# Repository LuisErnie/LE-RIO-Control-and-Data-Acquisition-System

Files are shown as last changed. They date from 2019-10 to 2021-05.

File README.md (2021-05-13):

# Industrial Control and Data Acquisition System

LOW-level Engineering modular data acquisition and control hardware platform. The system is a combination of a power supply, integrated I/O, integrated communications interfaces, signal and isolation to interface with expansion modules to tailor it to the application and an FPGA as a main controller.

The system is designed around the DE-10 Nano FPGA board from Terasic, although any embedded controller can be adapted to interface with the two 40-pin IDC connectors.

## Features
- Fully Modular I/O interface.
- Expansion Ports with 24V and 5V Power and Signal Isolation.
- Single 24V Power Supply Required.
- Multiple Communications Interfaces Supported, RS-485, CAN, RS-232, USB, SPI and I2C.

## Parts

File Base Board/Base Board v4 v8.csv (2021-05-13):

Qty | Value | Device | Package | Parts | Description | BUILT_BY | CATEGORY | COLOR | COPYRIGHT | CREATED_BY | DATASHEET | DATASHEET-URL | DESCRIPTION | DIGI-KEY_PART_NUMBER | DIGIKEY_PARTNO | DIGIKEY_PN | GENDER | HEIGHT | IR | IR-UL | IR-VDE | MANUFACTURER | MANUFACTURER_NAME | MANUFACTURER_PART_NUMBER | MATES | MF | MOUNT | MOUSER_PART_NUMBER | MP | MPN | OPERATING_TEMP | PACKAGE | PACKAGING | PART-NUMBER | PART_STATUS | PINS | PITCH | POPULARITY | PURCHASE-URL | RATING | ROHS_COMPLIANT | ROWS | SERIES | SOURCELIBRARY | SUB-CATEGORY | THERMALLOSS | TOLERANCE | TP_SIGNAL_NAME | TYPE | VALUE | VENDOR | VOLTAGE_RATING | WORKING-VOLTAGE-UL | WORKING-VOLTAGE-VDE
1 |  | 6130XX21821_61301621821 | 61301621821 | JP4 | WR-PHD 2.54 mm Dual Socket Header |  |  |  |  |  |  | https://katalog.we-online.com/em/datasheet/61301621821.pdf |  |  |  |  | Socket Header |  | 3A |  |  |  |  |  | WR-PHD 2.54mm SMT Dual Pin Header/THT Angled Dual Pin Header/THT Dual Board Stacker/THT Dual Pin Header |  |  |  |  |  |  |  | Tray | 61301621821 |  | 16 |  |  |  |  |  | Dual |  |  |  |  |  |  | Straight
1 |  | 6130XX21821_61302021821 | 61302021821 | JP5 | WR-PHD 2.54 mm Dual Socket Header |  |  |  |  |  |  | https://katalog.we-online.com/em/datasheet/61302021821.pdf |  |  |  |  | Socket Header |  | 3A |  |  |  |  |  | WR-PHD 2.54mm SMT Dual Pin Header/THT Angled Dual Pin Header/THT Dual Board Stacker/THT Dual Pin Header |  |  |  |  |  |  |  | Tray | 61302021821 |  | 20 |  |  |  |  |  | Dual |  |  |  |  |  |  | Straight
1 |  | 691313710002 | 691313710002 | J2 | WR-TBL Serie 3137 - 5.00 mm Close Horizontal PCB Header |  |  |  |  |  |  | https://www.we-online.com/catalog/datasheet/691313710002.pdf |  |  |  |  |  |  |  | 20A | 20A |  |  |  |  |  | THT |  |  |  |  |  |  | 691313710002 |  | 2 | 5mm |  |  |  |  |  |  |  |  |  |  |  | Horizontal |  |  |  | 300V (AC) | 300V (AC)
2 |  | PINHD-2X20 | 2X20 | JP1, JP2 | PIN HEADER |  |  |  |  |  |  |  |  |  |  |  |  |  |  |  |  |  |  |  |  |  |  |  |  |  |  |  |  |  |  |  |  | 12
1 |  | PINHD-2X22/90 | 2X22/90 | JP6 | PIN HEADER |  |  |  |  |  |  |  |  |  |  |  |  |  |  |  |  |  |  |  |  |  |  |  |  |  |  |  |  |  |  |  |  | 0
1 |  | TEL_5_SERIES | TEL_5_SERIES | IC2 | TRACO POWER DC/DC converter TEL 5 Series created by Mario Blunk - electronics & IT engineering at www.train-z.de
2 | 0.01uF | C-US_CHIP-0805(2012-METRIC) | CAPC2012X110 | C12, C14 | Capacitor - ANSI |  | Capacitor
17 | 0.1uF | C-US_CHIP-0805(2012-METRIC) | CAPC2012X110 | C4, C5, C6, C7, C8, C11, C13, C16, C17, C18, C19, C20, C21, C24, C25, C26, C27 | Capacitor - ANSI |  | Capacitor
1 | 01530008Z | 01530008Z | 01530008Z | F1 | FUSE HOLDER BLADE 32V 15A PCB |  |  |  |  | PCBLayout.com |  |  |  |  | F065-ND |  |  |  |  |  |  | Littelfuse Inc. |  |  |  |  |  |  |  | 01530008Z
10 | 10k | R-US_CHIP-0805(2012-METRIC) | RESC2012X65 | R2, R3, R4, R5, R6, R7, R8, R9, R10, R11 | Resistor Fixed - ANSI |  | Resistor |  |  |  |  |  |  |  |  |  |  |  |  |  |  |  |  |  |  |  |  |  |  |  |  |  |  |  |  |  |  |  |  |  |  |  |  |  | Fixed
1 | 11.8K | R-US_CHIP-0805(2012-METRIC) | RESC2012X65 | R1 | Resistor Fixed - ANSI |  | Resistor |  |  |  |  |  |  |  |  |  |  |  |  |  |  |  |  |  |  |  |  |  |  |  |  |  |  |  |  |  |  |  |  |  |  |  |  |  | Fixed
2 | 1uF | C-US_CHIP-0805(2012-METRIC) | CAPC2012X110 | C2, C3 | Capacitor - ANSI |  | Capacitor
1 | 2.2mF | C-US_CHIP-0805(2012-METRIC) | CAPC2012X110 | C1 | Capacitor - ANSI |  | Capacitor
2 | 22pF | C-US_CHIP-0805(2012-METRIC) | CAPC2012X110 | C9, C10 | Capacitor - ANSI |  | Capacitor
1 | 2k | R-US_CHIP-0805(2012-METRIC) | RESC2012X65 | R13 | Resistor Fixed - ANSI |  | Resistor |  |  |  |  |  |  |  |  |  |  |  |  |  |  |  |  |  |  |  |  |  |  |  |  |  |  |  |  |  |  |  |  |  |  |  |  |  | Fixed
1 | 5032/2P 16MHz | 5032/2P | 5032/2P | X1 | Crystal |  |  |  |  | PCBLayout.com |  |  |  |  |  |  |  |  |  |  |  | Xinhunjing |  |  |  |  |  |  |  | 5032/2P |  | SMD
2 | 50E | R-US_CHIP-0805(2012-METRIC) | RESC2012X65 | R14, R15 | Resistor Fixed - ANSI |  | Resistor |  |  |  |  |  |  |  |  |  |  |  |  |  |  |  |  |  |  |  |  |  |  |  |  |  |  |  |  |  |  |  |  |  |  |  |  |  | Fixed
1 | ADM3050E | ADM3050E | SOIC127P1031X265-8N | IC15
2 | ADUM1250 | ADUM1250 | SOIC127P600X175-8N | IC7, IC8
1 | ADUM140E | ADUM140E | SOP65P599X175-16N | IC11
2 | ADUM141E | ADUM141E | SOP65P599X175-16N | IC9, IC10
2 | ADUM3153 | ADUM3153 | SOP65P780X200-20N | IC5, IC6
1 | BS-7 | BS-7 | BAT_BS-7 | BT1 | BATTERY HOLDER COIN 20MM PC PIN |  |  |  |  |  |  |  | BATTERY HOLDER COIN 20MM PC PIN | BS-7-ND |  |  |  |  |  |  |  |  |  |  |  | MPD (Memory |  |  | BS-7 |  |  | None |  |  |  |  |  |  | https://pricing.snapeda.com/search/part/BS-7/?ref=eda
1 | DS3231 | DS3231 | SOIC127P1032X265-16N | IC4
2 | G6L-1F-TRDC12 | G6L-1F-TRDC12 | G6L-1F-TRDC12 | K1, K2 | RELAY TELECOM SPST 1A 12VDC |  |  |  |  | PCBLayout.com |  |  |  |  |  | Z3549TR-ND |  |  |  |  |  | Omron Electronics Inc-EMC Div |  |  |  |  |  |  |  | G6L-1F-TRDC12
1 | MCP2518FD | MCP2518FD | SOIC127P600X175-14N | IC1
4 | MOUNT-PAD-ROUND3.2 | MOUNT-PAD-ROUND3.2 | 3,2-PAD | H1, H2, H3, H4 | MOUNTING PAD, round |  |  |  |  |  |  |  |  |  |  |  |  |  |  |  |  |  |  |  |  |  |  |  |  |  |  |  |  |  |  |  |  | 4
1 | PESD1CAN | PESD1CAN | SOT23 | D1 | CAN bus ESD protection diode |  |  |  |  |  |  |  |  |  |  |  |  |  |  |  |  |  |  |  |  |  |  |  |  |  |  |  |  |  |  |  |  | 0
1 | R_0805 | CHIP-ROUND-R_0805 | LEDC2012X105N_RND-R | D10 | LED - Generic |  | LED | RED |  |  |  |  | CHIP LED ROUND |  |  |  |  |  |  |  |  |  |  |  |  |  |  |  |  |  |  |  |  |  |  |  |  |  |  |  |  |  |  |  | CHIP |  |  |  | ROUND_TOP
1 | TL2285EE | TL2285EE | TL2285EE | S1 | Tactile Switches DPDT ALT ACT PC MNT |  |  |  |  |  |  |  | Tactile Switches DPDT ALT ACT PC MNT |  |  |  |  | 13mm |  |  |  |  | E-Switch | TL2285EE |  |  |  | 612-TL2285EE
73 | TPB1,27 | TPB1,27 | B1,27 | 3V3, 5V, 5V_IN, 24V, 24V_IN, A_CLK_ISO, A_CS_ISO, A_CS_MUX_A_ISO, A_CS_MUX_B_ISO, A_CS_MUX_C_ISO, A_MISO_ISO, A_MOSI_ISO, BAT, B_CLK_ISO, B_CS_ISO, B_CS_MUX_A_ISO, B_CS_MUX_B_ISO, B_CS_MUX_C_ISO, B_MISO_ISO, B_MOSI_ISO, CAN_H, CAN_L, CAN_RX, CAN_TX, CTRL_A_ISO, CTRL_B_ISO, CTRL_C_ISO, CTRL_D_ISO, EE_SCL, EE_SCL_ISO, EE_SDA, EE_SDA_ISO, FAULT_A_ISO, FAULT_B_ISO, FAULT_C_ISO, GND, GNDA, GND_BAT, INT_A_ISO, INT_B_ISO, INT_C_ISO, RTC_SCL, RTC_SDA, SCL, SCL_ISO, SDA, SDA_ISO, SPIA_CLK, SPIA_CS, SPIA_CS_MUX_A, SPIA_CS_MUX_B, SPIA_CS_MUX_C, SPIA_MISO, SPIA_MOSI, SPIB_CLK, SPIB_CS, SPIB_CS_MUX_A, SPIB_CS_MUX_B, SPIB_CS_MUX_C, SPIB_MISO, SPIB_MOSI, SPI_BUS_CTRL_A, SPI_BUS_CTRL_B, SPI_BUS_CTRL_C, SPI_BUS_CTRL_D, SPI_FAULT_A, SPI_FAULT_B, SPI_FAULT_C, SPI_INT_A, SPI_INT_B, SPI_INT_C, VCC, VDD | Test pad |  |  |  |  |  |  |  |  |  |  |  |  |  |  |  |  |  |  |  |  |  |  |  |  |  |  |  |  |  |  |  |  | 19
1 | TPS26600 | TPS26600 | SOP65P640X120-17T266X246N | IC3
1 | TSR_2-2450 | TSR_2-2450 | TSR2-SINGLE_TRP | IC16 |  | EMA_Justin |  |  | Copyright (C) 2018 Accelerated Designs. All rights reserved |  | https://www.tracopower.com/products/tsr2.pdf |  |  |  |  |  |  |  |  |  |  |  |  | TSR 2-2450 |  |  |  |  |  |  |  |  |  |  |  |  |  |  |  |  |  |  |  | Traco_Power_2020-06-03 |  |  |  |  |  |  | Traco Power

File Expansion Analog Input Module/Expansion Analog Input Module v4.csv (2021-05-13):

Qty | Value | Device | Package | Parts | Description | BREAKDOWN_VOLTAGE | CATEGORY | CLAMPING_VOLTAGE | COLOR | CURRENT_RATING | DATASHEET-URL | DESCRIPTION | IR-UL | MANUFACTURER | MOUNT | MPN | OPERATING_TEMP | PART-NUMBER | PART_STATUS | PINS | PITCH | POLES | POPULARITY | QTY | RATING | ROHS_COMPLIANT | SERIES | SUB-CATEGORY | THERMALLOSS | TOLERANCE | TP_SIGNAL_NAME | TYPE | VALUE | VOLTAGE_RATING | WIRE | WORKING-VOLTAGE-UL
1 |  | 418121270802 | 418121270802 | S1 | WS-DISV Small Compact SMT with Raised Actuator 2.54 mm |  |  |  |  |  | https://www.we-online.com/catalog/datasheet/418121270802.pdf |  |  |  |  |  |  | 418121270802 |  | 2 |  |  |  | 800
3 |  | 691402910002B | 691402910002B | J3, J4, J5 | WR-TBL Serie 4029 - 2.54 mm Screwless Horizontal Entry |  |  |  |  |  | https://www.we-online.com/catalog/datasheet/691402910002B.pdf |  | 6A |  | THT |  |  | 691402910002B |  | 2 | 2.54mm |  |  |  |  |  |  |  |  |  |  | Horizontal |  |  | 20 to 26 (AWG) 0.518 to 0.129 (mm²) | 150V (AC)
1 |  | 691402910008B | 691402910008B | J2 | WR-TBL Serie 4029 - 2.54 mm Screwless Horizontal Entry |  |  |  |  |  | https://www.we-online.com/catalog/datasheet/691402910008B.pdf |  | 6A |  | THT |  |  | 691402910008B |  | 8 | 2.54mm |  |  |  |  |  |  |  |  |  |  | Horizontal |  |  | 20 to 26 (AWG) 0.518 to 0.129 (mm²) | 150V (AC)
1 |  | WE-D-SUB_THT90_EC_214112013 | WE-D-SUB_THT90_EC_214112013 | J1 | WE-D-SUB Filter Bent 90° THT |  |  |  |  |  | https://katalog.we-online.de/pbs/datasheet/214112013.pdf |  |  |  | THT |  |  | 214112013 |  |  |  | 25 |  |  |  |  |  |  |  |  |  | Male
2 | 0.1uF | C-US_CHIP-0805(2012-METRIC) | CAPC2012X110 | C1, C6 | Capacitor - ANSI |  | Capacitor
1 | 10k | R-US_CHIP-0805(2012-METRIC) | RESC2012X65 | R9 | Resistor Fixed - ANSI |  | Resistor |  |  |  |  |  |  |  |  |  |  |  |  |  |  |  |  |  |  |  |  | Fixed
1 | 1uF | C-US_CHIP-0805(2012-METRIC) | CAPC2012X110 | C2 | Capacitor - ANSI |  | Capacitor
1 | 24LC512TSSOP | 24LC512TSSOP | SOP65P640X120-8N | IC3
1 | 2k | R-US_CHIP-0805(2012-METRIC) | RESC2012X65 | R10 | Resistor Fixed - ANSI |  | Resistor |  |  |  |  |  |  |  |  |  |  |  |  |  |  |  |  |  |  |  |  | Fixed
8 | 4.7K | R-US_CHIP-0805(2012-METRIC) | RESC2012X65 | R1, R2, R3, R4, R5, R6, R7, R8 | Resistor Fixed - ANSI |  | Resistor |  |  |  |  |  |  |  |  |  |  |  |  |  |  |  |  |  |  |  |  | Fixed
8 | 680nF | C-US_CHIP-0805(2012-METRIC) | CAPC2012X110 | C9, C10, C11, C12, C13, C14, C15, C16 | Capacitor - ANSI |  | Capacitor
8 | FUSE | FUSE_CHIP-1206(3216-METRIC) | FUSC3215X82N | F1, F2, F3, F4, F5, F6, F7, F8 | Fuse - Generic |  | Circuit-Protection |  |  |  |  |  |  |  |  |  |  |  |  |  |  |  |  |  |  |  |  | Fuse |  |  |  |  | FUSE
1 | MCP3208 | MCP3208 | SOIC127P590X175-16N | IC1
1 | MCP4822 | MCP4822 | SOIC127P600X175-8N | IC2
2 | R_0805 | CHIP-ROUND-R_0805 | LEDC2012X105N_RND-R | D9, D10 | LED - Generic |  | LED |  | RED |  |  | CHIP LED ROUND |  |  |  |  |  |  |  |  |  |  |  |  |  |  |  | CHIP |  |  |  | ROUND_TOP
21 | TPB1,27 | TPB1,27 | B1,27 | 5V, 24V, GND, IN_1, IN_1_F, IN_2, IN_2_F, IN_3, IN_3_F, IN_4, IN_4_F, IN_5, IN_5_F, IN_6, IN_6_F, IN_7, IN_7_F, IN_8, IN_8_F, VOUT_A, VOUT_B | Test pad |  |  |  |  |  |  |  |  |  |  |  |  |  |  |  |  |  | 19
8 | TVS-DIODE | TVS_DO-214AC(SMA) | DIOM5226X290N | D1, D2, D3, D4, D5, D6, D7, D8 | TVS Diode - Generic |  | Circuit-Protection |  |  |  |  |  |  |  |  |  |  |  |  |  |  |  |  |  |  |  |  | TVS-Diode |  |  |  |  | TVS-DIODE

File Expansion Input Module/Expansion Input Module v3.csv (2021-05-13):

Qty | Value | Device | Package | Parts | Description | BREAKDOWN_VOLTAGE | CATEGORY | CLAMPING_VOLTAGE | COLOR | CURRENT_RATING | DATASHEET-URL | DESCRIPTION | IR-UL | MANUFACTURER | MOUNT | MPN | OPERATING_TEMP | PART-NUMBER | PART_STATUS | PINS | PITCH | POLES | POPULARITY | QTY | RATING | ROHS_COMPLIANT | SERIES | SUB-CATEGORY | THERMALLOSS | TOLERANCE | TP_SIGNAL_NAME | TYPE | VALUE | VOLTAGE_RATING | WIRE | WORKING-VOLTAGE-UL
1 |  | 418121270803 | 418121270803 | S1 | WS-DISV Small Compact SMT with Raised Actuator 2.54 mm |  |  |  |  |  | https://www.we-online.com/catalog/datasheet/418121270803.pdf |  |  |  |  |  |  | 418121270803 |  | 3 |  |  |  | 800
2 |  | 691402910002B | 691402910002B | J3, J4 | WR-TBL Serie 4029 - 2.54 mm Screwless Horizontal Entry |  |  |  |  |  | https://www.we-online.com/catalog/datasheet/691402910002B.pdf |  | 6A |  | THT |  |  | 691402910002B |  | 2 | 2.54mm |  |  |  |  |  |  |  |  |  |  | Horizontal |  |  | 20 to 26 (AWG) 0.518 to 0.129 (mm²) | 150V (AC)
1 |  | 691402910008B | 691402910008B | J2 | WR-TBL Serie 4029 - 2.54 mm Screwless Horizontal Entry |  |  |  |  |  | https://www.we-online.com/catalog/datasheet/691402910008B.pdf |  | 6A |  | THT |  |  | 691402910008B |  | 8 | 2.54mm |  |  |  |  |  |  |  |  |  |  | Horizontal |  |  | 20 to 26 (AWG) 0.518 to 0.129 (mm²) | 150V (AC)
3 |  | R-US_CHIP-0805(2012-METRIC) | RESC2012X65 | R9, R10, R11 | Resistor Fixed - ANSI |  | Resistor |  |  |  |  |  |  |  |  |  |  |  |  |  |  |  |  |  |  |  |  | Fixed
1 |  | WE-D-SUB_THT90_EC_214112013 | WE-D-SUB_THT90_EC_214112013 | J1 | WE-D-SUB Filter Bent 90° THT |  |  |  |  |  | https://katalog.we-online.de/pbs/datasheet/214112013.pdf |  |  |  | THT |  |  | 214112013 |  |  |  | 25 |  |  |  |  |  |  |  |  |  | Male
1 | 0.1uF | C-US_CHIP-0805(2012-METRIC) | CAPC2012X110 | C6 | Capacitor - ANSI |  | Capacitor
1 | 10k | R-US_CHIP-0805(2012-METRIC) | RESC2012X65 | R14 | Resistor Fixed - ANSI |  | Resistor |  |  |  |  |  |  |  |  |  |  |  |  |  |  |  |  |  |  |  |  | Fixed
1 | 24LC512TSSOP | 24LC512TSSOP | SOP65P640X120-8N | IC2
9 | 2k | R-US_CHIP-0805(2012-METRIC) | RESC2012X65 | R15, R16, R17, R18, R19, R20, R21, R22, R23 | Resistor Fixed - ANSI |  | Resistor |  |  |  |  |  |  |  |  |  |  |  |  |  |  |  |  |  |  |  |  | Fixed
8 | 4.7K | R-US_CHIP-0805(2012-METRIC) | RESC2012X65 | R1, R2, R3, R4, R5, R6, R7, R8 | Resistor Fixed - ANSI |  | Resistor |  |  |  |  |  |  |  |  |  |  |  |  |  |  |  |  |  |  |  |  | Fixed
8 | 680nF | C-US_CHIP-0805(2012-METRIC) | CAPC2012X110 | C9, C10, C11, C12, C13, C14, C15, C16 | Capacitor - ANSI |  | Capacitor
2 | CRA034RF | CRA034RF | RESCAXS80P320X160X60-8N | R12, R13
8 | FUSE | FUSE_CHIP-1206(3216-METRIC) | FUSC3215X82N | F1, F2, F3, F4, F5, F6, F7, F8 | Fuse - Generic |  | Circuit-Protection |  |  |  |  |  |  |  |  |  |  |  |  |  |  |  |  |  |  |  |  | Fuse |  |  |  |  | FUSE
1 | MCP23S17 | MCP23S17 | SOP65P780X200-28N | IC1
10 | R_0805 | CHIP-ROUND-R_0805 | LEDC2012X105N_RND-R | D9, D10, D11, D12, D13, D14, D15, D16, D17, D18 | LED - Generic |  | LED |  | RED |  |  | CHIP LED ROUND |  |  |  |  |  |  |  |  |  |  |  |  |  |  |  | CHIP |  |  |  | ROUND_TOP
19 | TPB1,27 | TPB1,27 | B1,27 | 5V, 24V, GND, IN_1, IN_1_F, IN_2, IN_2_F, IN_3, IN_3_F, IN_4, IN_4_F, IN_5, IN_5_F, IN_6, IN_6_F, IN_7, IN_7_F, IN_8, IN_8_F | Test pad |  |  |  |  |  |  |  |  |  |  |  |  |  |  |  |  |  | 19
8 | TVS-DIODE | TVS_DO-214AC(SMA) | DIOM5226X290N | D1, D2, D3, D4, D5, D6, D7, D8 | TVS Diode - Generic |  | Circuit-Protection |  |  |  |  |  |  |  |  |  |  |  |  |  |  |  |  |  |  |  |  | TVS-Diode |  |  |  |  | TVS-DIODE

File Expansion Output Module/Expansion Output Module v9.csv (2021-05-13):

Qty | Value | Device | Package | Parts | Description | CATEGORY | COLOR | DATASHEET-URL | DESCRIPTION | IR-UL | MANUFACTURER | MOUNT | MPN | OPERATING_TEMP | PART-NUMBER | PART_STATUS | PINS | PITCH | POLES | POPULARITY | QTY | RATING | ROHS_COMPLIANT | SERIES | SUB-CATEGORY | THERMALLOSS | TOLERANCE | TP_SIGNAL_NAME | TYPE | VALUE | VOLTAGE_RATING | WIRE | WORKING-VOLTAGE-UL
1 |  | 418121270803 | 418121270803 | IC1 | WS-DISV Small Compact SMT with Raised Actuator 2.54 mm |  |  | https://www.we-online.com/catalog/datasheet/418121270803.pdf |  |  |  |  |  |  | 418121270803 |  | 3 |  |  |  | 800
2 |  | 691402910002B | 691402910002B | J5, J6 | WR-TBL Serie 4029 - 2.54 mm Screwless Horizontal Entry |  |  | https://www.we-online.com/catalog/datasheet/691402910002B.pdf |  | 6A |  | THT |  |  | 691402910002B |  | 2 | 2.54mm |  |  |  |  |  |  |  |  |  |  | Horizontal |  |  | 20 to 26 (AWG) 0.518 to 0.129 (mm²) | 150V (AC)
2 |  | 691402910008B | 691402910008B | J1, J2 | WR-TBL Serie 4029 - 2.54 mm Screwless Horizontal Entry |  |  | https://www.we-online.com/catalog/datasheet/691402910008B.pdf |  | 6A |  | THT |  |  | 691402910008B |  | 8 | 2.54mm |  |  |  |  |  |  |  |  |  |  | Horizontal |  |  | 20 to 26 (AWG) 0.518 to 0.129 (mm²) | 150V (AC)
1 |  | WE-D-SUB_THT90_EC_214112013 | WE-D-SUB_THT90_EC_214112013 | J3 | WE-D-SUB Filter Bent 90° THT |  |  | https://katalog.we-online.de/pbs/datasheet/214112013.pdf |  |  |  | THT |  |  | 214112013 |  |  |  | 25 |  |  |  |  |  |  |  |  |  | Male
1 | 0.1uF | C-US_CHIP-0805(2012-METRIC) | CAPC2012X110 | C6 | Capacitor - ANSI | Capacitor
4 | 10k | R-US_CHIP-0805(2012-METRIC) | RESC2012X65 | R1, R9, R10, R11 | Resistor Fixed - ANSI | Resistor |  |  |  |  |  |  |  |  |  |  |  |  |  |  |  |  |  |  | Fixed
1 | 24LC512TSSOP | 24LC512TSSOP | SOP65P640X120-8N | IC4
9 | 2k | R-US_CHIP-0805(2012-METRIC) | RESC2012X65 | R2, R3, R4, R5, R6, R7, R8, R14, R15 | Resistor Fixed - ANSI | Resistor |  |  |  |  |  |  |  |  |  |  |  |  |  |  |  |  |  |  | Fixed
2 | CRA034RF | CRA034RF | RESCAXS80P320X160X60-8N | R12, R13
1 | MCP23S17 | MCP23S17 | SOP65P780X200-28N | IC2
8 | PE10 | PE10 | PE-FORM-A | K1, K2, K3, K4, K5, K6, K7, K8 | SLIM POWER Relay NAiS
10 | R_0805 | CHIP-ROUND-R_0805 | LEDC2012X105N_RND-R | D1, D2, D3, D4, D5, D6, D7, D8, D9, D10 | LED - Generic | LED | RED |  | CHIP LED ROUND |  |  |  |  |  |  |  |  |  |  |  |  |  |  |  | CHIP |  |  |  | ROUND_TOP
11 | TPB1,27 | TPB1,27 | B1,27 | 5V, 24V, GND, OUT_1, OUT_2, OUT_3, OUT_4, OUT_5, OUT_6, OUT_7, OUT_8 | Test pad |  |  |  |  |  |  |  |  |  |  |  |  |  |  | 19
1 | ULN2803 | ULN2803 | SOIC127P1030X265-18N | IC5

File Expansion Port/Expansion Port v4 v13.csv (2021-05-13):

Qty | Value | Device | Package | Parts | Description | CATEGORY | COLOR | CRAETED_BY | DATASHEET-URL | DESCRIPTION | DIGIKEY_PART_NUMBER | MANUFACTURER | MOUNT | MPN | OPERATING_TEMP | PACKAGE | PART-NUMBER | PART_STATUS | POLES | POPULARITY | RATING | ROHS_COMPLIANT | SERIES | SUB-CATEGORY | THERMALLOSS | TOLERANCE | TP_SIGNAL_NAME | TYPE | VALUE | VOLTAGE_RATING
1 |  | PINHD-2X222X22/90 | HDRRAR44W64P254_2X22_5588X736X556B | JP1 | WR-PHD 2.54 mm Dual Socket Header
1 |  | PINHD-2X3 | 2X03 | JP2 | PIN HEADER |  |  |  |  |  |  |  |  |  |  |  |  |  |  | 62
8 |  | WE-D-SUB_THT_TH_214611003 | WE-D-SUB_THT_TH_214611003 | J1, J2, J3, J4, J5, J6, J7, J8 | WE-D-SUB Filter Solder Pin Straight |  |  |  | https://katalog.we-online.de/pbs/datasheet/214611003.pdf |  |  |  | THT |  |  |  | 214611003 |  | 25 |  |  |  |  |  |  |  |  | Female
22 | 0.1uF | C-US_CHIP-0805(2012-METRIC) | CAPC2012X110 | C1, C2, C4, C5, C6, C7, C8, C9, C10, C11, C12, C13, C14, C15, C16, C17, C18, C19, C20, C21, C22, C23 | Capacitor - ANSI | Capacitor
2 | 10k | R-US_CHIP-0805(2012-METRIC) | RESC2012X65 | R9, R10 | Resistor Fixed - ANSI | Resistor |  |  |  |  |  |  |  |  |  |  |  |  |  |  |  |  |  | Fixed
8 | 2.2K | R-US_CHIP-0805(2012-METRIC) | RESC2012X65 | R1, R2, R3, R4, R5, R6, R7, R8 | Resistor Fixed - ANSI | Resistor |  |  |  |  |  |  |  |  |  |  |  |  |  |  |  |  |  | Fixed
1 | 2k | R-US_CHIP-0805(2012-METRIC) | RESC2012X65 | R11 | Resistor Fixed - ANSI | Resistor |  |  |  |  |  |  |  |  |  |  |  |  |  |  |  |  |  | Fixed
1 | 4700pF | C-US_CHIP-0805(2012-METRIC) | CAPC2012X110 | C3 | Capacitor - ANSI | Capacitor
2 | 60.4 | R-US_CHIP-0805(2012-METRIC) | RESC2012X65 | R12, R13 | Resistor Fixed - ANSI | Resistor |  |  |  |  |  |  |  |  |  |  |  |  |  |  |  |  |  | Fixed
1 | 7B-16.000MAAJ-T | 7B-16.000MAAJ-T | 7B-16.000MAAJ-T | X1 | CRYSTAL 16.0000MHZ 18PF SMD |  |  | PCBLayout.com |  |  | 887-1104-2-ND | TXC CORPORATION |  | 7B-16.000MAAJ-T |  | SMD 4
1 | ATMEGA1284P | ATMEGA1284P | QFP80P1200X1200X120-44N | IC12
8 | CD4543 | CD4543 | SOP65P640X120-16N | IC4, IC5, IC6, IC7, IC8, IC9, IC10, IC11
2 | CD74HC4051 | CD74HC4051 | SOP65P640X120-16N | IC15, IC16
8 | HD-F103 | HD-F103 | HDSP-E | DIS1, DIS2, DIS3, DIS4, DIS5, DIS6, DIS7, DIS8 | LED DISPLAY
6 | MOUNT-PAD-ROUND3.2 | MOUNT-PAD-ROUND3.2 | 3,2-PAD | H1, H2, H3, H4, H5, H6 | MOUNTING PAD, round |  |  |  |  |  |  |  |  |  |  |  |  |  |  | 4
1 | PESD1CAN | PESD1CAN | SOT23 | D1 | CAN bus ESD protection diode |  |  |  |  |  |  |  |  |  |  |  |  |  |  | 0
2 | R_0805 | CHIP-ROUND-R_0805 | LEDC2012X105N_RND-R | D9, D10 | LED - Generic | LED | RED |  |  | CHIP LED ROUND |  |  |  |  |  |  |  |  |  |  |  |  |  | CHIP |  |  |  | ROUND_TOP
8 | SN74CBTLV3257 | SN74CBTLV3257 | SOP65P640X120-16N | IC17, IC18, IC19, IC20, IC21, IC22, IC23, IC24
3 | SN74LVC1G04SOT65 | SN74LVC1G04SOT65 | SOT65P210X110-5N | IC1, IC2, IC3
8 | SN74LVC1G11 | SN74LVC1G11 | SOP65P210X110-6N | IC33, IC34, IC35, IC36, IC37, IC38, IC39, IC40
8 | SN74LVC1G373 | SN74LVC1G373 | SOP65P210X110-6N | IC25, IC26, IC27, IC28, IC29, IC30, IC31, IC32
54 | TPB1,27 | TPB1,27 | B1,27 | +5V_1, +5V_2, +5V_3, +5V_4, +5V_5, +5V_6, +5V_7, +5V_8, +24V_1, +24V_2, +24V_3, +24V_4, +24V_5, +24V_6, +24V_7, +24V_8, CAN_H, CAN_N, EEPROMMS_SCL, EEPROMMS_SDA, GND_1, GND_2, GND_3, GND_4, GND_5, GND_6, GND_7, GND_8, SCL, SDA, SPIA_CLK, SPIA_CS, SPIA_CS_MUX_A, SPIA_CS_MUX_B, SPIA_CS_MUX_C, SPIA_MISO, SPIA_MOSI, SPIB_CLK, SPIB_CS, SPIB_CS_MUX_A, SPIB_CS_MUX_B, SPIB_CS_MUX_C, SPIB_MISO, SPIB_MOSI, SPI_BUS_CTRL_A, SPI_BUS_CTRL_B, SPI_BUS_CTRL_C, SPI_BUS_CTRL_D, SPI_FAULT_A, SPI_FAULT_B, SPI_FAULT_C, SPI_INT_A, SPI_INT_B, SPI_INT_C | Test pad |  |  |  |  |  |  |  |  |  |  |  |  |  |  | 19

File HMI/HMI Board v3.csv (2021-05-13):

Qty | Value | Device | Package | Parts | Description | CATEGORY | COLOR | CREATED_BY | DESCRIPTION | DIGIKEY_PARTNO | MANUFACTURER | MPN | OPERATING_TEMP | OPERATING_TEMPERATURE | PART_STATUS | POPULARITY | RATING | ROHS_COMPLIANCE | ROHS_COMPLIANT | SERIES | SF_ID | SUB-CATEGORY | THERMALLOSS | TOLERANCE | TYPE | VALUE | VOLTAGE_RATING
2 |  | C-US_CHIP-0805(2012-METRIC) | CAPC2012X110 | C4, C5 | Capacitor - ANSI | Capacitor
3 |  | CHIP-ROUND-R_0805 | LEDC2012X105N_RND-R | LED1, LED5, LED6 | LED - Generic | LED | RED |  | CHIP LED ROUND |  |  |  |  |  |  |  |  |  |  |  |  | CHIP |  |  | ROUND_TOP
1 |  | JP1E | JP1 | JP1 | JUMPER |  |  |  |  |  |  |  |  |  |  | 61
1 |  | PV36P | PV36P | R1 | Rectangular Trimmer Potentiometers - PV36 Series | Resistor |  |  | Lead Sealed Type Multiturn PV36 Series |  | BOURNS | PV36P |  | -55 to +125 °C | Active |  |  | RoHS Compliant |  | PV36 |  | Trimpot |  |  | Lead Sealed
7 |  | R-US_CHIP-0805(2012-METRIC) | RESC2012X65 | R7, R8, R11, R12, R13, R14, R20 | Resistor Fixed - ANSI | Resistor |  |  |  |  |  |  |  |  |  |  |  |  |  |  |  | Fixed
1 | ARDUINOR3NODIM | ARDUINOR3NODIM | ARDUINOR3-NODIM | U1 | This is a new object for the new Arduino R3 - with extra pins that you may want to use (such as IOref, and duplicated A4/A5
1 | LCD-16X28X2 | LCD-16X28X2 | LCD-8X2 | LCD1 | Standard text-only 16x2 parallel input LCD |  |  |  |  |  |  |  |  |  |  |  |  |  |  |  | LCD-11122
1 | PEC11R-4215K-S0024 | PEC11R-4215K-S0024 | PEC11R-4215K-S0024 | EN1 | ROTARY ENCODER MECHANICAL 24PPR |  |  | PCBLayout.com |  | PEC11R-4215K-S0024-ND | Bourns Inc. | PEC11R-4215K-S0024

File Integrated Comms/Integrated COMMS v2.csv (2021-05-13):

Qty | Value | Device | Package | Parts | Description | APPLICATION | CATEGORY | COLOR | CREATED_BY | DATA-RATE | DATASHEET-URL | DESCRIPTION | FILTER_TYPE | FORWARD_CURRENT | GENDER | GERDER | IMPEDANCE_FREQ | INTERFACE-TYPE | IR1 | LED | MANUFACTURER | MATES-WITH | MOUNT | MPN | OPERATING_TEMP | PACKAGE | PACKAGING | PART-NUMBER | PART_STATUS | PINS | POE | POPULARITY | PORTS | QTY | RATING | REVERSE_VOLTAGE | ROHS_COMPLIANT | SERIES | SUB-CATEGORY | THERMALLOSS | TOLERANCE | TP_SIGNAL_NAME | TYPE | USB | VALUE | VOLTAGE_RATING | WE-NUMBER | WORKING-VOLTAGE
1 |  | 418217270904A | 418217270904A | S1 | WS-DITU Compact THT Right Angled with Raised Actuator 2.54 mm |  |  |  |  |  | https://www.we-online.com/catalog/datasheet/418217270904A.pdf |  |  |  |  |  |  |  |  |  |  |  |  |  |  |  |  | 418217270904A |  | 4 |  |  |  | 44
1 |  | 6180XX211721_618009211721 | 618009211721 | J1 | WR-DSUB 8.08 mm Male Angled PCB Connector w/o Hex Screw |  |  |  |  |  | https://www.we-online.com/catalog/datasheet/618009211721.pdf |  |  |  | Male |  |  |  |  |  |  | WR-DSUB 10.30 mm Female Angled PCB Connector w. Hex Screw and w/o Hex/ Screw/8.08 mm Female Angled PCB Connector w. Hex Screw and w/o Hex/ Screw/Female IDC/Female PCB Connector w. Hex Screw/Female Solder Bucket |  |  |  |  |  | 618009211721 |  | 9 |  |  |  |  |  |  |  |  |  |  |  |  | Angled |  |  |  | 618009211721
2 |  | CHIP-ROUND-R_0805 | LEDC2012X105N_RND-R | D2, D3 | LED - Generic |  | LED | RED |  |  |  | CHIP LED ROUND |  |  |  |  |  |  |  |  |  |  |  |  |  |  |  |  |  |  |  |  |  |  |  |  |  |  | CHIP |  |  |  | ROUND_TOP
4 |  | PINHD-1X2 | 1X02 | JP2, JP3, JP4, JP5 | PIN HEADER |  |  |  |  |  |  |  |  |  |  |  |  |  |  |  |  |  |  |  |  |  |  |  |  |  |  | 98
1 |  | PINHD-2X8/90 | 2X08/90 | JP1 | PIN HEADER |  |  |  |  |  |  |  |  |  |  |  |  |  |  |  |  |  |  |  |  |  |  |  |  |  |  | 0
2 |  | WE-RJ45_74980104400 | 74980104400 | T1, T2 | WE-RJ45 LAN Through Hole Reflow |  |  |  |  | 10/100 Base-T | https://www.we-online.com/catalog/datasheet/74980104400.pdf |  |  |  |  |  |  |  |  | green/yellow-green/yellow |  |  | THR |  |  |  |  | 74980104400 |  |  | non-PoE |  | 1 |  |  |  |  |  |  |  |  |  |  | No
2 | 0.01uF | C-US_CHIP-0805(2012-METRIC) | CAPC2012X110 | C12, C14 | Capacitor - ANSI |  | Capacitor
13 | 0.1uF | C-US_CHIP-0805(2012-METRIC) | CAPC2012X110 | C1, C2, C3, C4, C5, C6, C7, C8, C11, C13, C18, C20, C21 | Capacitor - ANSI |  | Capacitor
4 | 1.2K | R-US_CHIP-0805(2012-METRIC) | RESC2012X65 | R2, R3, R5, R6 | Resistor Fixed - ANSI |  | Resistor |  |  |  |  |  |  |  |  |  |  |  |  |  |  |  |  |  |  |  |  |  |  |  |  |  |  |  |  |  |  |  | Fixed
1 | 10k | R-US_CHIP-0805(2012-METRIC) | RESC2012X65 | R1 | Resistor Fixed - ANSI |  | Resistor |  |  |  |  |  |  |  |  |  |  |  |  |  |  |  |  |  |  |  |  |  |  |  |  |  |  |  |  |  |  |  | Fixed
3 | 10nF | C-US_CHIP-0805(2012-METRIC) | CAPC2012X110 | C16, C17, C19 | Capacitor - ANSI |  | Capacitor
1 | 10uF | C-US_CHIP-0805(2012-METRIC) | CAPC2012X110 | C22 | Capacitor - ANSI |  | Capacitor
2 | 120E | R-US_CHIP-0805(2012-METRIC) | RESC2012X65 | R4, R9 | Resistor Fixed - ANSI |  | Resistor |  |  |  |  |  |  |  |  |  |  |  |  |  |  |  |  |  |  |  |  |  |  |  |  |  |  |  |  |  |  |  | Fixed
2 | 1K | R-US_CHIP-0805(2012-METRIC) | RESC2012X65 | R7, R8 | Resistor Fixed - ANSI |  | Resistor |  |  |  |  |  |  |  |  |  |  |  |  |  |  |  |  |  |  |  |  |  |  |  |  |  |  |  |  |  |  |  | Fixed
2 | 22pF | C-US_CHIP-0805(2012-METRIC) | CAPC2012X110 | C9, C10 | Capacitor - ANSI |  | Capacitor
1 | 2k | R-US_CHIP-0805(2012-METRIC) | RESC2012X65 | R12 | Resistor Fixed - ANSI |  | Resistor |  |  |  |  |  |  |  |  |  |  |  |  |  |  |  |  |  |  |  |  |  |  |  |  |  |  |  |  |  |  |  | Fixed
1 | 4700pF | C-US_CHIP-0805(2012-METRIC) | CAPC2012X110 | C23 | Capacitor - ANSI |  | Capacitor
1 | 5032/2P 16MHz | 5032/2P | 5032/2P | X1 | Crystal |  |  |  | PCBLayout.com |  |  |  |  |  |  |  |  |  |  |  | Xinhunjing |  |  | 5032/2P |  | SMD
2 | 60.4 | R-US_CHIP-0805(2012-METRIC) | RESC2012X65 | R10, R11 | Resistor Fixed - ANSI |  | Resistor |  |  |  |  |  |  |  |  |  |  |  |  |  |  |  |  |  |  |  |  |  |  |  |  |  |  |  |  |  |  |  | Fixed
1 | 61410416121R | 61410416121R | 61410416121R | J2 | WR-COM USB 2.0 Type B Horizontal THR | USB 2.0 |  |  |  |  | https://www.we-online.com/catalog/datasheet/61410416121R.pdf |  |  |  |  | Receptacle |  | Type B | 1.5A |  |  |  | THR |  |  |  | Tape and Reel | 61410416121R |  | 4 |  |  |  |  |  |  |  |  |  |  |  |  | Horizontal |  | 61410416121R |  |  | 30V(AC)
1 | ADM2587E | ADM2587E | SOIC127P1032X265-20N | IC2
1 | ADM3050E | ADM3050E | SOIC127P1031X265-8N | IC6
1 | ADM3251E | ADM3251E | SOIC127P1032X265-20N | IC1
2 | FERRITE_BEAD 2.2K 100MHz | FBCHIP-0805(2012-METRIC) | BEADC2012X105N | FB1, FB2 | Ferrite Bead - Generic |  | Filter |  |  |  |  |  |  |  |  |  |  |  |  |  |  |  |  |  |  |  |  |  |  |  |  |  |  |  |  |  |  |  | Ferrite bead |  |  |  |  |  | FERRITE_BEAD
1 | FT232RL | FT232RL_SSOP | SSOP28 | IC7 | USB Bridge, USB to UART USB 2.0 UART Interface |  | IC_Interface |  |  |  |  |  |  |  |  |  |  |  |  |  | FTDI Chip |  |  | FT232RL | -40 to 85°C |  |  |  | Active |  |  |  |  |  |  |  | Compliant |  | Controller | 0.5W |  |  | USB to UART |  | FT232RL
1 | MCP2518FD | MCP2518FD | SOIC127P600X175-14N | IC5
1 | PESD1CAN | PESD1CAN | SOT23 | D1 | CAN bus ESD protection diode |  |  |  |  |  |  |  |  |  |  |  |  |  |  |  |  |  |  |  |  |  |  |  |  |  |  | 0
2 | R_0805 | CHIP-ROUND-R_0805 | LEDC2012X105N_RND-R | D9, D10 | LED - Generic |  | LED | RED |  |  |  | CHIP LED ROUND |  |  |  |  |  |  |  |  |  |  |  |  |  |  |  |  |  |  |  |  |  |  |  |  |  |  | CHIP |  |  |  | ROUND_TOP
12 | TPB1,27 | TPB1,27 | B1,27 | 5V, A, B, CANH, CANL, CAN_RX, CAN_TX, GND, RX, TX, Y, Z | Test pad |  |  |  |  |  |  |  |  |  |  |  |  |  |  |  |  |  |  |  |  |  |  |  |  |  |  | 19

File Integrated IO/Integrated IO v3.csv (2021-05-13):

Qty | Value | Device | Package | Parts | Description | BREAKDOWN_VOLTAGE | CATEGORY | CLAMPING_VOLTAGE | COLOR | CURRENT_RATING | DATASHEET-URL | DESCRIPTION | IR-UL | MANUFACTURER | MOUNT | MPN | OPERATING_TEMP | PART-NUMBER | PART_STATUS | PINS | PITCH | POPULARITY | RATING | ROHS_COMPLIANT | SERIES | SUB-CATEGORY | THERMALLOSS | TOLERANCE | TP_SIGNAL_NAME | TYPE | VALUE | VOLTAGE_RATING | WIRE | WORKING-VOLTAGE-UL
1 |  | 691402910002B | 691402910002B | J5 | WR-TBL Serie 4029 - 2.54 mm Screwless Horizontal Entry |  |  |  |  |  | https://www.we-online.com/catalog/datasheet/691402910002B.pdf |  | 6A |  | THT |  |  | 691402910002B |  | 2 | 2.54mm |  |  |  |  |  |  |  |  | Horizontal |  |  | 20 to 26 (AWG) 0.518 to 0.129 (mm²) | 150V (AC)
3 |  | 691402910008B | 691402910008B | J1, J2, J3 | WR-TBL Serie 4029 - 2.54 mm Screwless Horizontal Entry |  |  |  |  |  | https://www.we-online.com/catalog/datasheet/691402910008B.pdf |  | 6A |  | THT |  |  | 691402910008B |  | 8 | 2.54mm |  |  |  |  |  |  |  |  | Horizontal |  |  | 20 to 26 (AWG) 0.518 to 0.129 (mm²) | 150V (AC)
1 |  | PINHD-2X10/90 | 2X10/90 | JP1 | PIN HEADER |  |  |  |  |  |  |  |  |  |  |  |  |  |  |  |  | 0
8 | 0.1uF | C-US_CHIP-0805(2012-METRIC) | CAPC2012X110 | C1, C2, C3, C4, C5, C6, C7, C8 | Capacitor - ANSI |  | Capacitor
1 | 10k | R-US_CHIP-0805(2012-METRIC) | RESC2012X65 | R9 | Resistor Fixed - ANSI |  | Resistor |  |  |  |  |  |  |  |  |  |  |  |  |  |  |  |  |  |  | Fixed
17 | 2k | R-US_CHIP-0805(2012-METRIC) | RESC2012X65 | R10, R11, R12, R13, R14, R15, R16, R17, R18, R19, R20, R21, R22, R23, R24, R25, R26 | Resistor Fixed - ANSI |  | Resistor |  |  |  |  |  |  |  |  |  |  |  |  |  |  |  |  |  |  | Fixed
8 | 4.7K | R-US_CHIP-0805(2012-METRIC) | RESC2012X65 | R1, R2, R3, R4, R5, R6, R7, R8 | Resistor Fixed - ANSI |  | Resistor |  |  |  |  |  |  |  |  |  |  |  |  |  |  |  |  |  |  | Fixed
8 | 680nF | C-US_CHIP-0805(2012-METRIC) | CAPC2012X110 | C9, C10, C11, C12, C13, C14, C15, C16 | Capacitor - ANSI |  | Capacitor
4 | ADUM140E | ADUM140E | SOP65P599X175-16N | IC1, IC2, IC3, IC4
8 | FUSE | FUSE_CHIP-1206(3216-METRIC) | FUSC3215X82N | F1, F2, F3, F4, F5, F6, F7, F8 | Fuse - Generic |  | Circuit-Protection |  |  |  |  |  |  |  |  |  |  |  |  |  |  |  |  |  |  | Fuse |  |  |  |  | FUSE
8 | PE10 | PE10 | PE-FORM-A | K1, K2, K3, K4, K5, K6, K7, K8 | SLIM POWER Relay NAiS
18 | R_0805 | CHIP-ROUND-R_0805 | LEDC2012X105N_RND-R | D9, D10, D11, D12, D13, D14, D15, D16, D17, D18, D19, D20, D21, D22, D23, D24, D25, D26 | LED - Generic |  | LED |  | RED |  |  | CHIP LED ROUND |  |  |  |  |  |  |  |  |  |  |  |  |  | CHIP |  |  |  | ROUND_TOP
26 | TPB1,27 | TPB1,27 | B1,27 | 5V, GND, IN_1, IN_1_F, IN_2, IN_2_F, IN_3, IN_3_F, IN_4, IN_4_F, IN_5, IN_5_F, IN_6, IN_6_F, IN_7, IN_7_F, IN_8, IN_8_F, OUT_1, OUT_2, OUT_3, OUT_4, OUT_5, OUT_6, OUT_7, OUT_8 | Test pad |  |  |  |  |  |  |  |  |  |  |  |  |  |  |  |  | 19
8 | TVS-DIODE | TVS_DO-214AC(SMA) | DIOM5226X290N | D1, D2, D3, D4, D5, D6, D7, D8 | TVS Diode - Generic |  | Circuit-Protection |  |  |  |  |  |  |  |  |  |  |  |  |  |  |  |  |  |  | TVS-Diode |  |  |  |  | TVS-DIODE

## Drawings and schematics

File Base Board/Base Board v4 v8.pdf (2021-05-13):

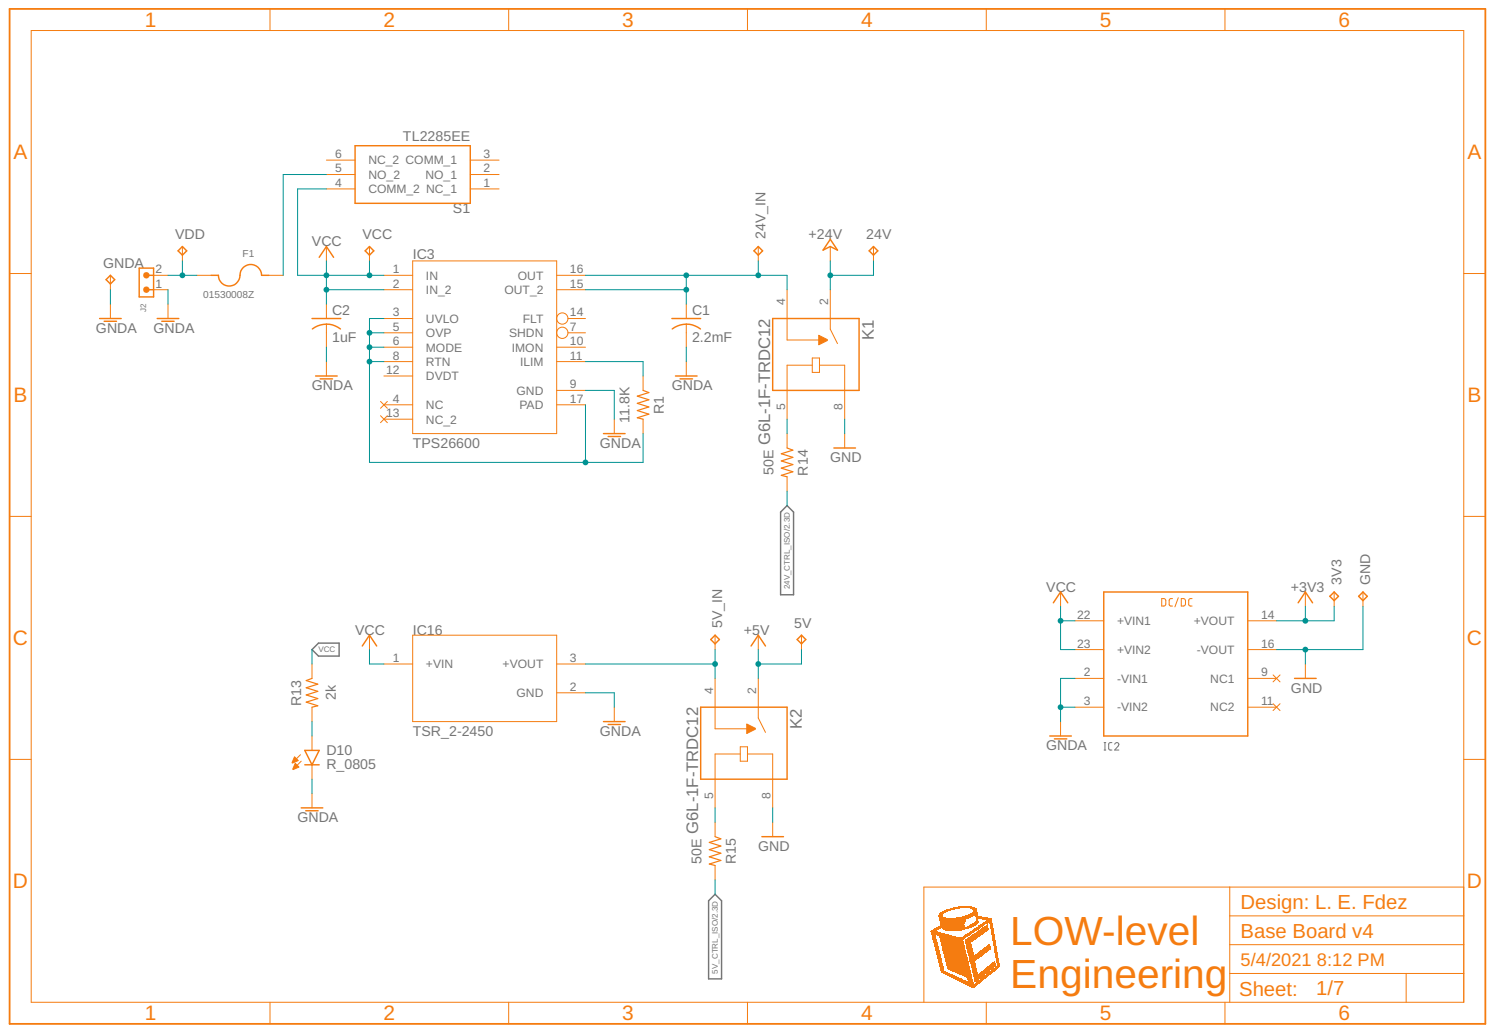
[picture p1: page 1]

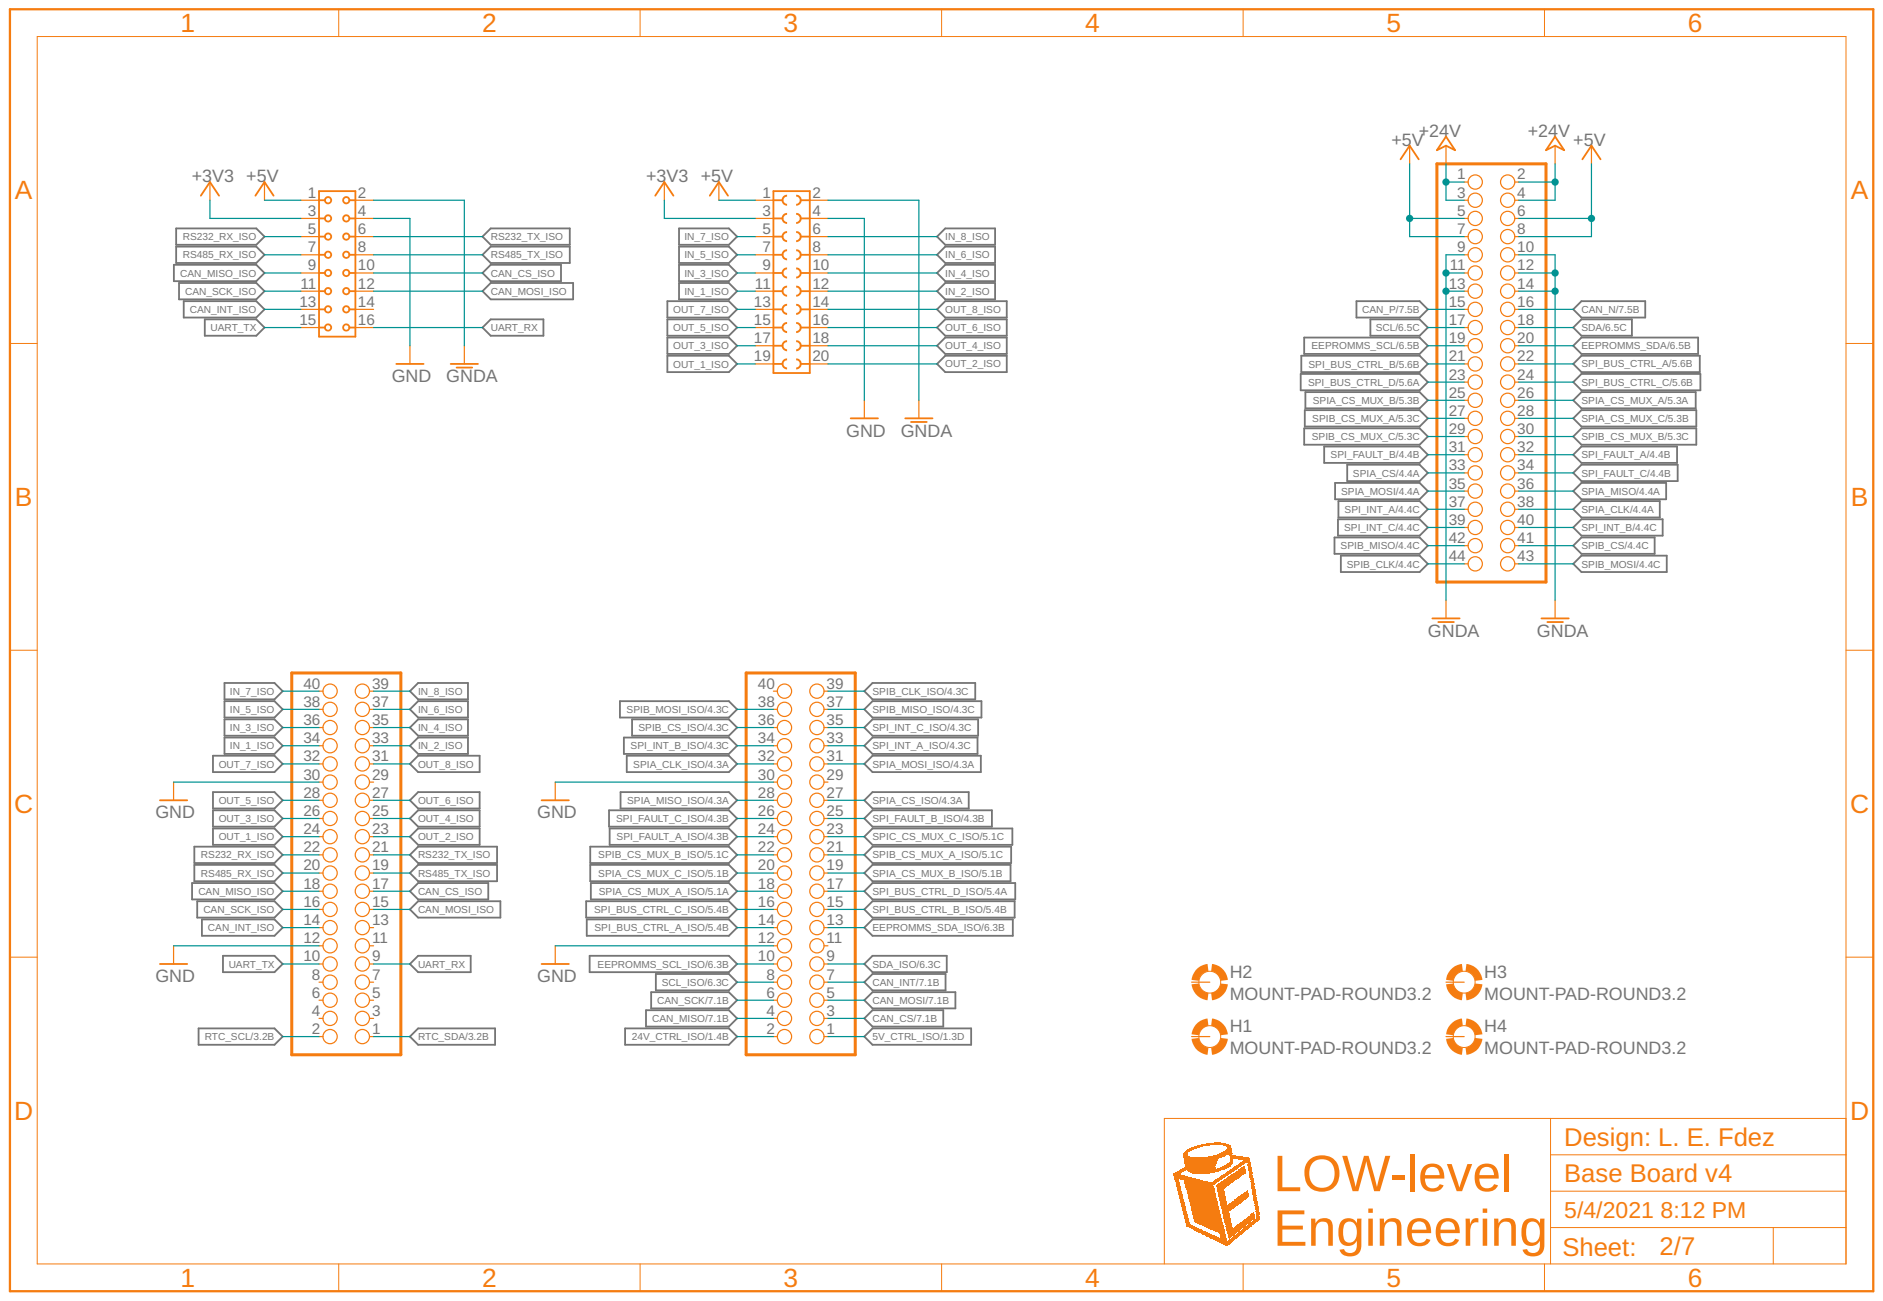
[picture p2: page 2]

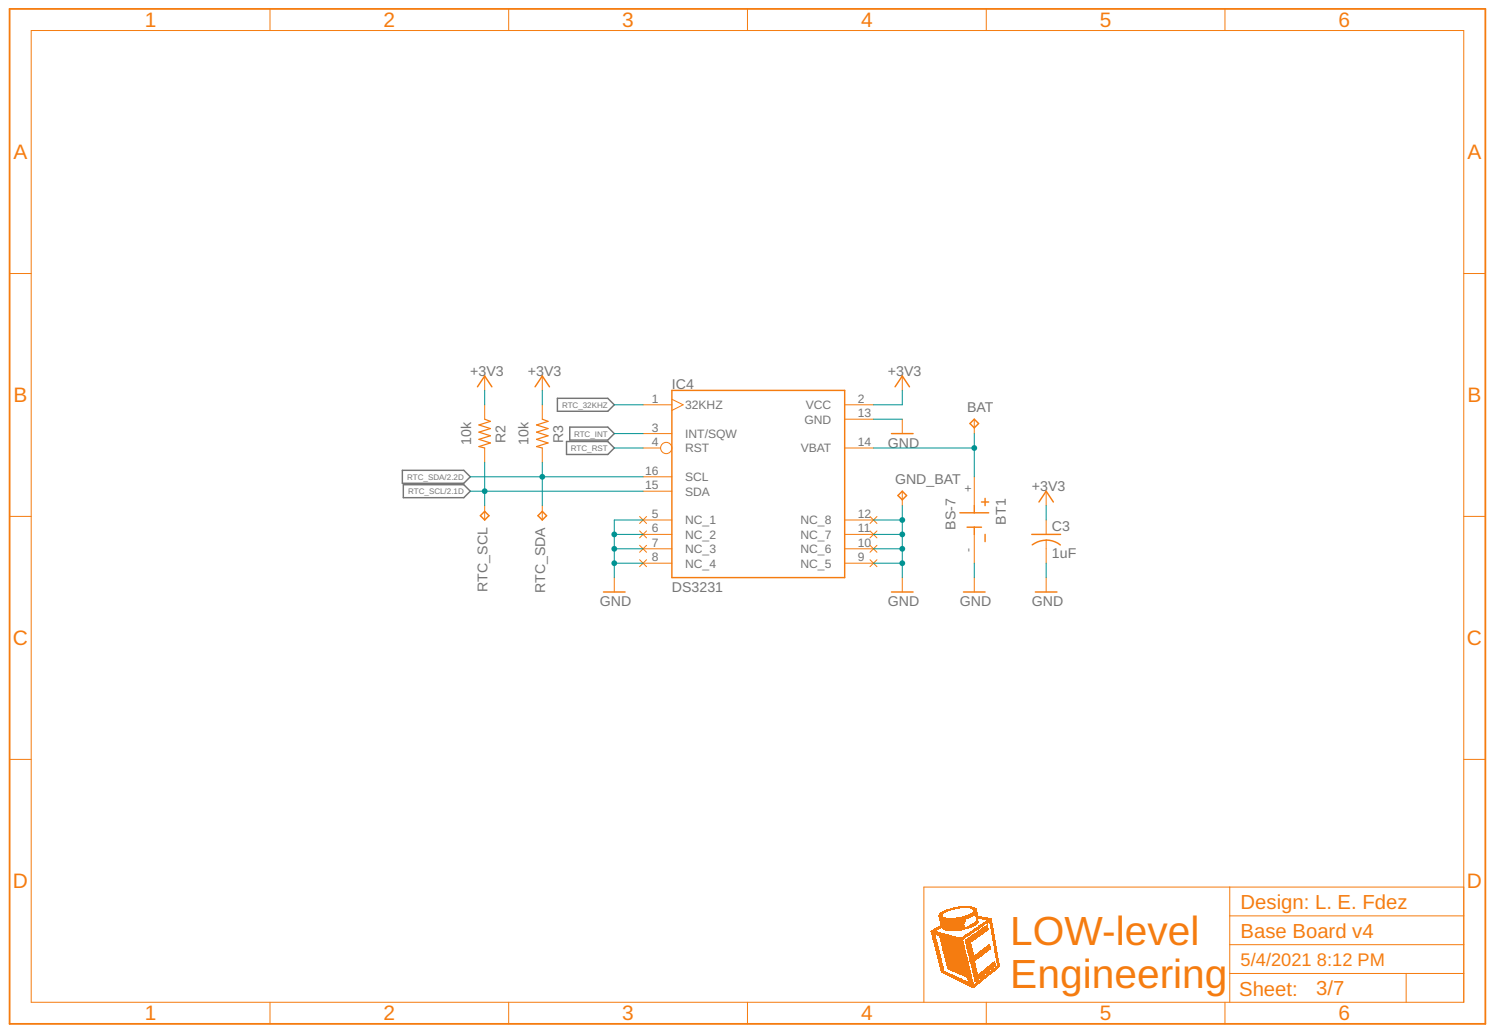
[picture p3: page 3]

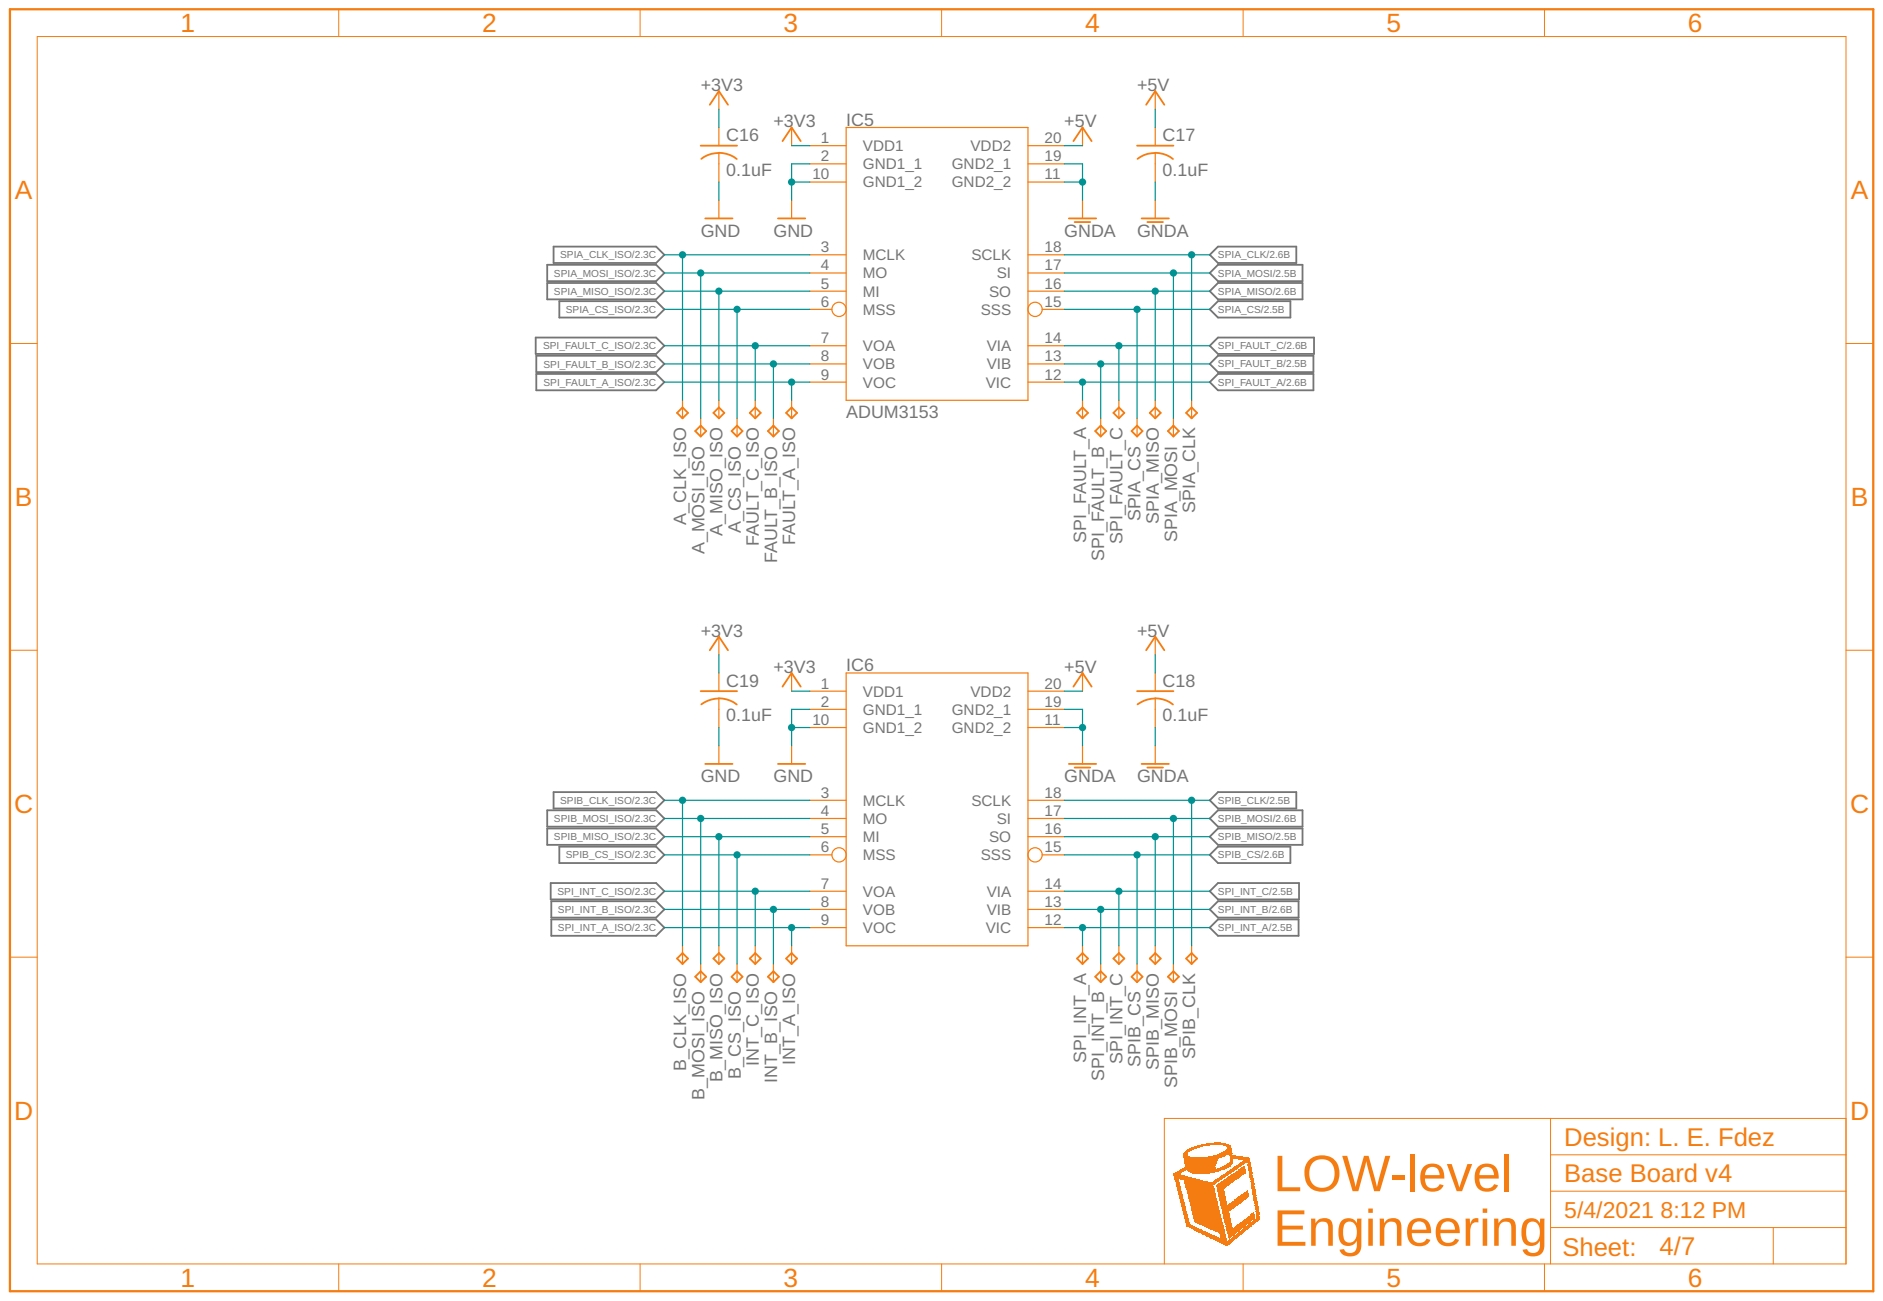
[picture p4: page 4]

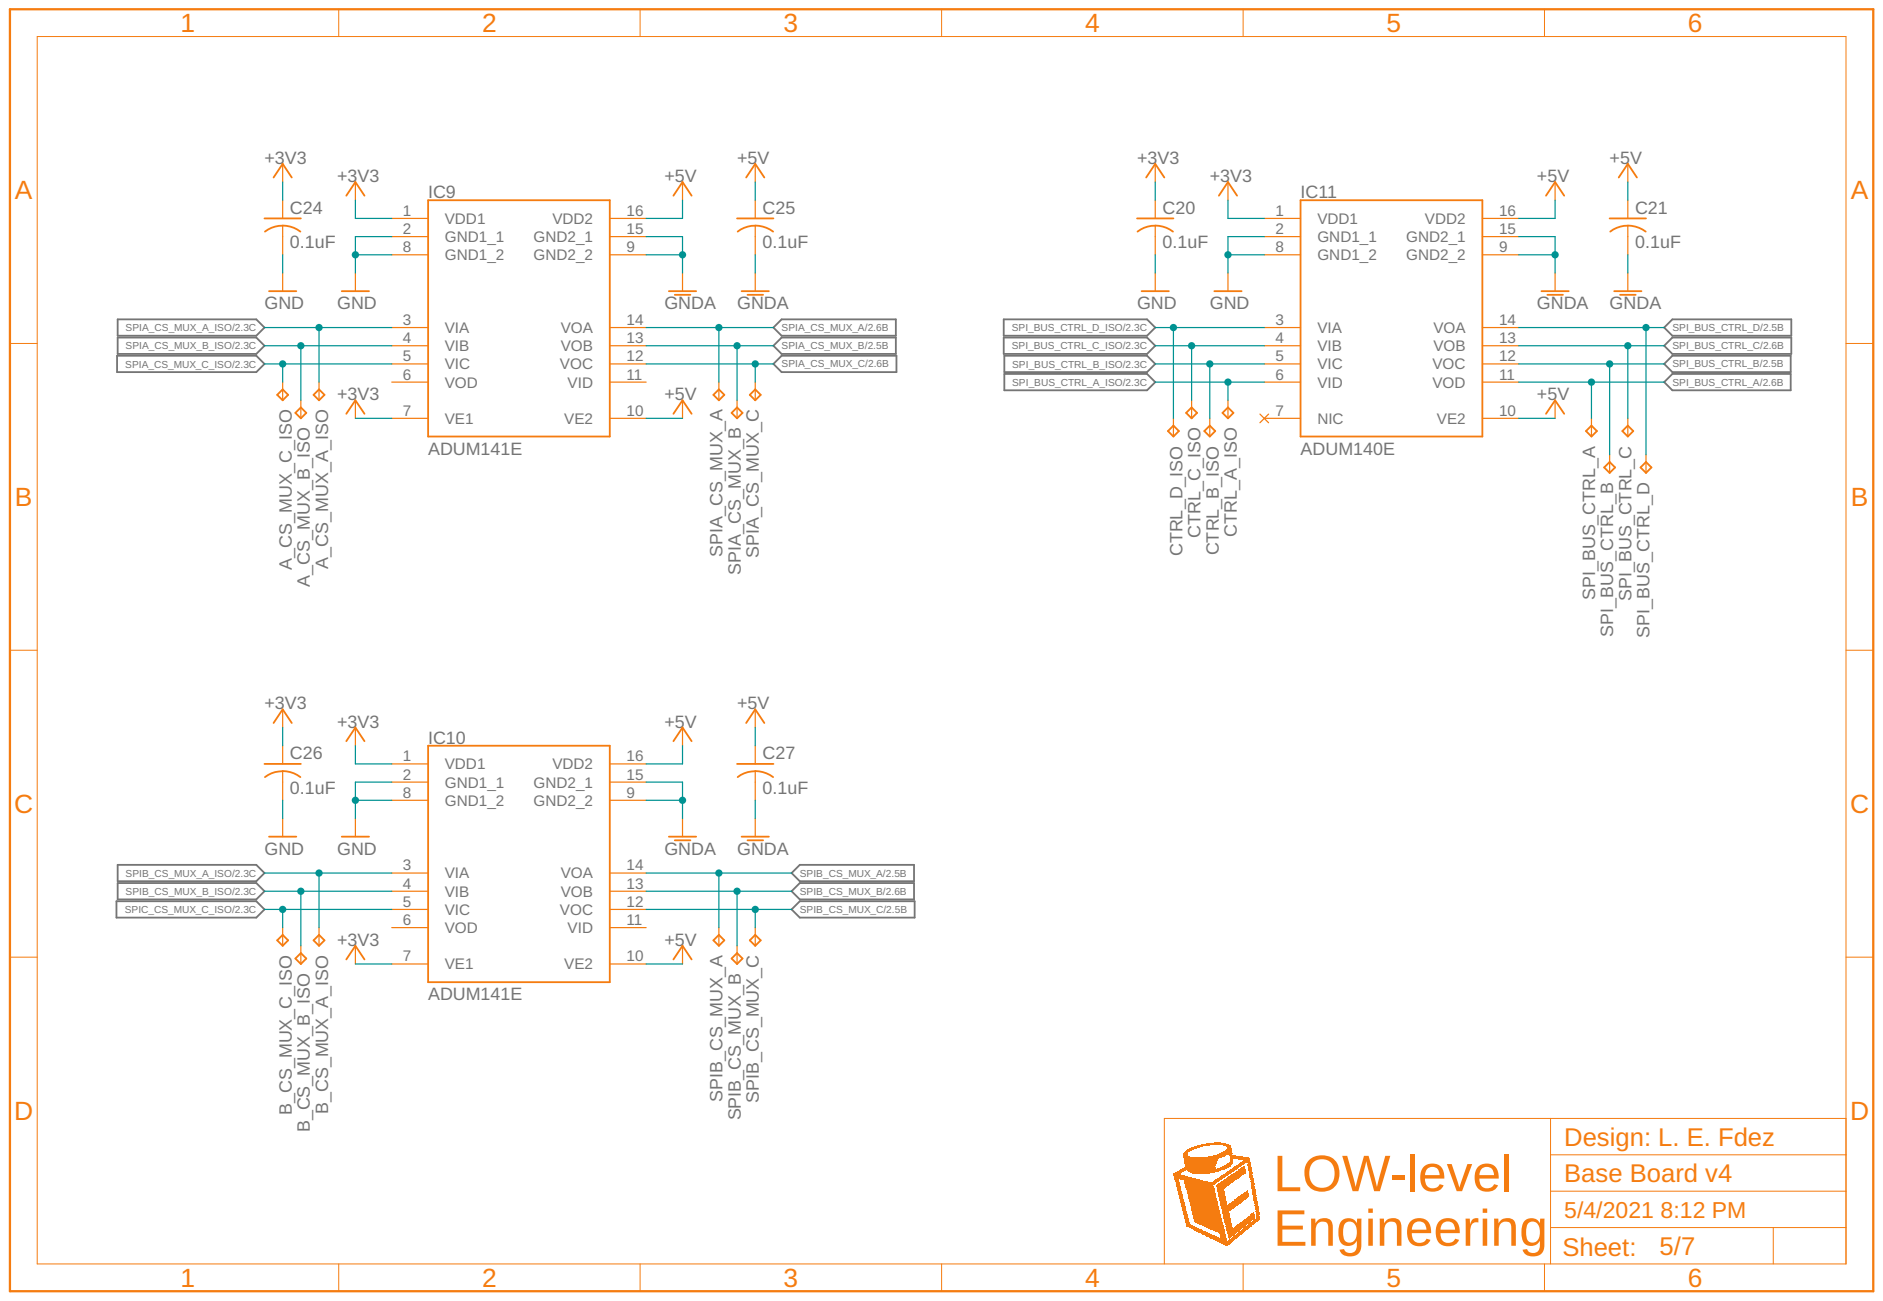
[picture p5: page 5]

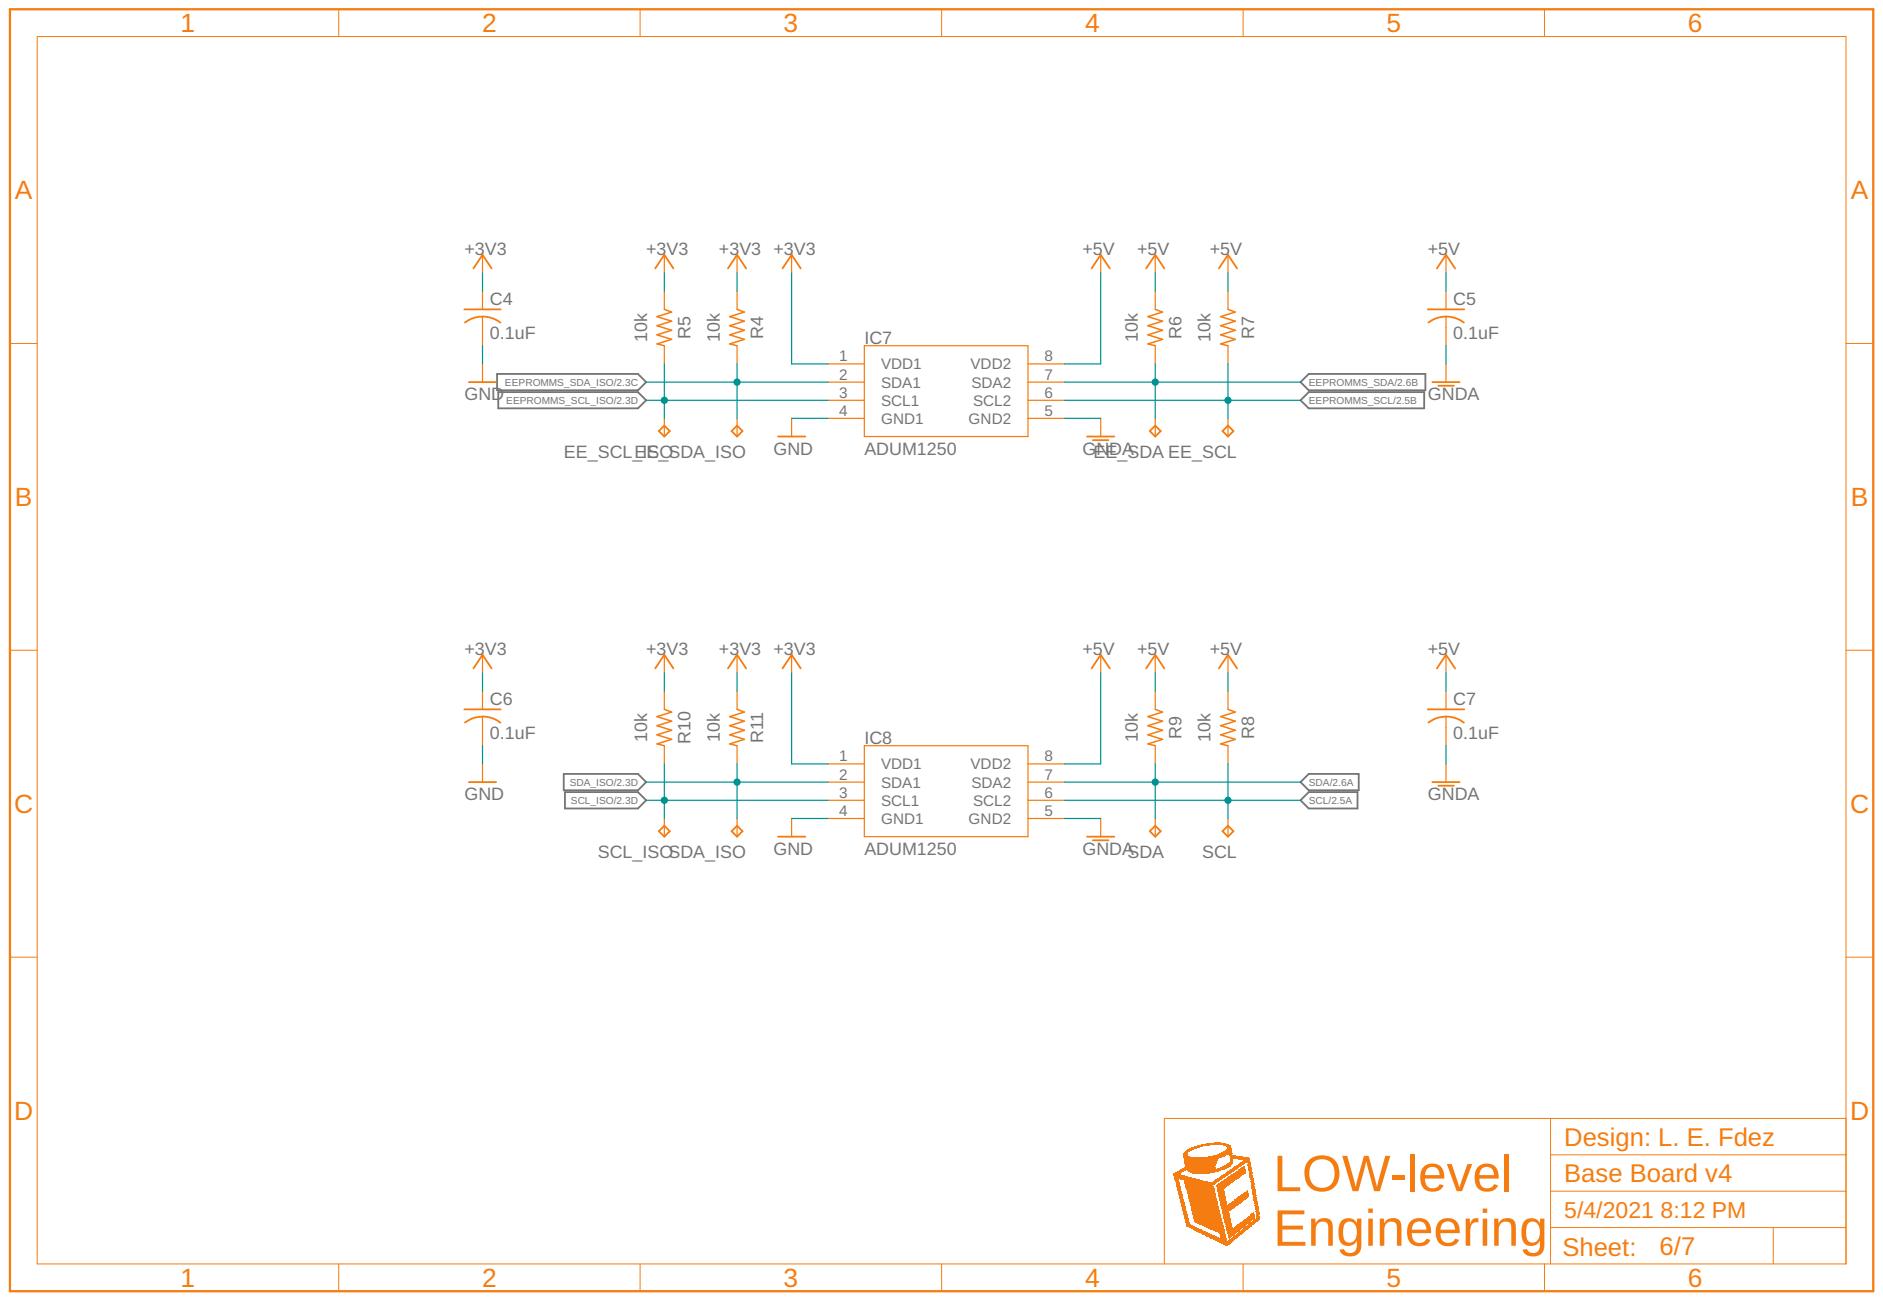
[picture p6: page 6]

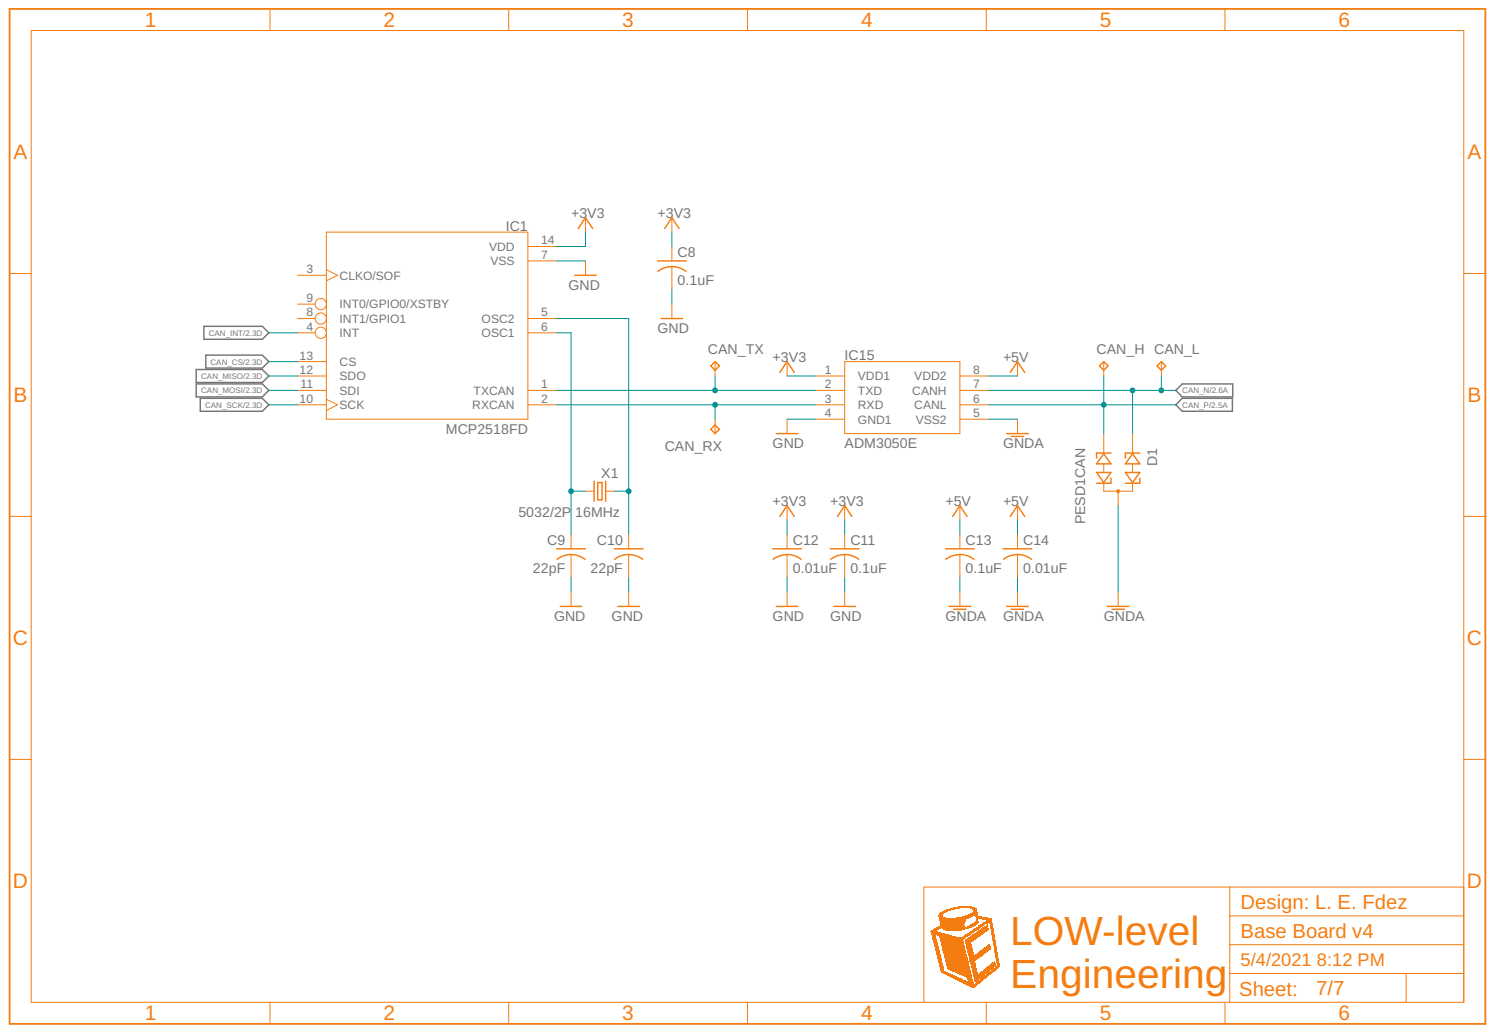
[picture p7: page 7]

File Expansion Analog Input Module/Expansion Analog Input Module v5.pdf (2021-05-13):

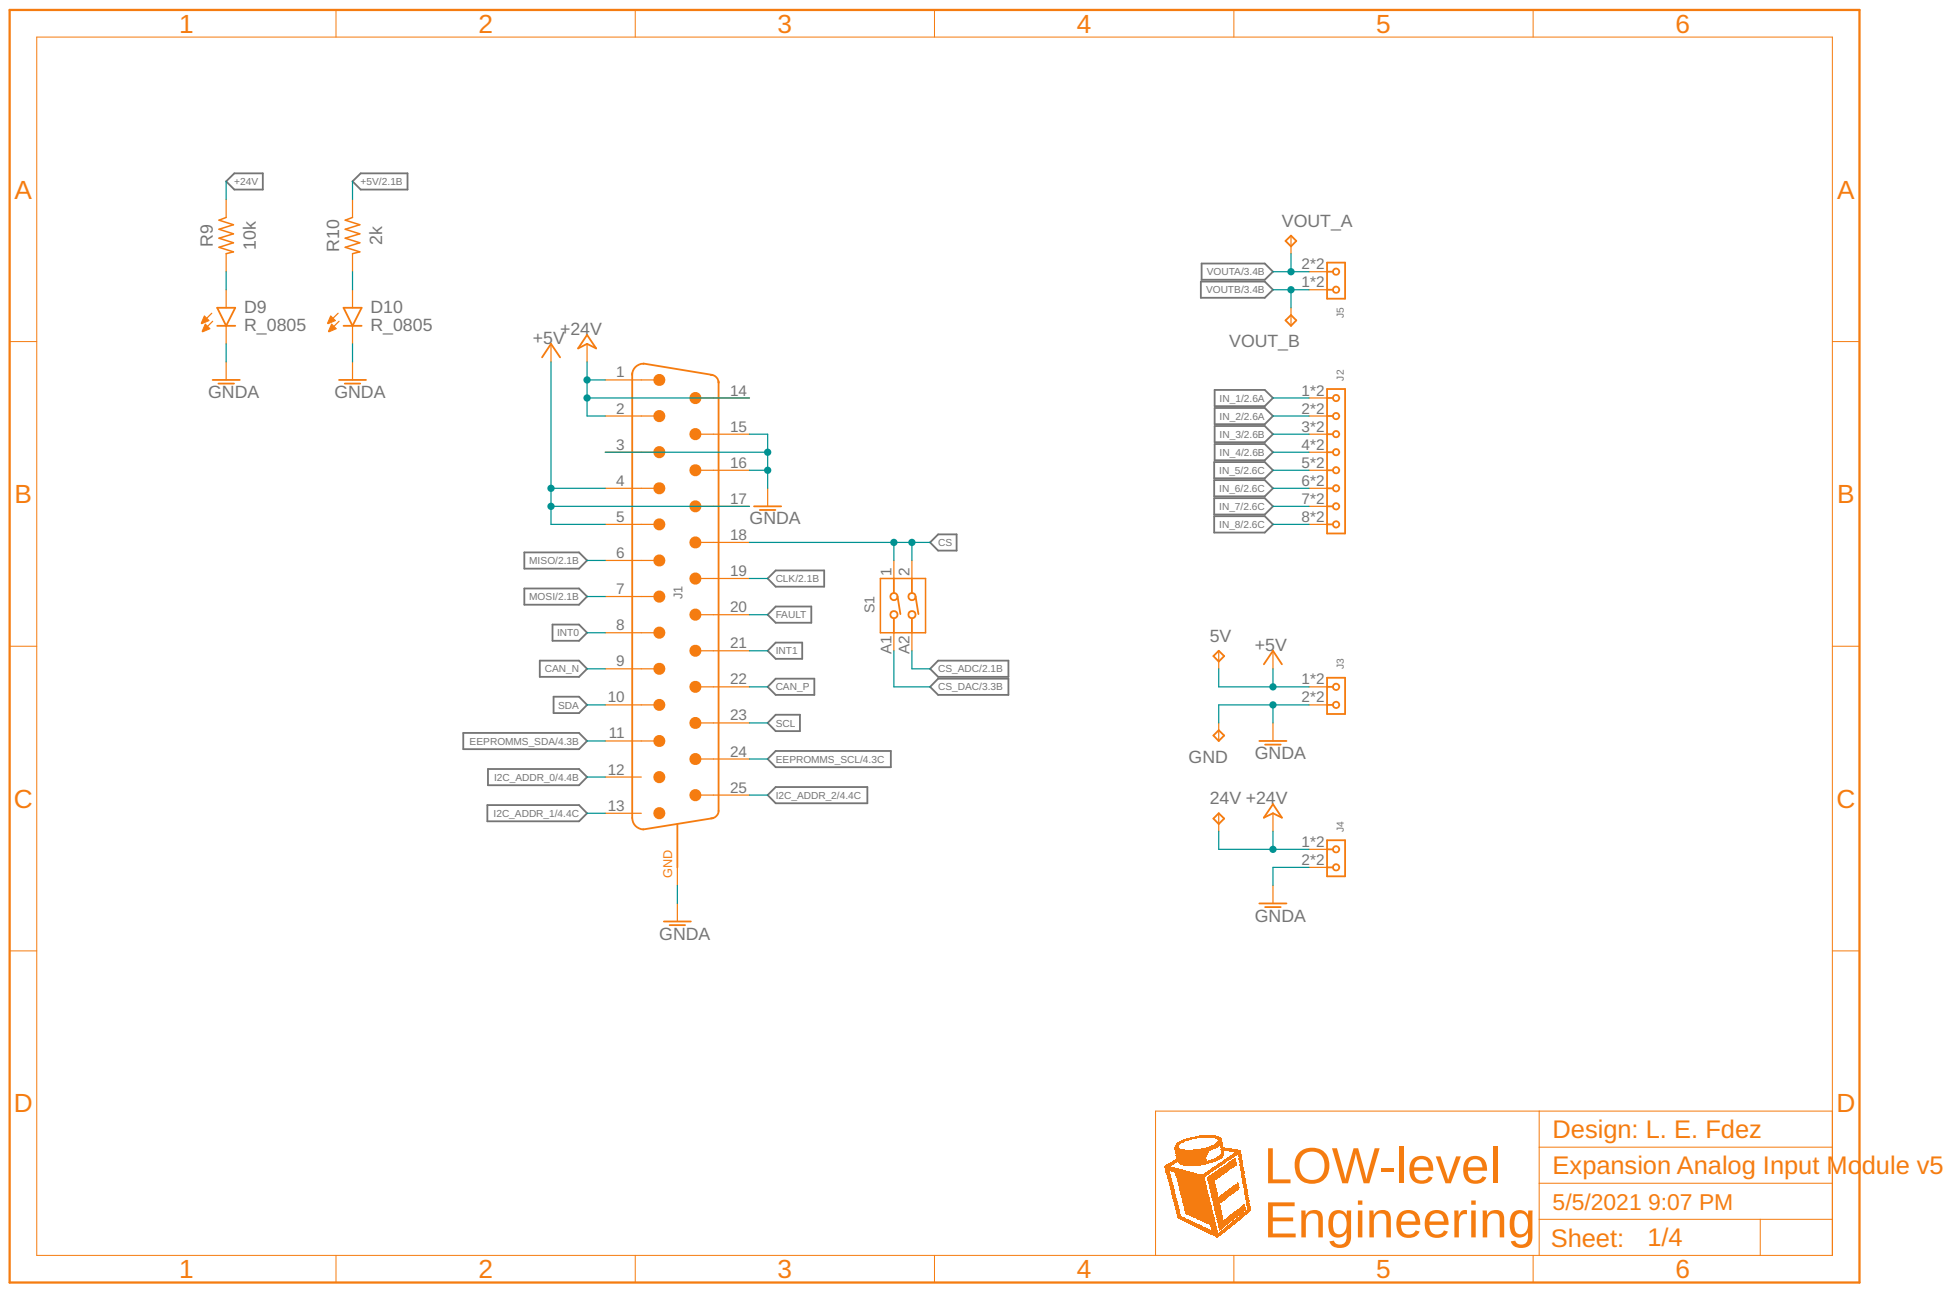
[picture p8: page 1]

Design: L. E. Fdez
Expansion Analog Input Module v5
Sheet:

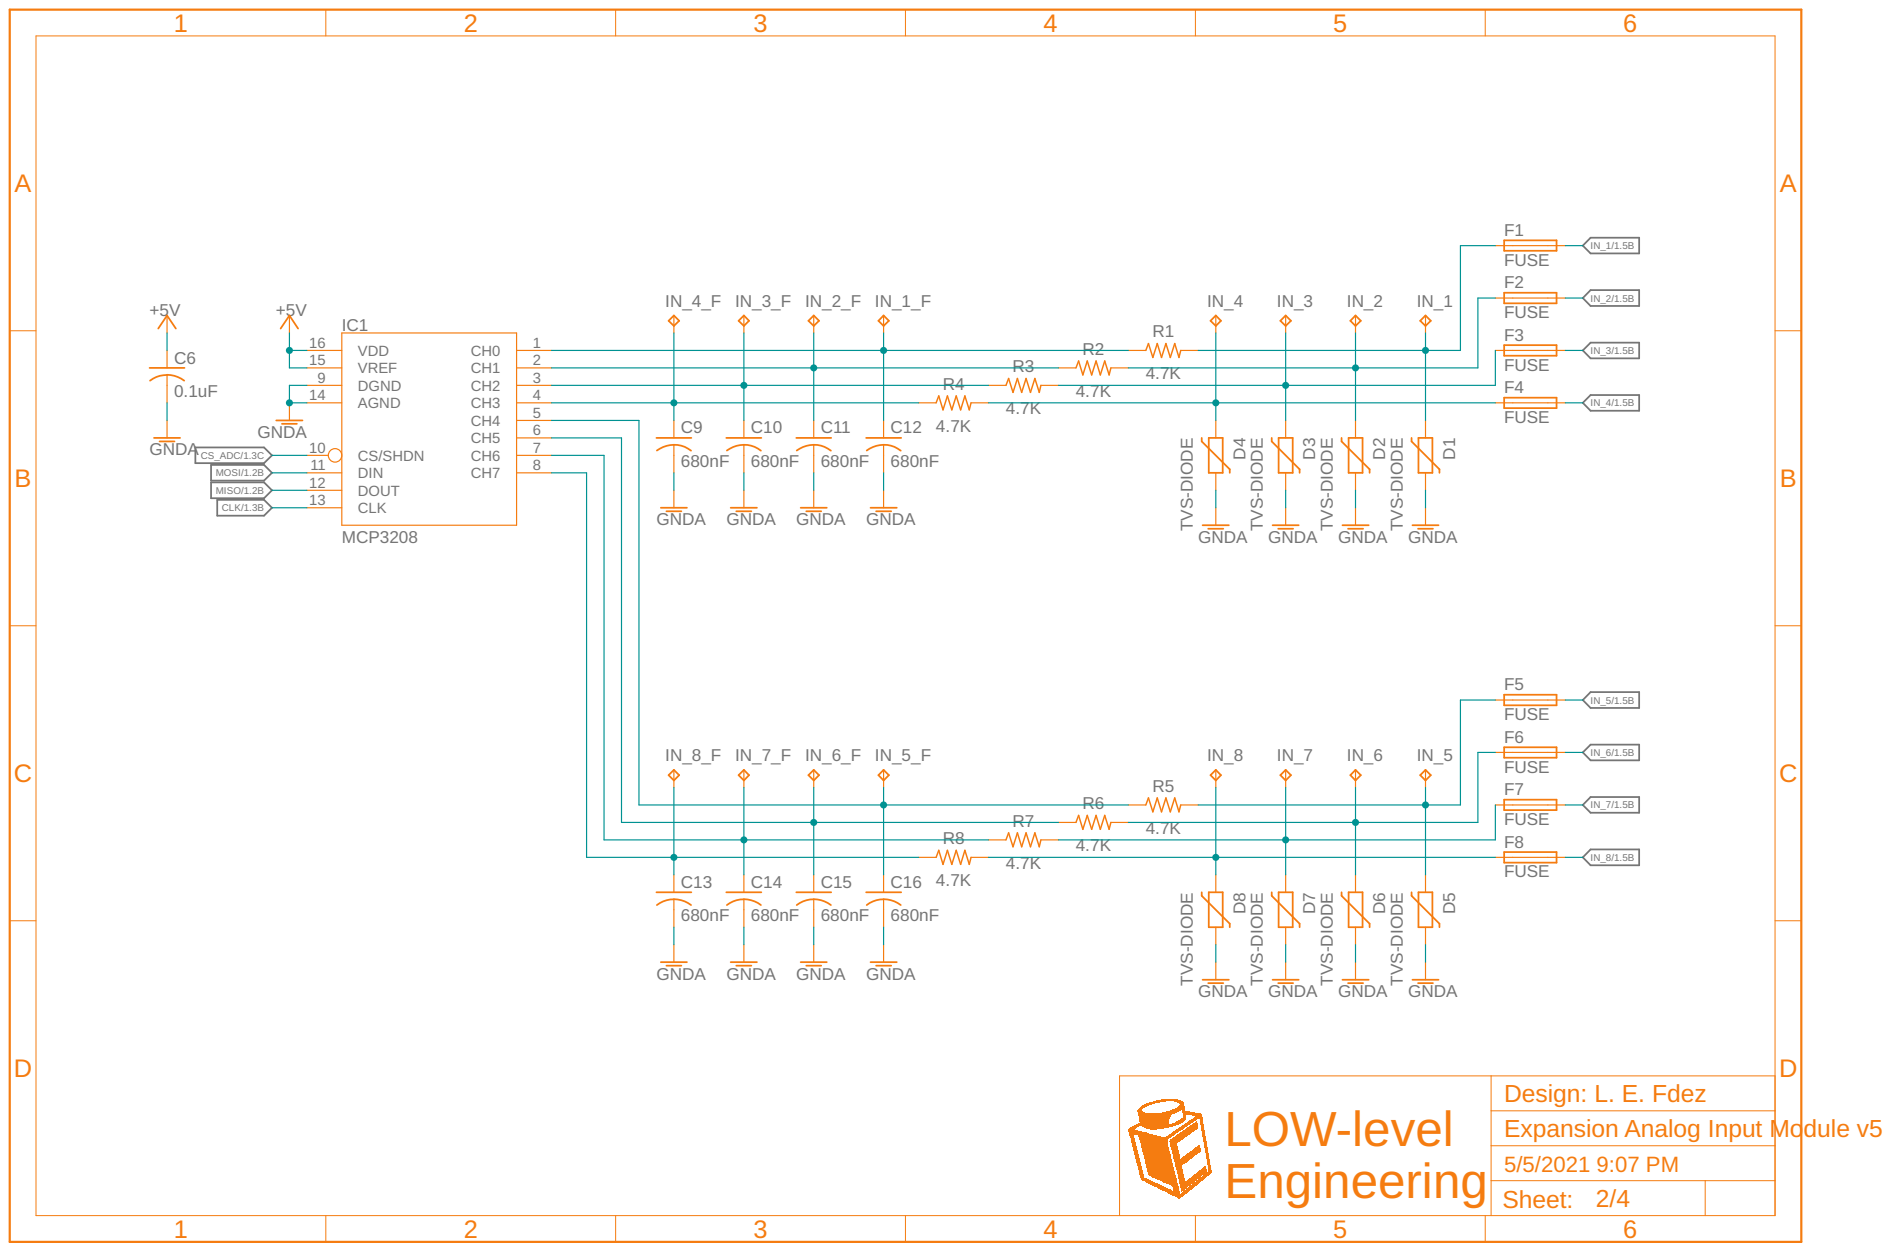
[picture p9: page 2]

Design: L. E. Fdez
Expansion Analog Input Module v5
Sheet:

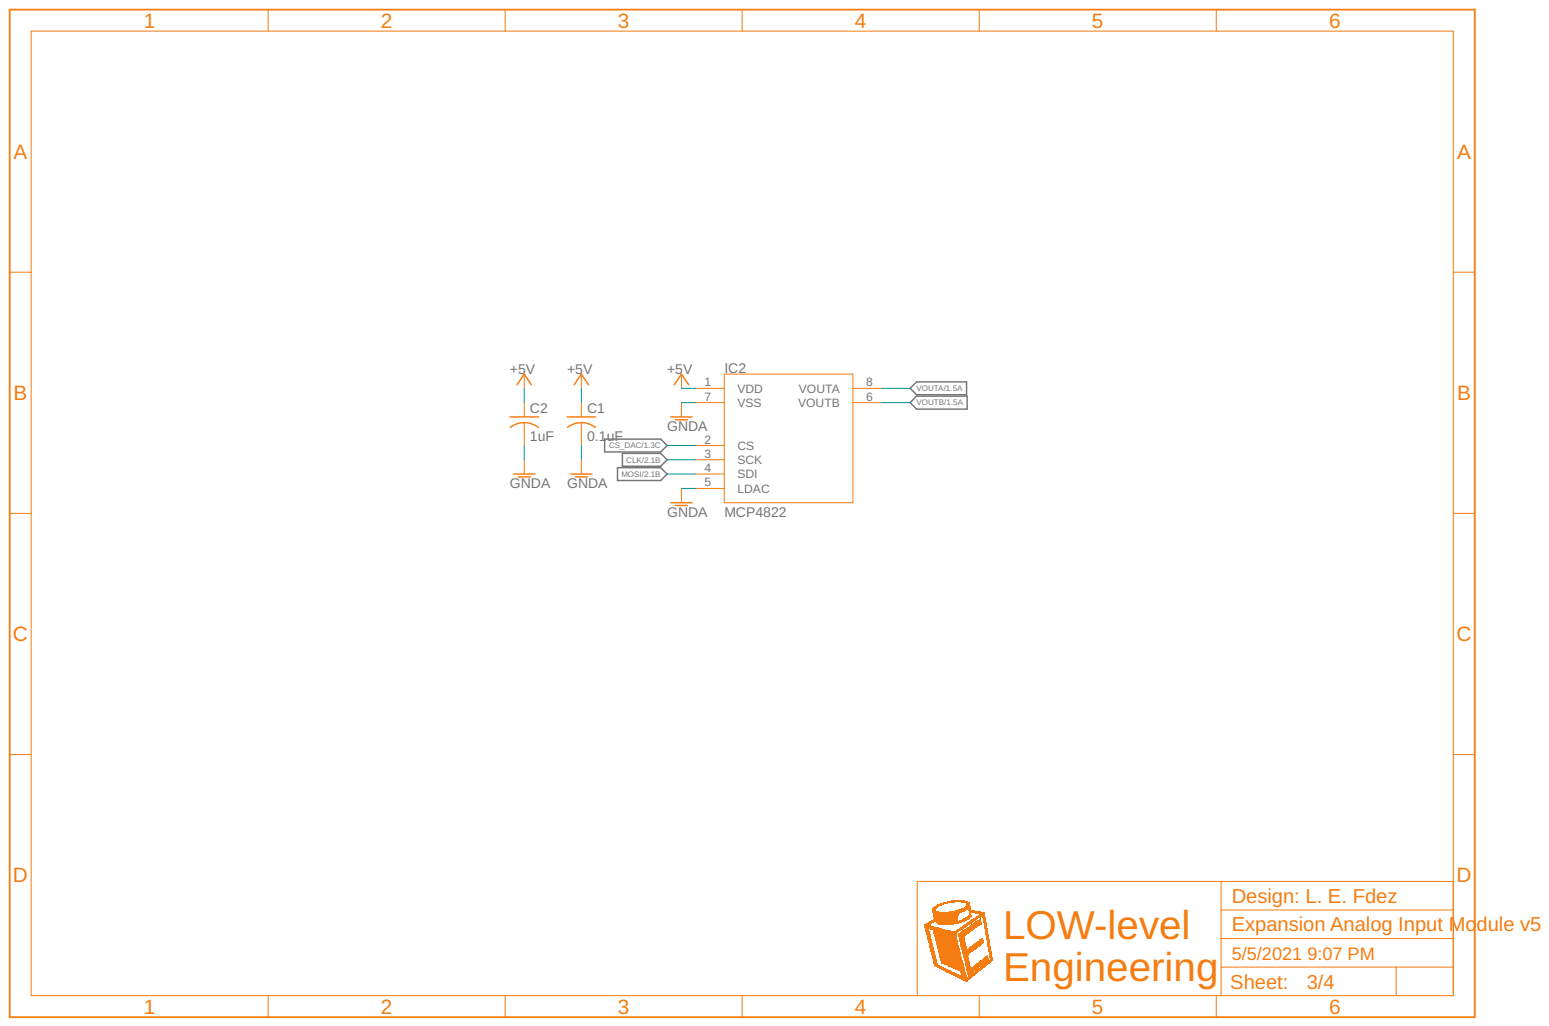
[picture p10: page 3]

Design: L. E. Fdez
Expansion Analog Input Module v5
Sheet:

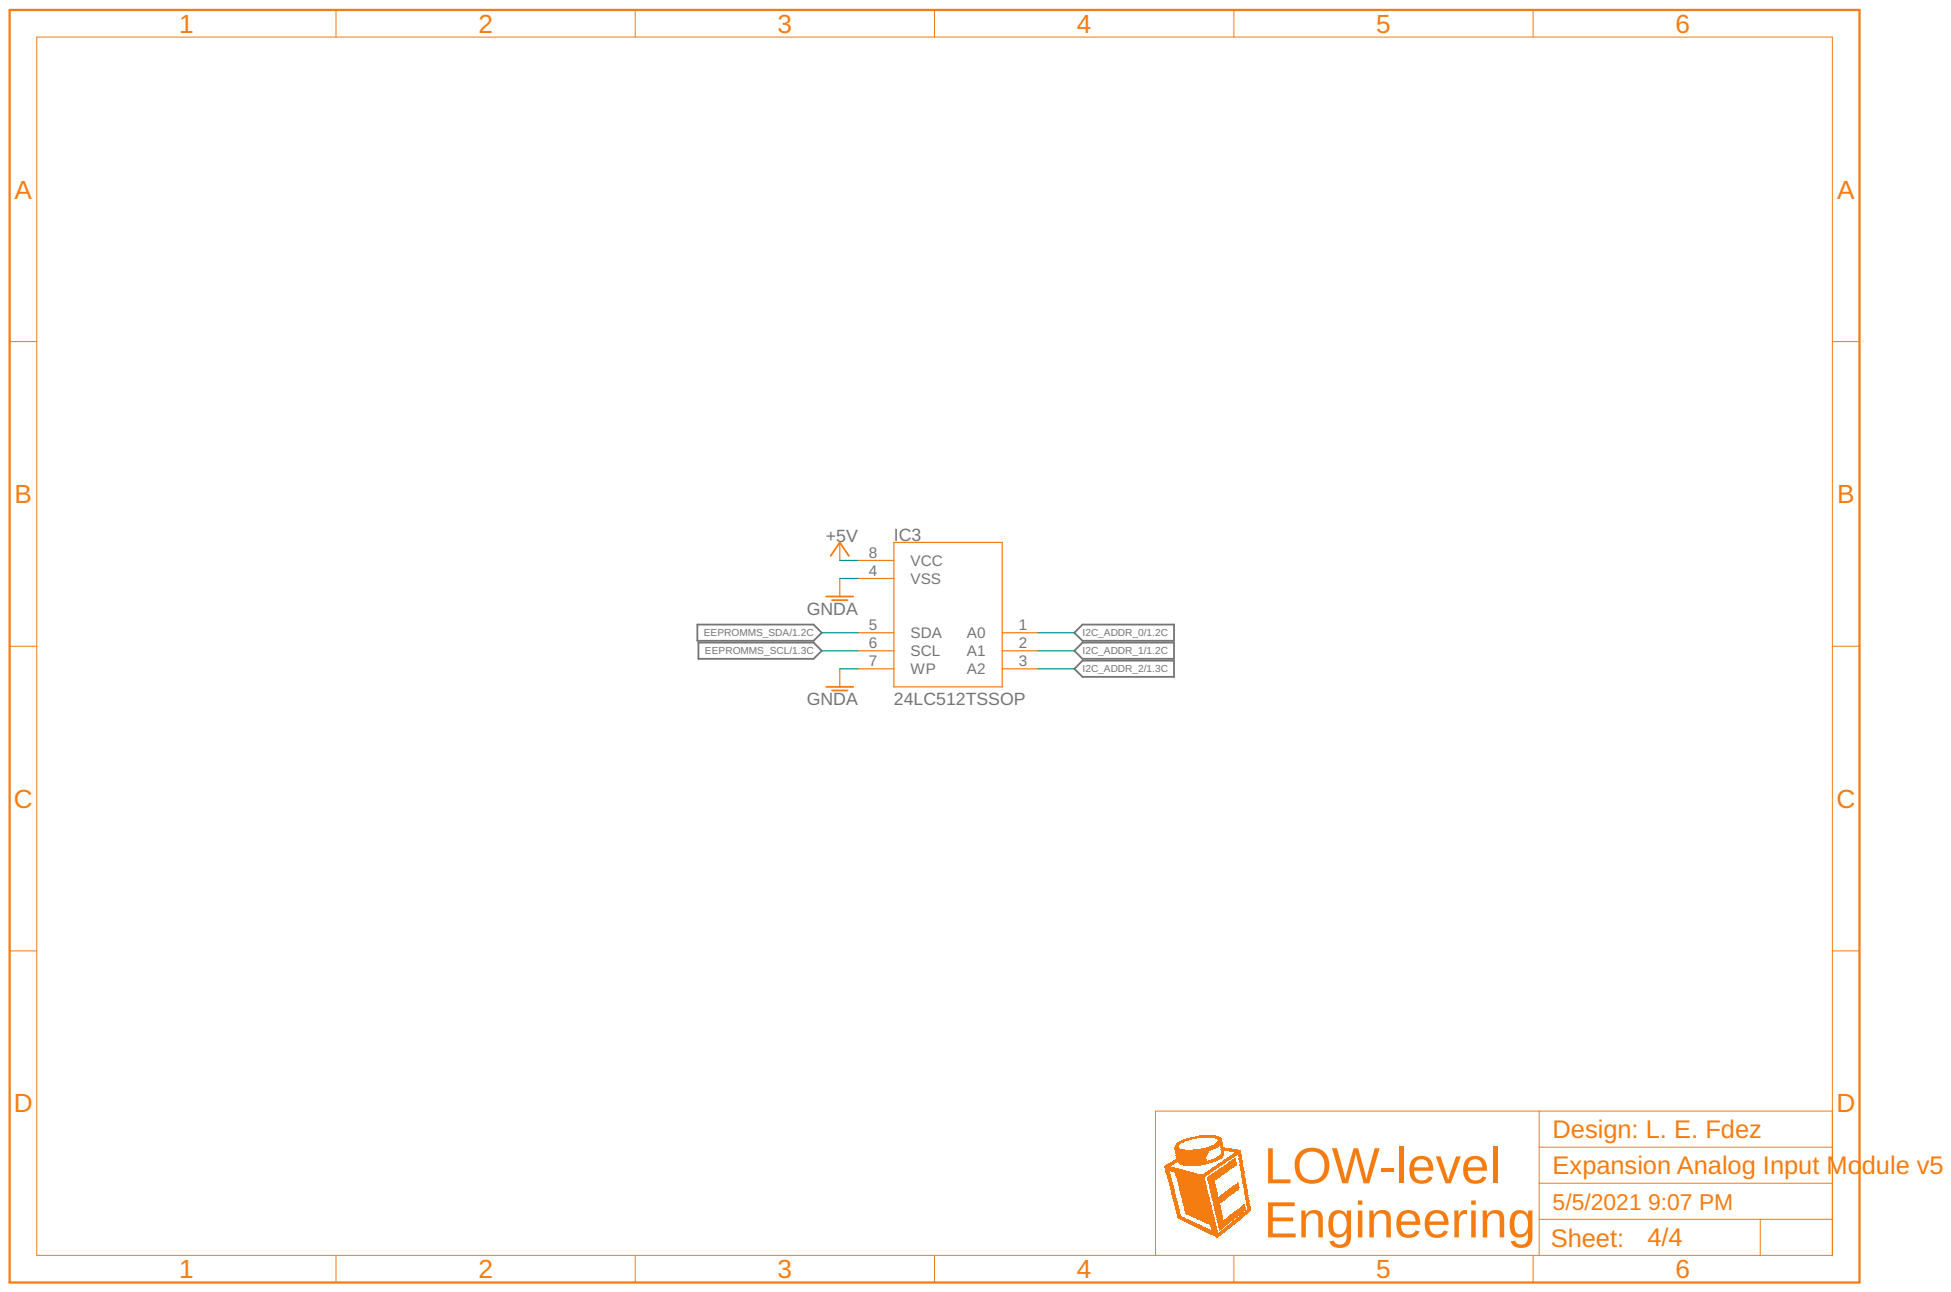
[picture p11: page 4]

Design: L. E. Fdez
Expansion Analog Input Module v5
Sheet:

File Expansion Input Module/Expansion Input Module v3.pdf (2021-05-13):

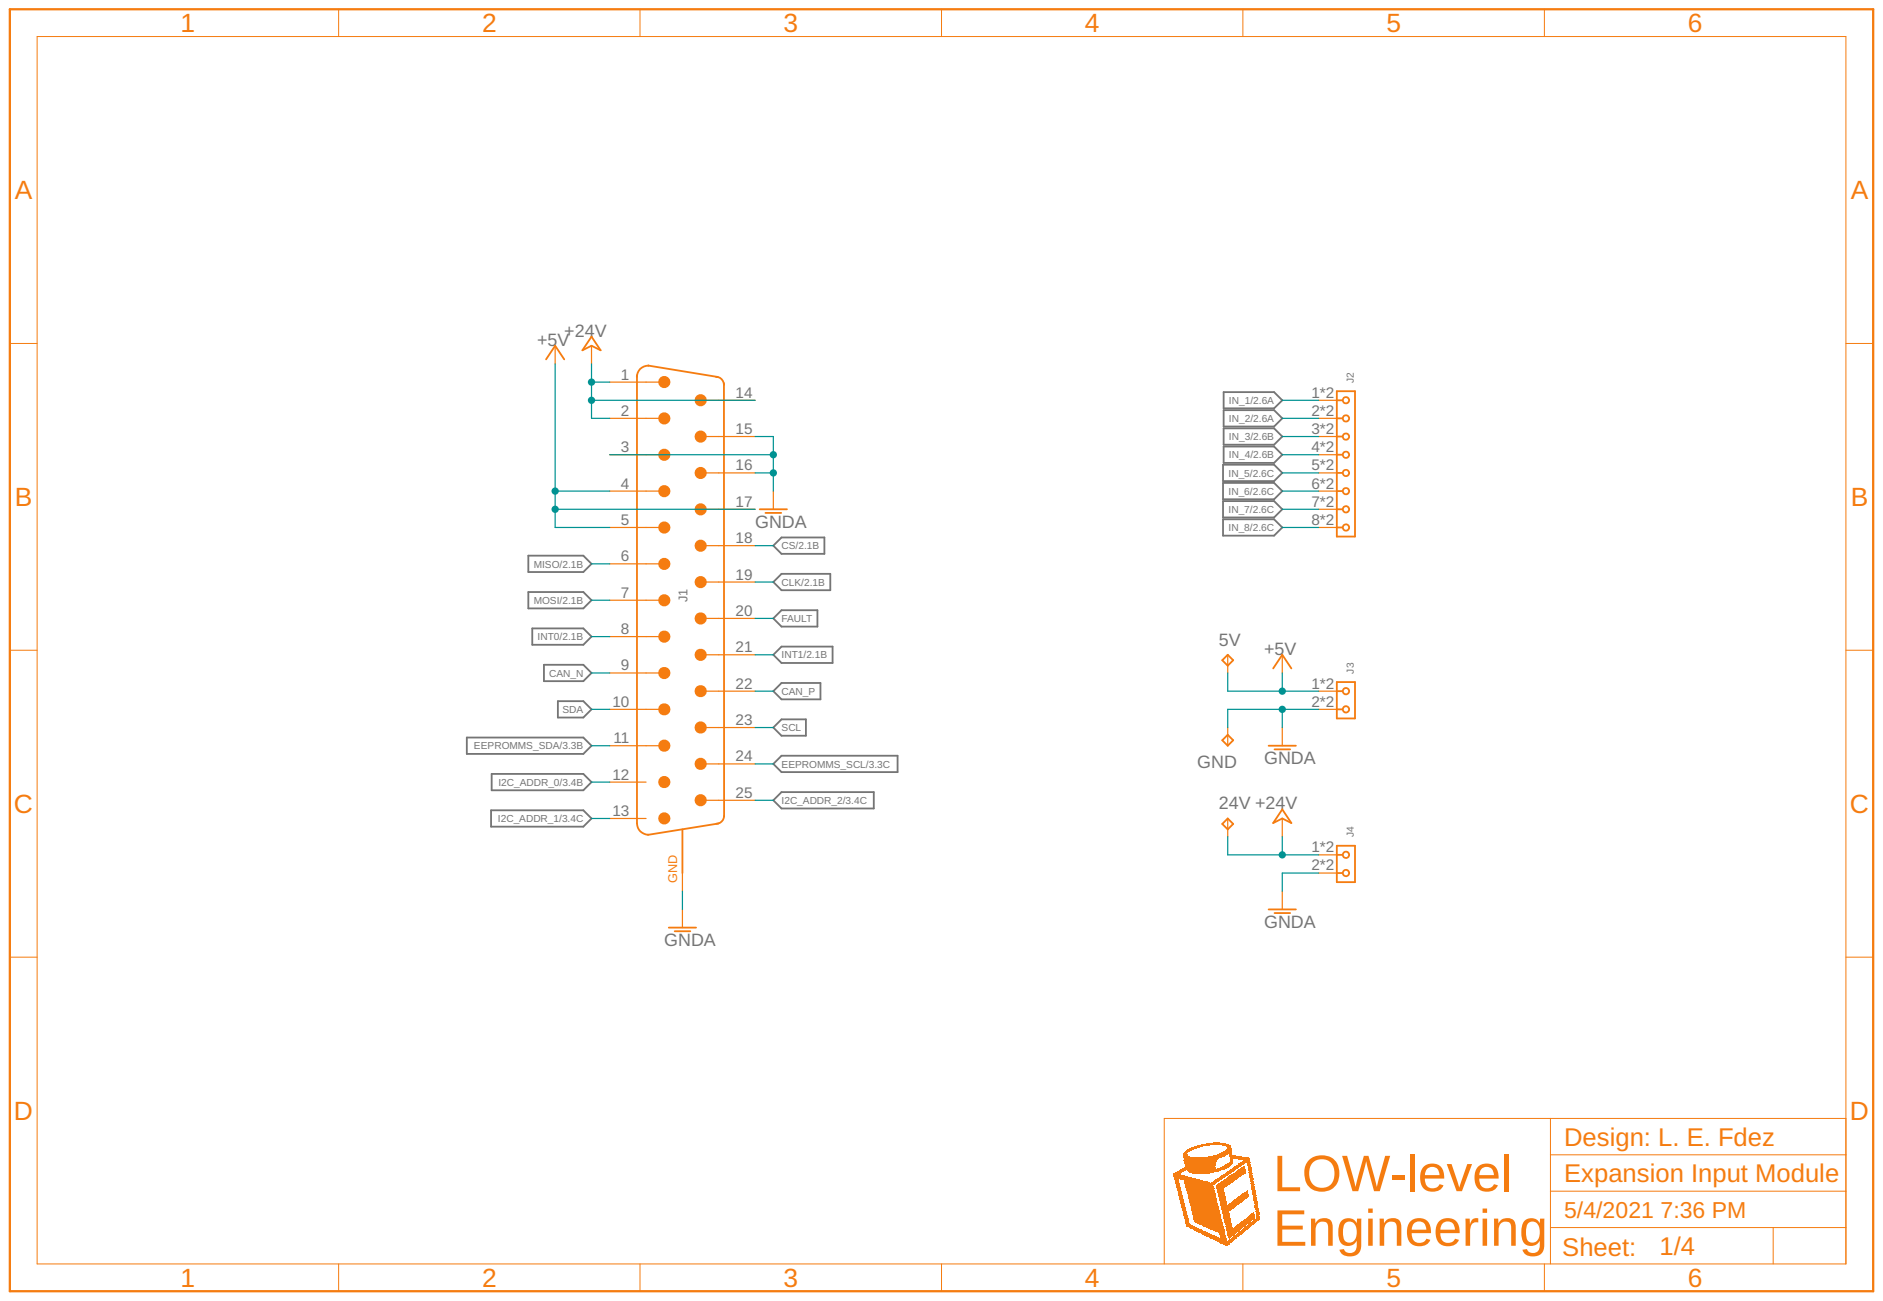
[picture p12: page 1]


CS/1.3B CLK/1.3B MOSI/1.2B MISO/1.2B



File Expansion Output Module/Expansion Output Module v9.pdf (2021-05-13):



22 GPA2 23 GPA3 6 | 13

24 GPA4 5 | 14
25 GPA5 4 | 15

CS/1.2B CLK/1.2B MOSI/1.2B MISO/1.2B














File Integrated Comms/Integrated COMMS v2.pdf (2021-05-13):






LOW-level Engineering

Sheet: 5/5

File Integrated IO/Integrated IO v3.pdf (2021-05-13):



12 VOB
11 VOC

13 VOA



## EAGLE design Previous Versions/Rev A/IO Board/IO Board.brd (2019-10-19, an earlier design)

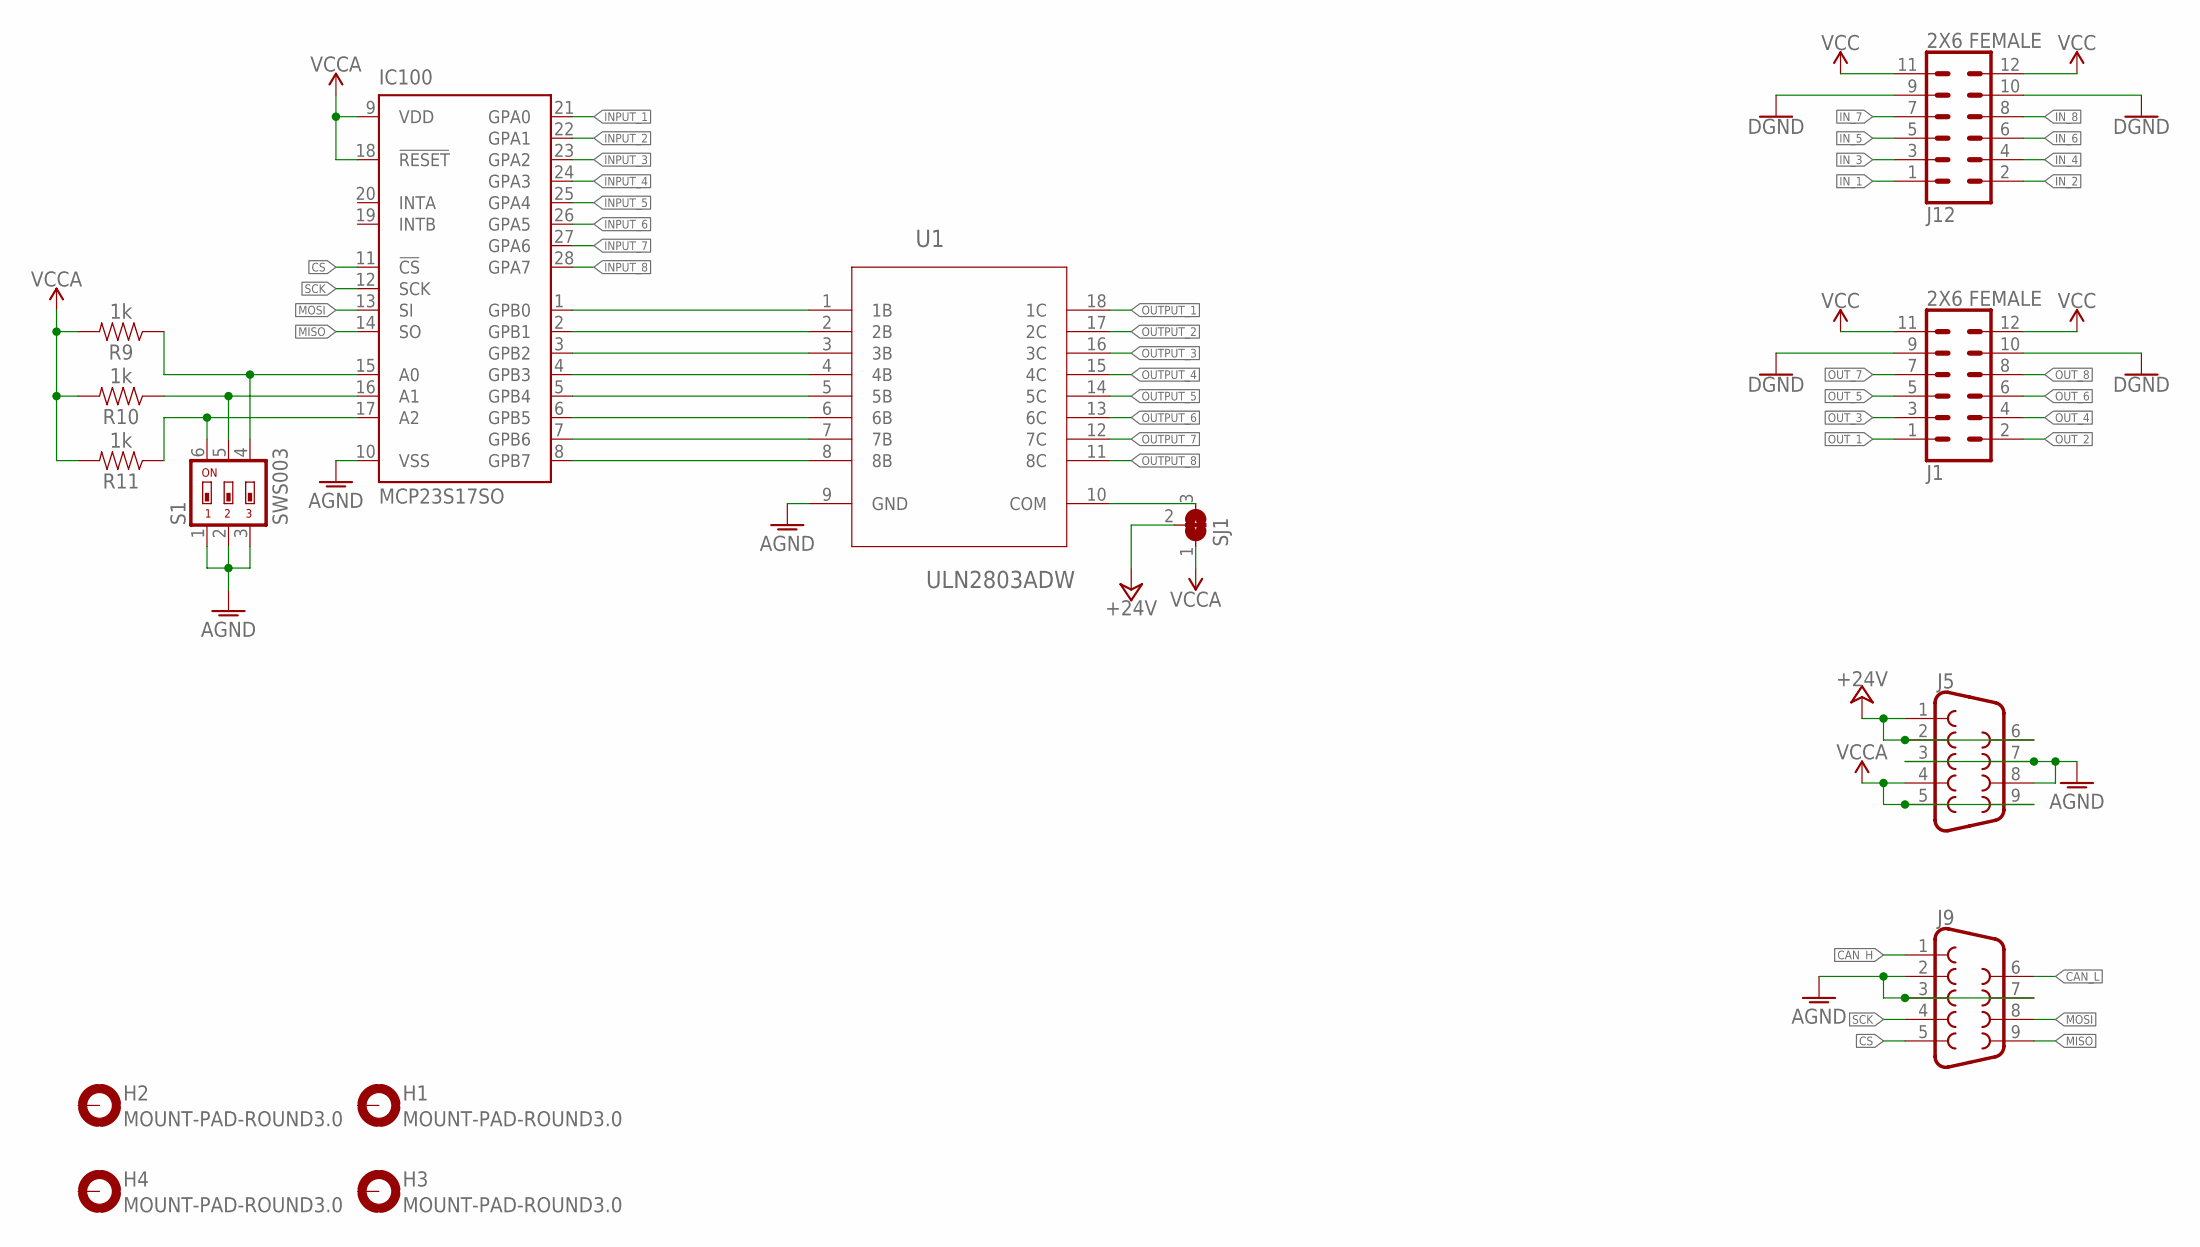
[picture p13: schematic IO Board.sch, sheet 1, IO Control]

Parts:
H1, H2, H3, H4: MOUNT-PAD-ROUND3.0; 3,0-PAD
IC100: MCP23S17SO; SO28W
J1, J12: 2X6 FEMALE; 2X6
J5, J9: DB9FEMALE; DB9
R9, R10, R11: 1k; 0805
S1: SWS003; SMS-003
SJ1: SOLDERJUMPER_2WAY; SOLDERJUMPER_2WAY_OPEN_NOPASTE
U1: ULN2803ADW; SOIC127P1030X265-18N

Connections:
+24V: J5.1, J5.2, J5.6, SJ1.2; also elsewhere on the board
AGND: IC100.10 (VSS), J5.3, J5.7, J5.8, J9.2, J9.3, J9.7, S1.1, S1.2, S1.3, U1.9 (GND); also elsewhere on the board
CAN_H: J9.1
CAN_L: J9.6
CS: IC100.11 (!CS), J9.5
GND: J1.9, J1.10, J12.9, J12.10; also elsewhere on the board
INPUT_1: IC100.21 (GPA0); also elsewhere on the board
INPUT_2: IC100.22 (GPA1); also elsewhere on the board
INPUT_3: IC100.23 (GPA2); also elsewhere on the board
INPUT_4: IC100.24 (GPA3); also elsewhere on the board
INPUT_5: IC100.25 (GPA4); also elsewhere on the board
INPUT_6: IC100.26 (GPA5); also elsewhere on the board
INPUT_7: IC100.27 (GPA6); also elsewhere on the board
INPUT_8: IC100.28 (GPA7); also elsewhere on the board
IN_1: J12.1; also elsewhere on the board
IN_2: J12.2; also elsewhere on the board
IN_3: J12.3; also elsewhere on the board
IN_4: J12.4; also elsewhere on the board
IN_5: J12.5; also elsewhere on the board
IN_6: J12.6; also elsewhere on the board
IN_7: J12.7; also elsewhere on the board
IN_8: J12.8; also elsewhere on the board
MISO: IC100.14 (SO), J9.9
MOSI: IC100.13 (SI), J9.8
unnamed: IC100.1 (GPB0), U1.1 (1B)
unnamed: IC100.3 (GPB2), U1.3 (3B)
unnamed: IC100.2 (GPB1), U1.2 (2B)
unnamed: IC100.4 (GPB3), U1.4 (4B)
unnamed: SJ1.3, U1.10 (COM)
unnamed: IC100.5 (GPB4), U1.5 (5B)
unnamed: IC100.7 (GPB6), U1.7 (7B)
unnamed: IC100.6 (GPB5), U1.6 (6B)
unnamed: IC100.8 (GPB7), U1.8 (8B)
unnamed: IC100.15 (A0), R9.1, S1.4
unnamed: IC100.16 (A1), R10.1, S1.5
unnamed: IC100.17 (A2), R11.1, S1.6
OUTPUT_1: U1.18 (1C); also elsewhere on the board
OUTPUT_2: U1.17 (2C); also elsewhere on the board
OUTPUT_3: U1.16 (3C); also elsewhere on the board
OUTPUT_4: U1.15 (4C); also elsewhere on the board
OUTPUT_5: U1.14 (5C); also elsewhere on the board
OUTPUT_6: U1.13 (6C); also elsewhere on the board
OUTPUT_7: U1.12 (7C); also elsewhere on the board
OUTPUT_8: U1.11 (8C); also elsewhere on the board
OUT_1: J1.1; also elsewhere on the board
OUT_2: J1.2; also elsewhere on the board
OUT_3: J1.3; also elsewhere on the board
OUT_4: J1.4; also elsewhere on the board
OUT_5: J1.5; also elsewhere on the board
OUT_6: J1.6; also elsewhere on the board
OUT_7: J1.7; also elsewhere on the board
OUT_8: J1.8; also elsewhere on the board
SCK: IC100.12 (SCK), J9.4
VCC: J1.11, J1.12, J12.11, J12.12; also elsewhere on the board
VCCA: IC100.9 (VDD), IC100.18 (!RESET), J5.4, J5.5, J5.9, R9.2, R10.2, R11.2, SJ1.1; also elsewhere on the board

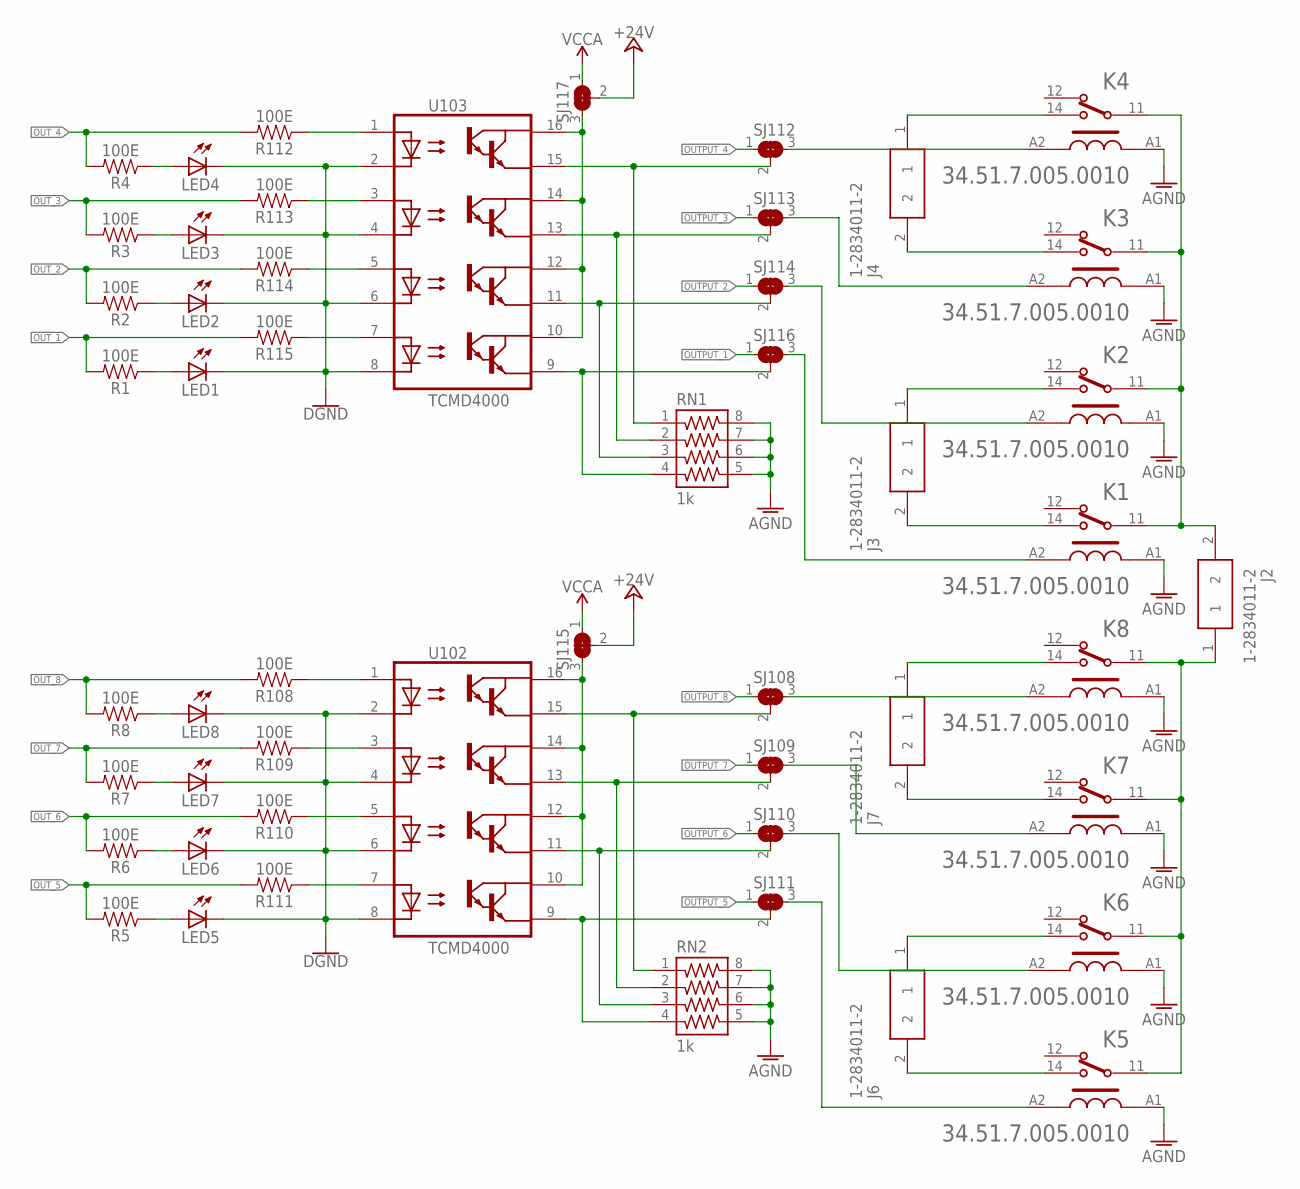
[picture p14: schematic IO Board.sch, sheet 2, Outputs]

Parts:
J2, J3, J4, J6, J7: 1-2834011-2; 128340112
K1, K2, K3, K4, K5, K6, K7, K8: FINDER_34.51.7.005.0010FINDER_34.51.7.005.0010_0_0; FINDER_34.51.7.005.0010_0
LED1, LED2, LED3, LED4, LED5, LED6, LED7, LED8: LEDCHIP-LED0805; CHIP-LED0805
R1, R2, R3, R4, R5, R6, R7, R8, R108, R109, R110, R111, R112, R113, R114, R115: 100E; 0805
RN1, RN2: 1k; 743-8NS
SJ108, SJ109, SJ110, SJ111, SJ112, SJ113, SJ114, SJ115, SJ116, SJ117: SOLDERJUMPER_2WAY; SOLDERJUMPER_2WAY_OPEN_NOPASTE
U102, U103: TCMD4000; SOIC127P686X201-16N

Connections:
+24V: SJ115.2, SJ117.2; also elsewhere on the board
AGND: K1.A1, K2.A1, K3.A1, K4.A1, K5.A1, K6.A1, K7.A1, K8.A1, RN1.5, RN1.6, RN1.7, RN1.8, RN2.5, RN2.6, RN2.7, RN2.8; also elsewhere on the board
GND: LED1.C, LED2.C, LED3.C, LED4.C, LED5.C, LED6.C, LED7.C, LED8.C, U102.2 (C1), U102.4 (C2), U102.6 (C3), U102.8 (C4), U103.2 (C1), U103.4 (C2), U103.6 (C3), U103.8 (C4); also elsewhere on the board
unnamed: K3.A2, SJ113.3
unnamed: RN1.3, SJ114.2, U103.11 (E3)
unnamed: RN1.4, SJ116.2, U103.9 (E4)
unnamed: K8.A2, SJ108.3
unnamed: K7.A2, SJ109.3
unnamed: RN2.3, SJ110.2, U102.11 (E3)
unnamed: RN2.4, SJ111.2, U102.9 (E4)
unnamed: K4.A2, SJ112.3
unnamed: LED4.A, R4.1
unnamed: LED8.A, R8.1
unnamed: LED7.A, R7.1
unnamed: LED6.A, R6.1
unnamed: LED5.A, R5.1
unnamed: R108.1, U102.1 (A1)
unnamed: R109.1, U102.3 (A2)
unnamed: R110.1, U102.5 (A3)
unnamed: R111.1, U102.7 (A4)
unnamed: SJ115.3, U102.10 (CO4), U102.12 (CO3), U102.14 (CO2), U102.16 (CO1)
unnamed: RN2.2, SJ109.2, U102.13 (E2)
unnamed: LED3.A, R3.1
unnamed: RN2.1, SJ108.2, U102.15 (E1)
unnamed: K5.A2, SJ111.3
unnamed: J4.1, K4.14
unnamed: J4.2, K3.14
unnamed: J3.1, K2.14
unnamed: LED2.A, R2.1
unnamed: LED1.A, R1.1
unnamed: J3.2, K1.14
unnamed: J2.1, K5.11, K6.11, K7.11, K8.11
unnamed: R112.1, U103.1 (A1)
unnamed: J7.1, K8.14
unnamed: J2.2, K1.11, K2.11, K3.11, K4.11
unnamed: K6.A2, SJ110.3
unnamed: J7.2, K7.14
unnamed: J6.1, K6.14
unnamed: K2.A2, SJ114.3
unnamed: R113.1, U103.3 (A2)
unnamed: R114.1, U103.5 (A3)
unnamed: R115.1, U103.7 (A4)
unnamed: SJ117.3, U103.10 (CO4), U103.12 (CO3), U103.14 (CO2), U103.16 (CO1)
unnamed: RN1.2, SJ113.2, U103.13 (E2)
unnamed: RN1.1, SJ112.2, U103.15 (E1)
unnamed: K1.A2, SJ116.3
unnamed: J6.2, K5.14
OUTPUT_1: SJ116.1; also elsewhere on the board
OUTPUT_2: SJ114.1; also elsewhere on the board
OUTPUT_3: SJ113.1; also elsewhere on the board
OUTPUT_4: SJ112.1; also elsewhere on the board
OUTPUT_5: SJ111.1; also elsewhere on the board
OUTPUT_6: SJ110.1; also elsewhere on the board
OUTPUT_7: SJ109.1; also elsewhere on the board
OUTPUT_8: SJ108.1; also elsewhere on the board
OUT_1: R1.2, R115.2; also elsewhere on the board
OUT_2: R2.2, R114.2; also elsewhere on the board
OUT_3: R3.2, R113.2; also elsewhere on the board
OUT_4: R4.2, R112.2; also elsewhere on the board
OUT_5: R5.2, R111.2; also elsewhere on the board
OUT_6: R6.2, R110.2; also elsewhere on the board
OUT_7: R7.2, R109.2; also elsewhere on the board
OUT_8: R8.2, R108.2; also elsewhere on the board
VCCA: SJ115.1, SJ117.1; also elsewhere on the board

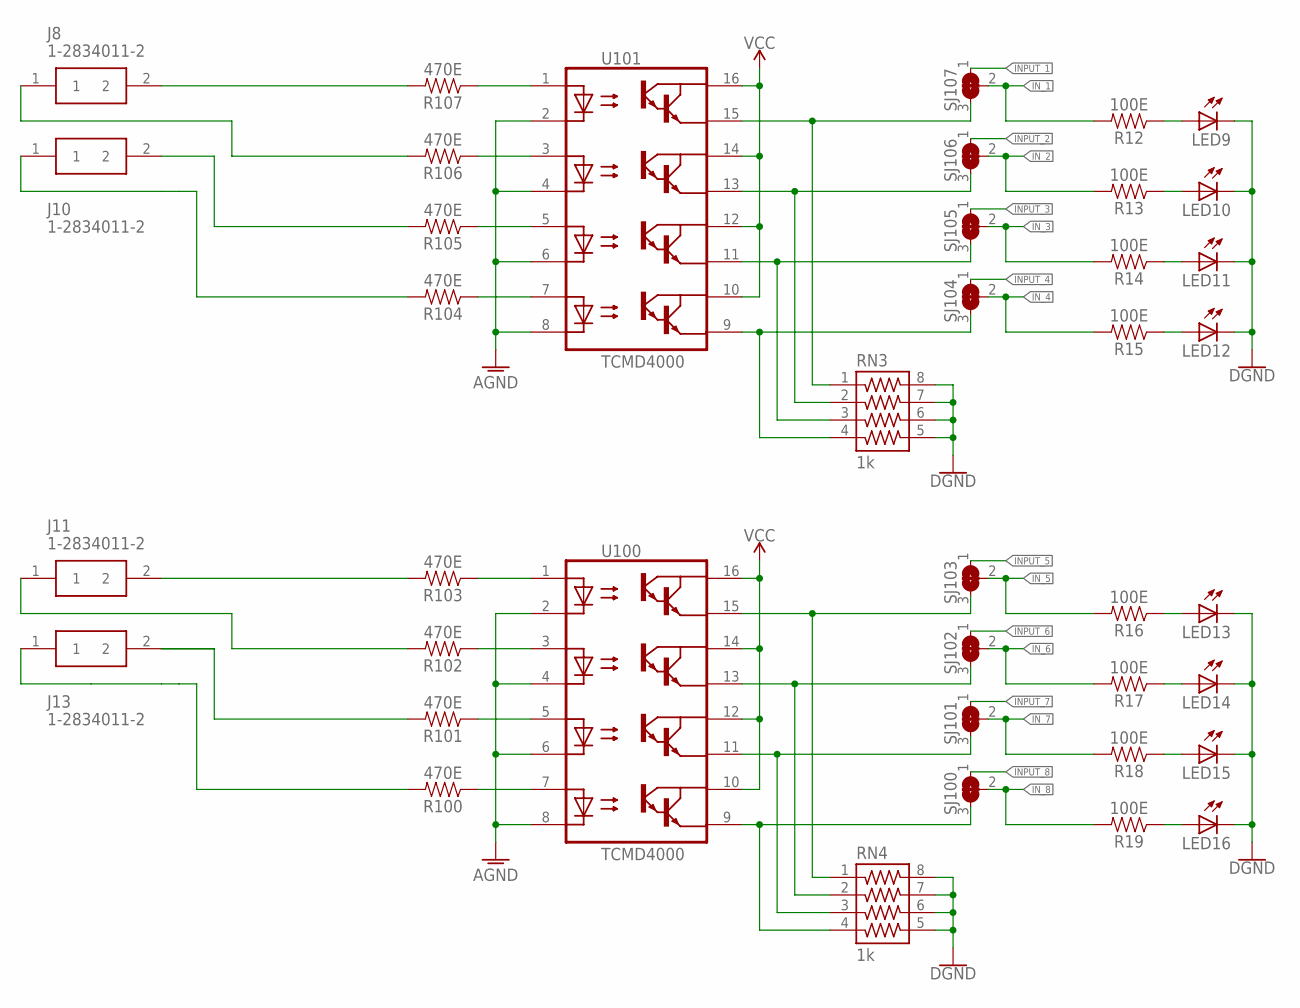
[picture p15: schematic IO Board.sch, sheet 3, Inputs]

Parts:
J8, J10, J11, J13: 1-2834011-2; 128340112
LED9, LED10, LED11, LED12, LED13, LED14, LED15, LED16: LEDCHIP-LED0805; CHIP-LED0805
R12, R13, R14, R15, R16, R17, R18, R19: 100E; 0805
R100, R101, R102, R103, R104, R105, R106, R107: 470E; 0805
RN3, RN4: 1k; 743-8NS
SJ100, SJ101, SJ102, SJ103, SJ104, SJ105, SJ106, SJ107: SOLDERJUMPER_2WAY; SOLDERJUMPER_2WAY_OPEN_NOPASTE
U100, U101: TCMD4000; SOIC127P686X201-16N

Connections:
AGND: U100.2 (C1), U100.4 (C2), U100.6 (C3), U100.8 (C4), U101.2 (C1), U101.4 (C2), U101.6 (C3), U101.8 (C4); also elsewhere on the board
GND: LED9.C, LED10.C, LED11.C, LED12.C, LED13.C, LED14.C, LED15.C, LED16.C, RN3.5, RN3.6, RN3.7, RN3.8, RN4.5, RN4.6, RN4.7, RN4.8; also elsewhere on the board
INPUT_1: SJ107.1; also elsewhere on the board
INPUT_2: SJ106.1; also elsewhere on the board
INPUT_3: SJ105.1; also elsewhere on the board
INPUT_4: SJ104.1; also elsewhere on the board
INPUT_5: SJ103.1; also elsewhere on the board
INPUT_6: SJ102.1; also elsewhere on the board
INPUT_7: SJ101.1; also elsewhere on the board
INPUT_8: SJ100.1; also elsewhere on the board
IN_1: R12.2, SJ107.2; also elsewhere on the board
IN_2: R13.2, SJ106.2; also elsewhere on the board
IN_3: R14.2, SJ105.2; also elsewhere on the board
IN_4: R15.2, SJ104.2; also elsewhere on the board
IN_5: R16.2, SJ103.2; also elsewhere on the board
IN_6: R17.2, SJ102.2; also elsewhere on the board
IN_7: R18.2, SJ101.2; also elsewhere on the board
IN_8: R19.2, SJ100.2; also elsewhere on the board
unnamed: LED9.A, R12.1
unnamed: LED10.A, R13.1
unnamed: LED11.A, R14.1
unnamed: LED12.A, R15.1
unnamed: R107.1, U101.1 (A1)
unnamed: R106.1, U101.3 (A2)
unnamed: J8.1, R106.2
unnamed: J13.2, R101.2
unnamed: R105.1, U101.5 (A3)
unnamed: R104.1, U101.7 (A4)
unnamed: LED13.A, R16.1
unnamed: RN3.2, SJ106.3, U101.13 (E2)
unnamed: RN3.1, SJ107.3, U101.15 (E1)
unnamed: LED14.A, R17.1
unnamed: LED15.A, R18.1
unnamed: LED16.A, R19.1
unnamed: R103.1, U100.1 (A1)
unnamed: R102.1, U100.3 (A2)
unnamed: R101.1, U100.5 (A3)
unnamed: R100.1, U100.7 (A4)
unnamed: RN4.2, SJ102.3, U100.13 (E2)
unnamed: RN4.1, SJ103.3, U100.15 (E1)
unnamed: RN4.3, SJ101.3, U100.11 (E3)
unnamed: RN4.4, SJ100.3, U100.9 (E4)
unnamed: J8.2, R107.2
unnamed: J10.2, R105.2
unnamed: J10.1, R104.2
unnamed: RN3.3, SJ105.3, U101.11 (E3)
unnamed: RN3.4, SJ104.3, U101.9 (E4)
unnamed: J11.2, R103.2
unnamed: J11.1, R102.2
unnamed: J13.1, R100.2
VCC: U100.10 (CO4), U100.12 (CO3), U100.14 (CO2), U100.16 (CO1), U101.10 (CO4), U101.12 (CO3), U101.14 (CO2), U101.16 (CO1); also elsewhere on the board

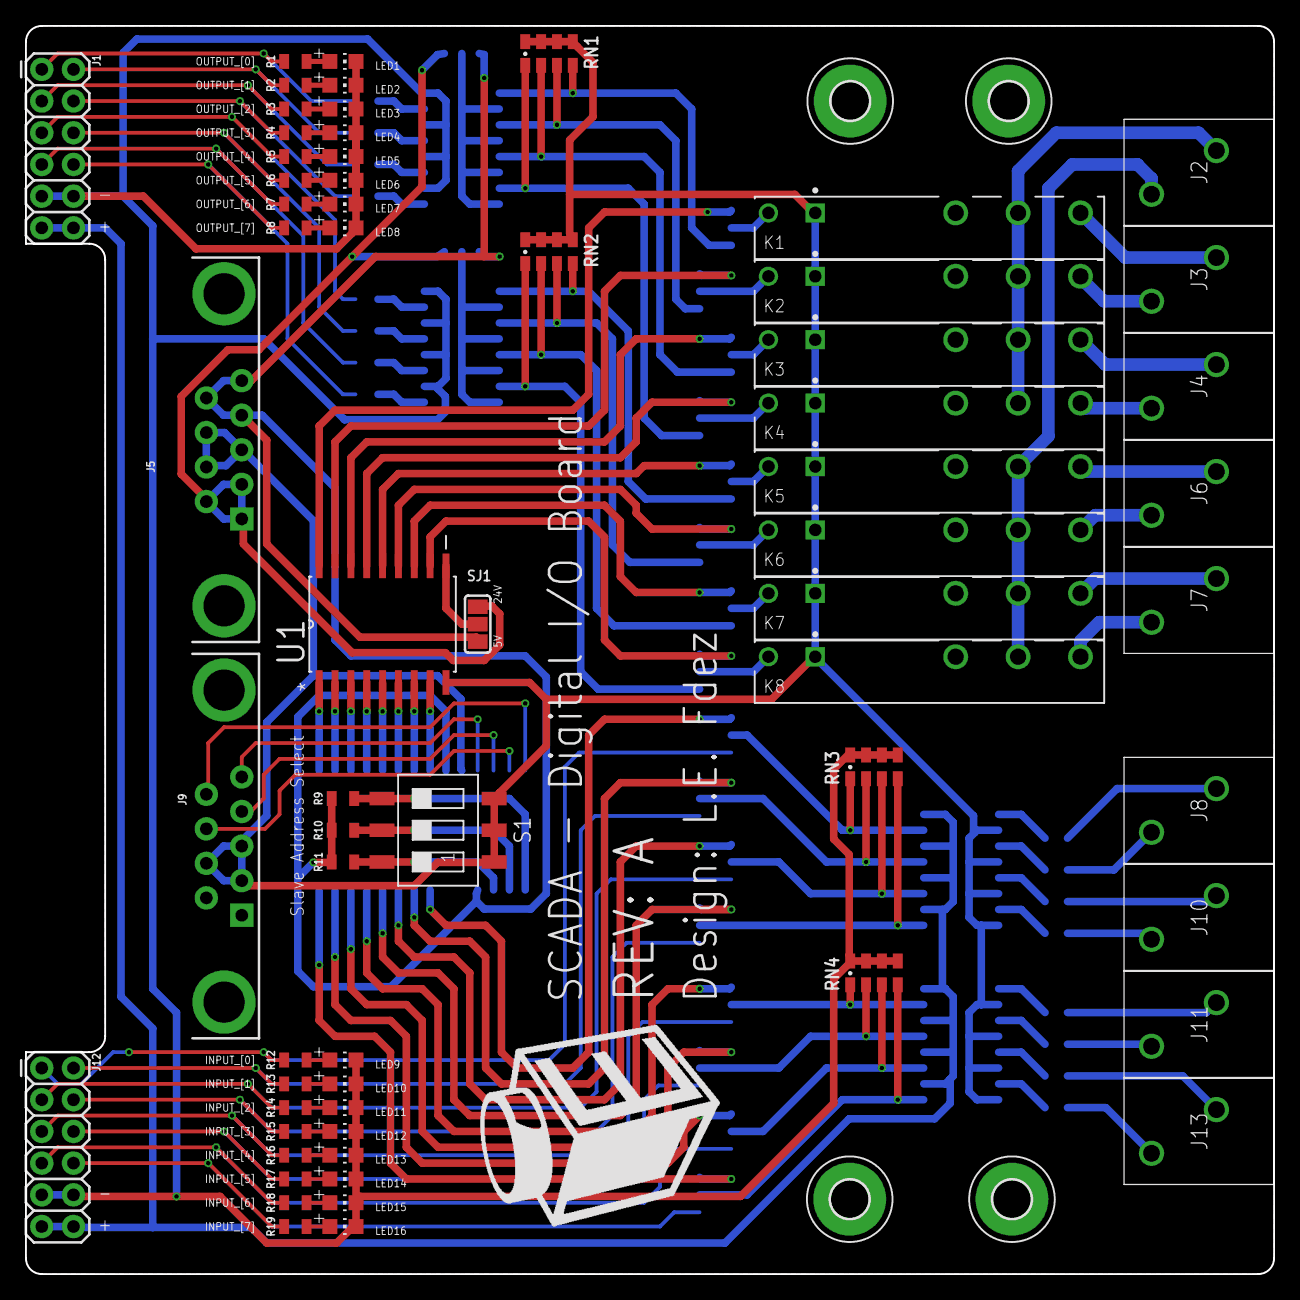
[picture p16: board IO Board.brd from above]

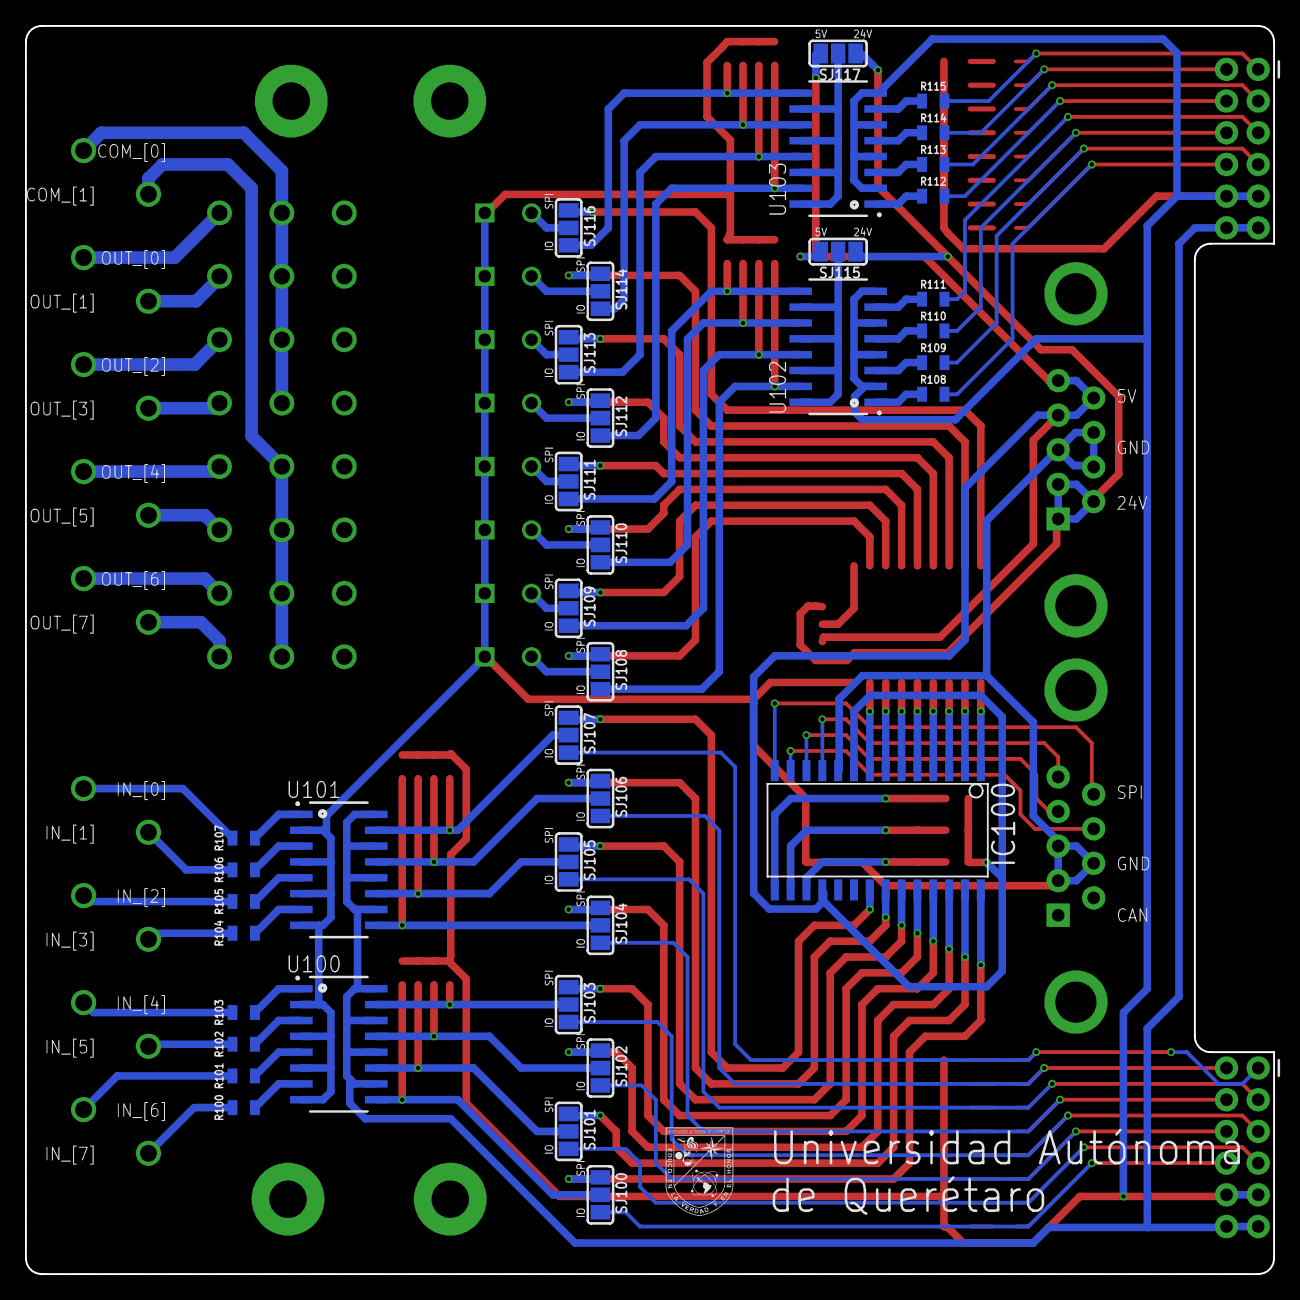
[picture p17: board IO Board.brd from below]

Board: 2 copper layers, 100.0 x 100.0 mm, 106 parts (39 on the bottom side), 129 nets.

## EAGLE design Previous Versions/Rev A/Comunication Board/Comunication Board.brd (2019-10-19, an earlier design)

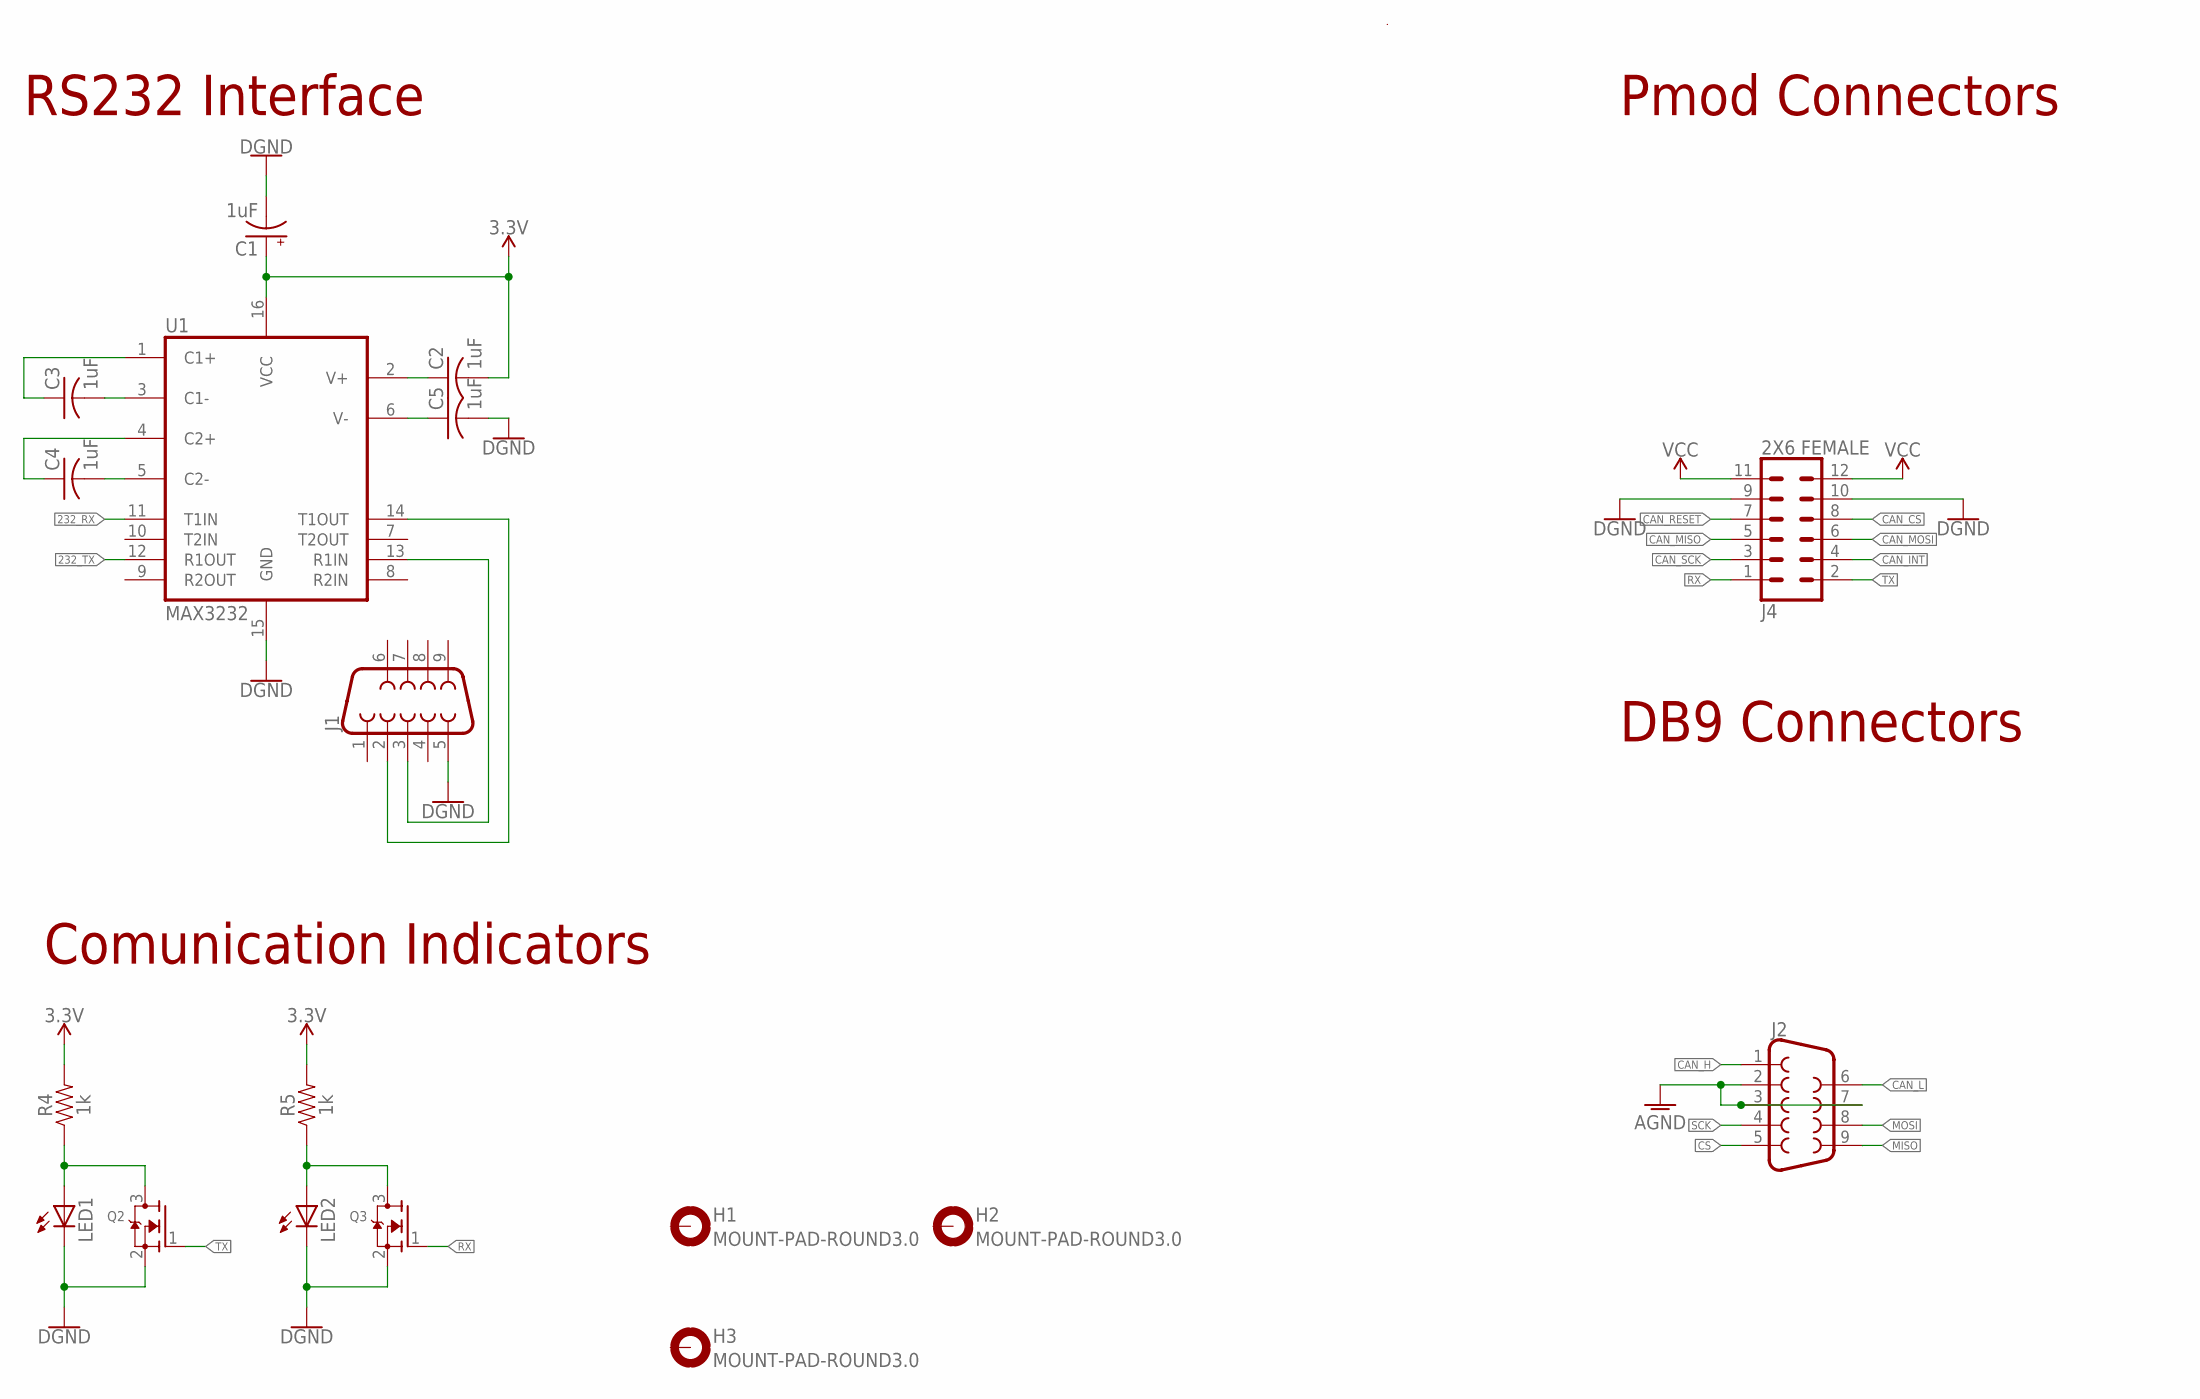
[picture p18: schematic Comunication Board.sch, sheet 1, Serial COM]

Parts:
C1: 1uF; PANASONIC_B
C2, C3, C4, C5: 1uF; C0805
H1, H2, H3: MOUNT-PAD-ROUND3.0; 3,0-PAD
J1, J2: DB9FEMALE; DB9
J4: 2X6 FEMALE; 2X6
LED1, LED2: LEDCHIP-LED0805; CHIP-LED0805
Q2, Q3: MOSFET-NWAVE; SOT23-W
R4, R5: 1k; 0805
U1: MAX3232; SO16

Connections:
3.3V: C1.+, C2.2, R4.2, R5.2, U1.16 (VCC); also elsewhere on the board
232_RX: U1.11 (T1IN); also elsewhere on the board
232_TX: U1.12 (R1OUT); also elsewhere on the board
AGND: J2.2, J2.3, J2.7
CAN_CS: J4.8; also elsewhere on the board
CAN_H: J2.1; also elsewhere on the board
CAN_INT: J4.4; also elsewhere on the board
CAN_L: J2.6; also elsewhere on the board
CAN_MISO: J4.5; also elsewhere on the board
CAN_MOSI: J4.6; also elsewhere on the board
CAN_RESET: J4.7; also elsewhere on the board
CAN_SCK: J4.3; also elsewhere on the board
CS: J2.5
GND: C1.-, C5.2, J1.5, J4.9, J4.10, LED1.C, LED2.C, Q2.2 (S), Q3.2 (S), U1.15 (GND); also elsewhere on the board
MISO: J2.9
MOSI: J2.8
unnamed: C3.2, U1.3 (C1-)
unnamed: C2.1, U1.2 (V+)
unnamed: C3.1, U1.1 (C1+)
unnamed: C4.1, U1.4 (C2+)
unnamed: C4.2, U1.5 (C2-)
unnamed: C5.1, U1.6 (V-)
unnamed: LED2.A, Q3.3 (D), R5.1
unnamed: J1.2, U1.14 (T1OUT)
unnamed: J1.3, U1.13 (R1IN)
unnamed: LED1.A, Q2.3 (D), R4.1
RX: J4.1, Q3.1 (G); also elsewhere on the board
SCK: J2.4
TX: J4.2, Q2.1 (G); also elsewhere on the board
VCC: J4.11, J4.12

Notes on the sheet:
RS232 Interface
Comunication Indicators
Pmod Connectors
DB9 Connectors

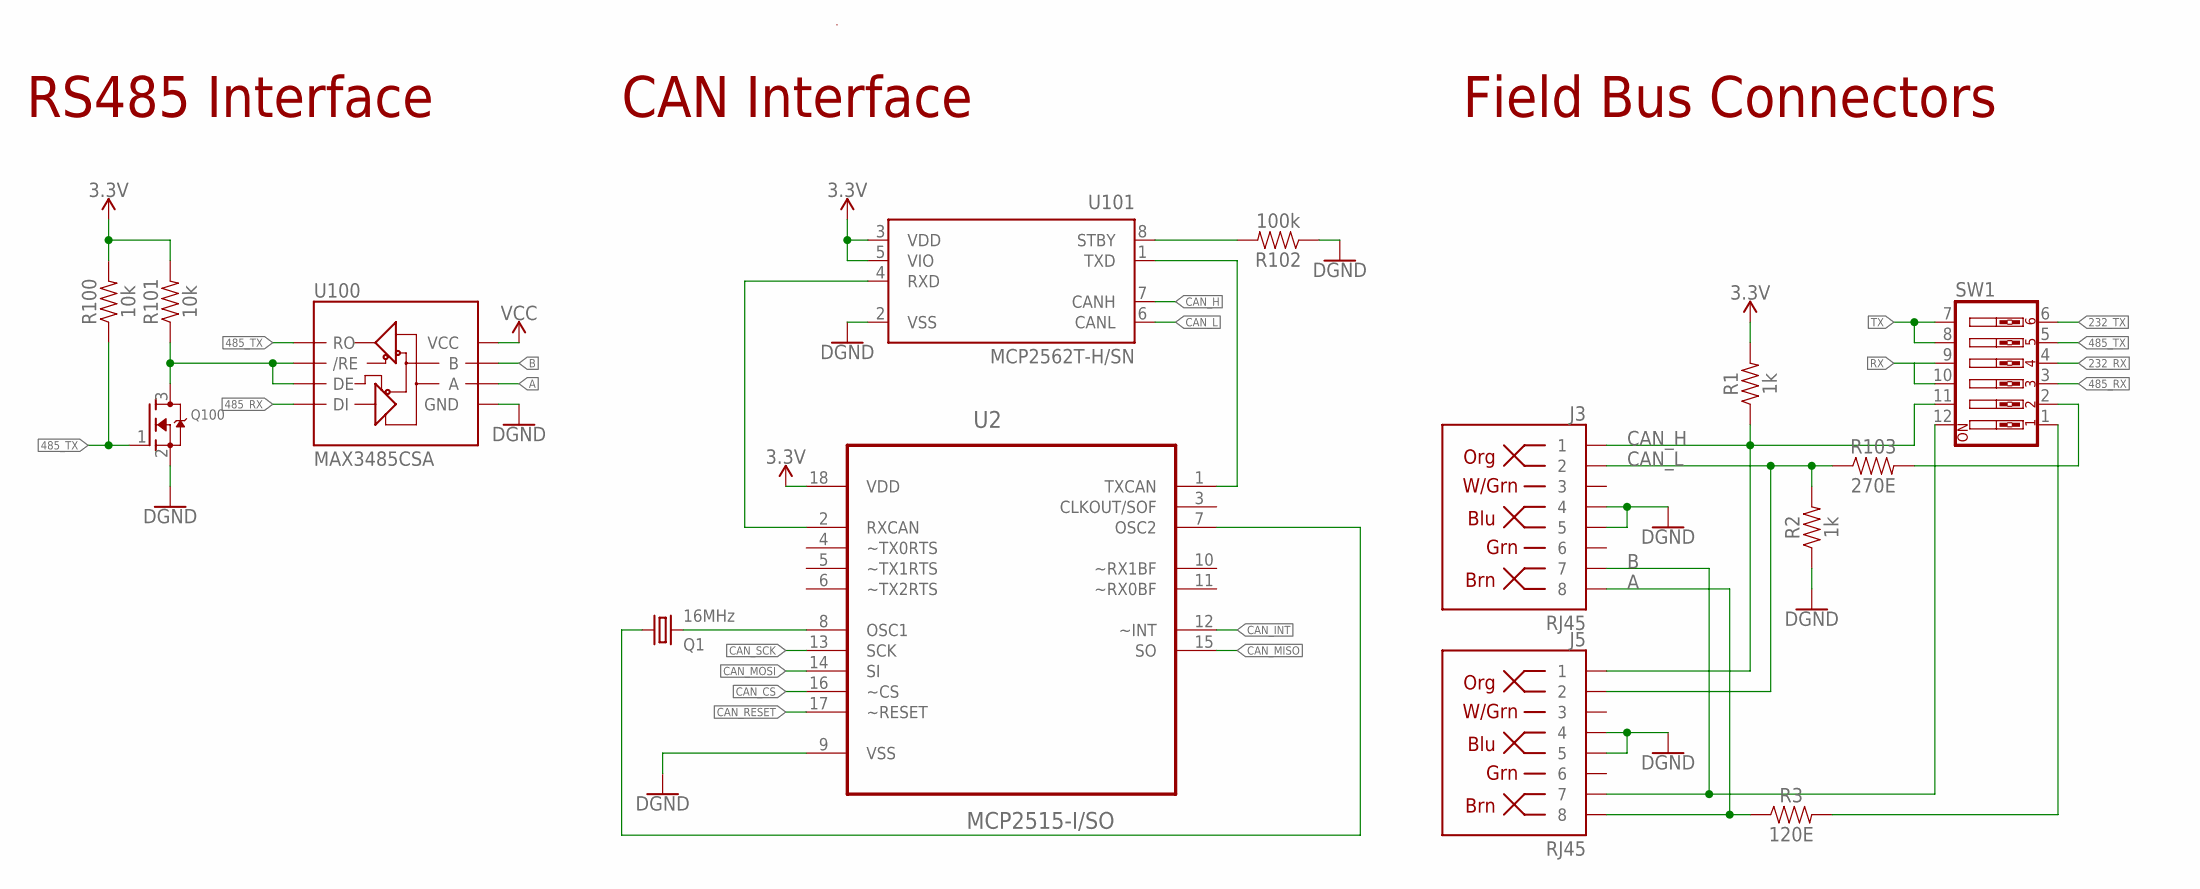
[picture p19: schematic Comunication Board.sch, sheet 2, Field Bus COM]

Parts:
J3, J5: RJ45; RJ45-8
Q1: 16MHz; HC49UP
Q100: MOSFET-NWAVE; SOT23-W
R1, R2: 1k; 0805
R3: 120E; 0805
R100, R101: 10k; 0805
R102: 100k; 0805
R103: 270E; 0805
SW1: SW_DIP-6; EDG-06
U2: MCP2515-I/SO; SOIC127P1034X264-18N
U100: MAX3485CSA; SO08
U101: MCP2562T-H/SN; SOIC127P600X175-8N

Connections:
3.3V: R1.2, R100.2, R101.2, U2.18 (VDD), U101.3 (VDD), U101.5 (VIO); also elsewhere on the board
5V: U100.8 (VCC)
232_RX: SW1.4; also elsewhere on the board
232_TX: SW1.6; also elsewhere on the board
485_RX: SW1.3, U100.4 (DI)
485_TX: Q100.1 (G), R100.1, SW1.5, U100.1 (RO)
A: J3.8, J5.8, R3.1, U100.6 (A)
B: J3.7, J5.7, SW1.12, U100.7 (B)
CAN_CS: U2.16 (~CS); also elsewhere on the board
CAN_H: J3.1, J5.1, R1.1, SW1.11, U101.7 (CANH); also elsewhere on the board
CAN_INT: U2.12 (~INT); also elsewhere on the board
CAN_L: J3.2, J5.2, R2.2, R103.1, U101.6 (CANL); also elsewhere on the board
CAN_MISO: U2.15 (SO); also elsewhere on the board
CAN_MOSI: U2.14 (SI); also elsewhere on the board
CAN_RESET: U2.17 (~RESET); also elsewhere on the board
CAN_SCK: U2.13 (SCK); also elsewhere on the board
GND: J3.4, J3.5, J5.4, J5.5, Q100.2 (S), R2.1, R102.1, U2.9 (VSS), U100.5 (GND), U101.2 (VSS); also elsewhere on the board
unnamed: R103.2, SW1.2
unnamed: U2.1 (TXCAN), U101.1 (TXD)
unnamed: U2.2 (RXCAN), U101.4 (RXD)
unnamed: Q1.2, U2.8 (OSC1)
unnamed: R3.2, SW1.1
unnamed: Q1.1, U2.7 (OSC2)
unnamed: Q100.3 (D), R101.1, U100.2 (/RE), U100.3 (DE)
unnamed: R102.2, U101.8 (STBY)
RX: SW1.9, SW1.10; also elsewhere on the board
TX: SW1.7, SW1.8; also elsewhere on the board

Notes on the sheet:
RS485 Interface
CAN Interface
Field Bus Connectors

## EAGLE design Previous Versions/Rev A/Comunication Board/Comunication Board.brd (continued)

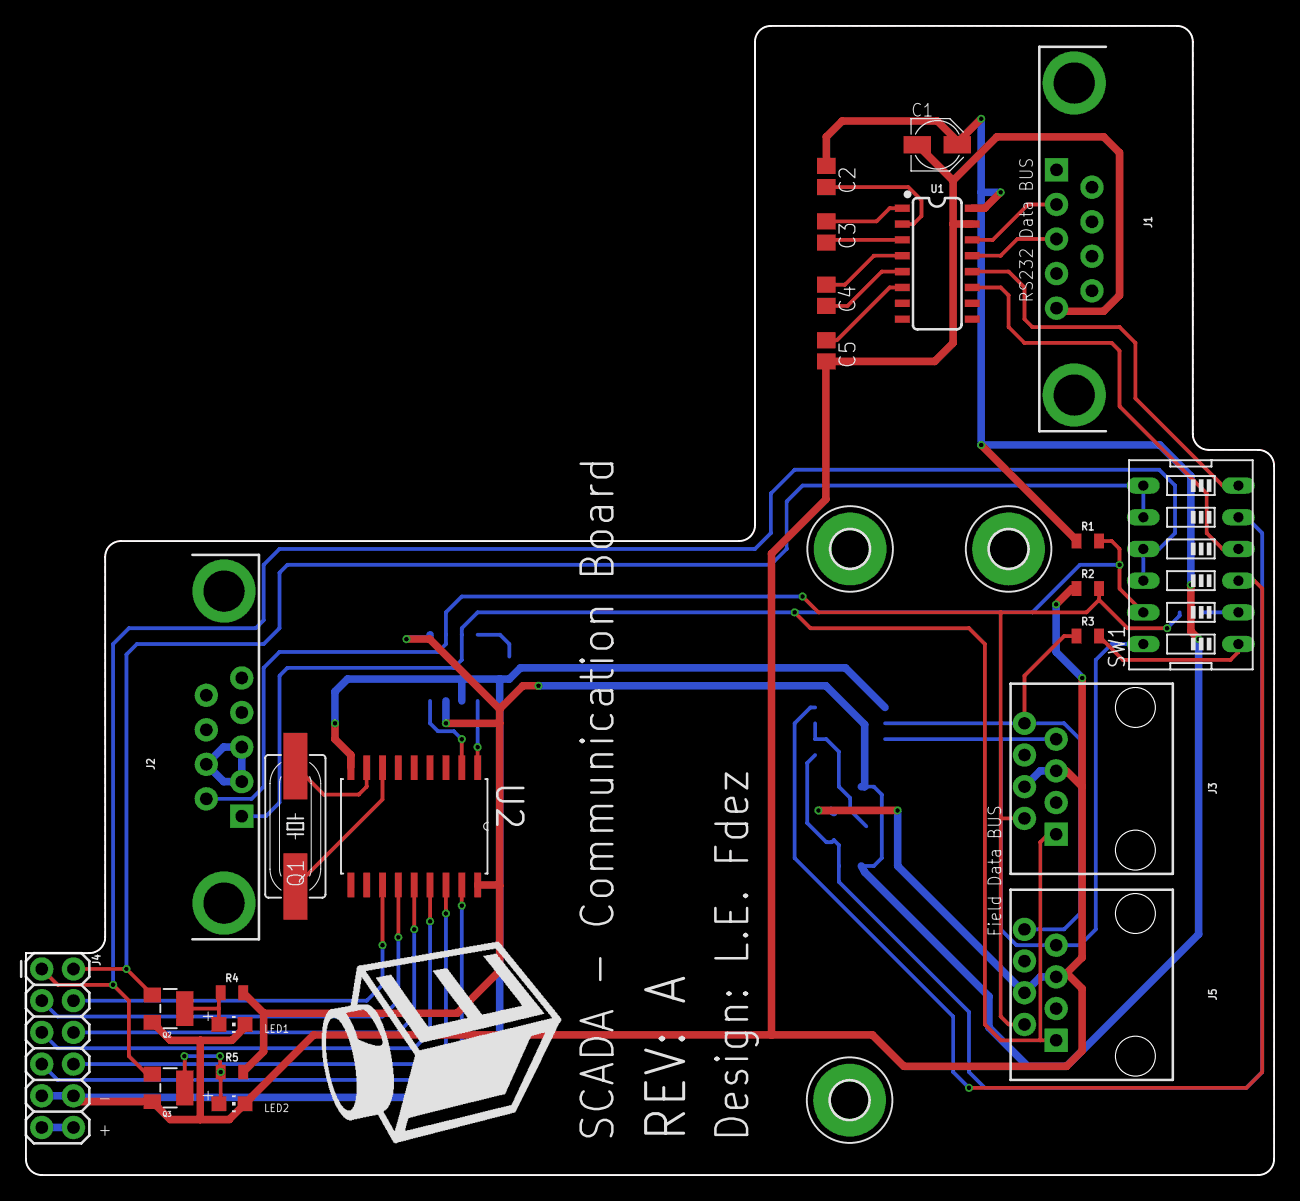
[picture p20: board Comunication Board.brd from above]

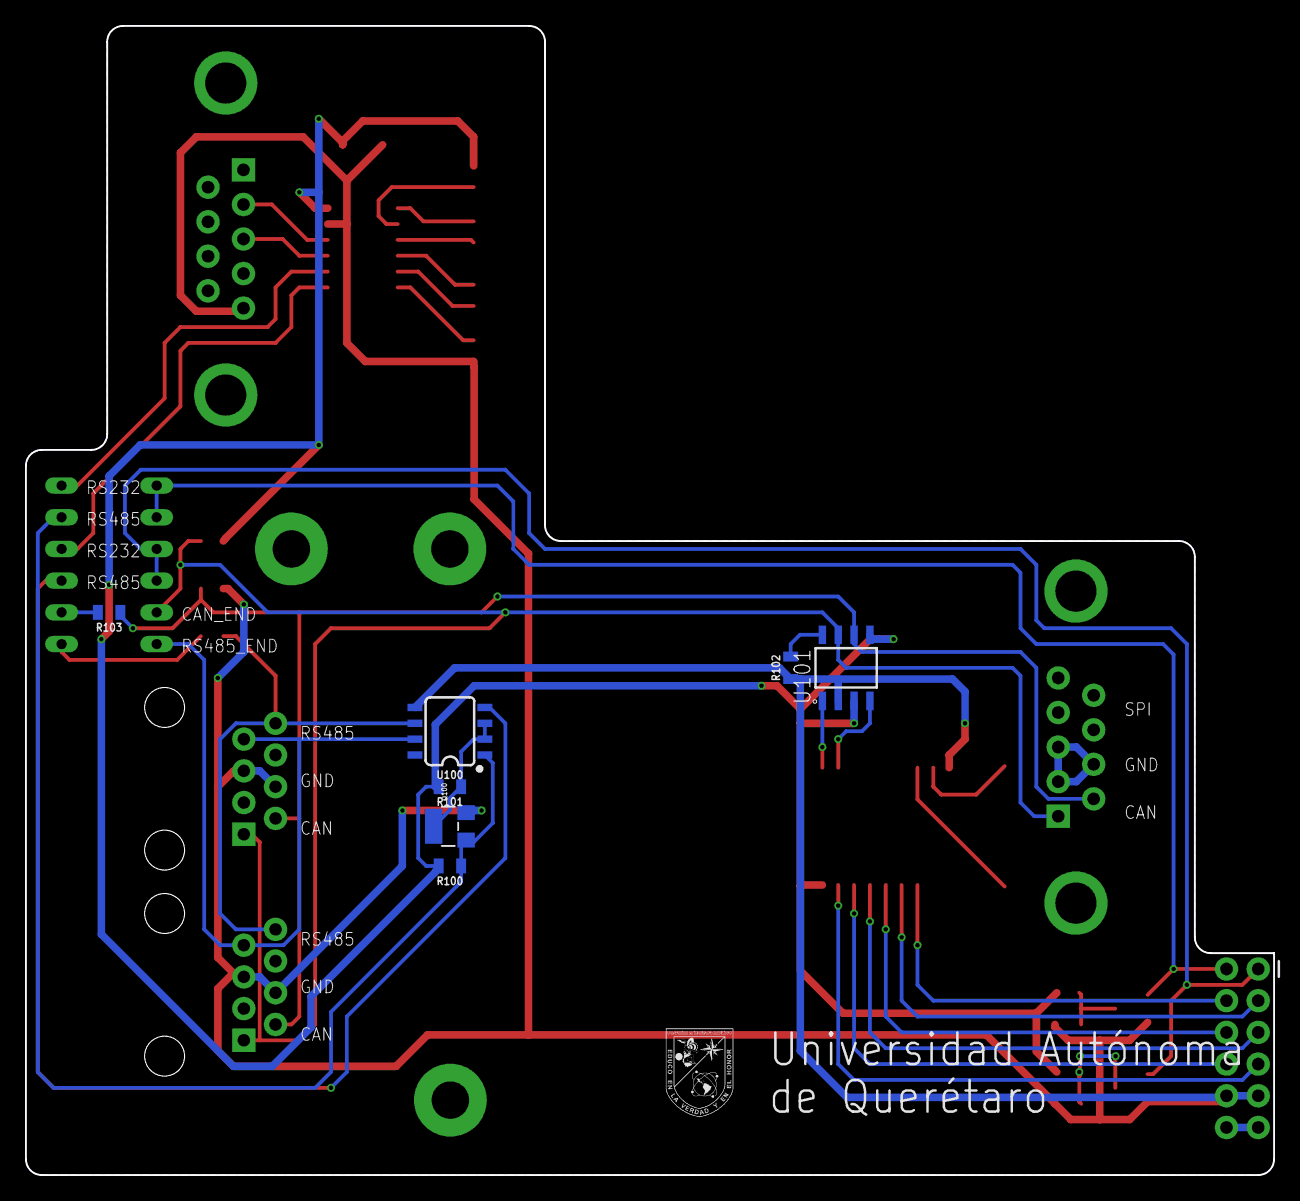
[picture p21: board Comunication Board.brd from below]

Board: 2 copper layers, 100.0 x 92.1 mm, 33 parts (7 on the bottom side), 38 nets.

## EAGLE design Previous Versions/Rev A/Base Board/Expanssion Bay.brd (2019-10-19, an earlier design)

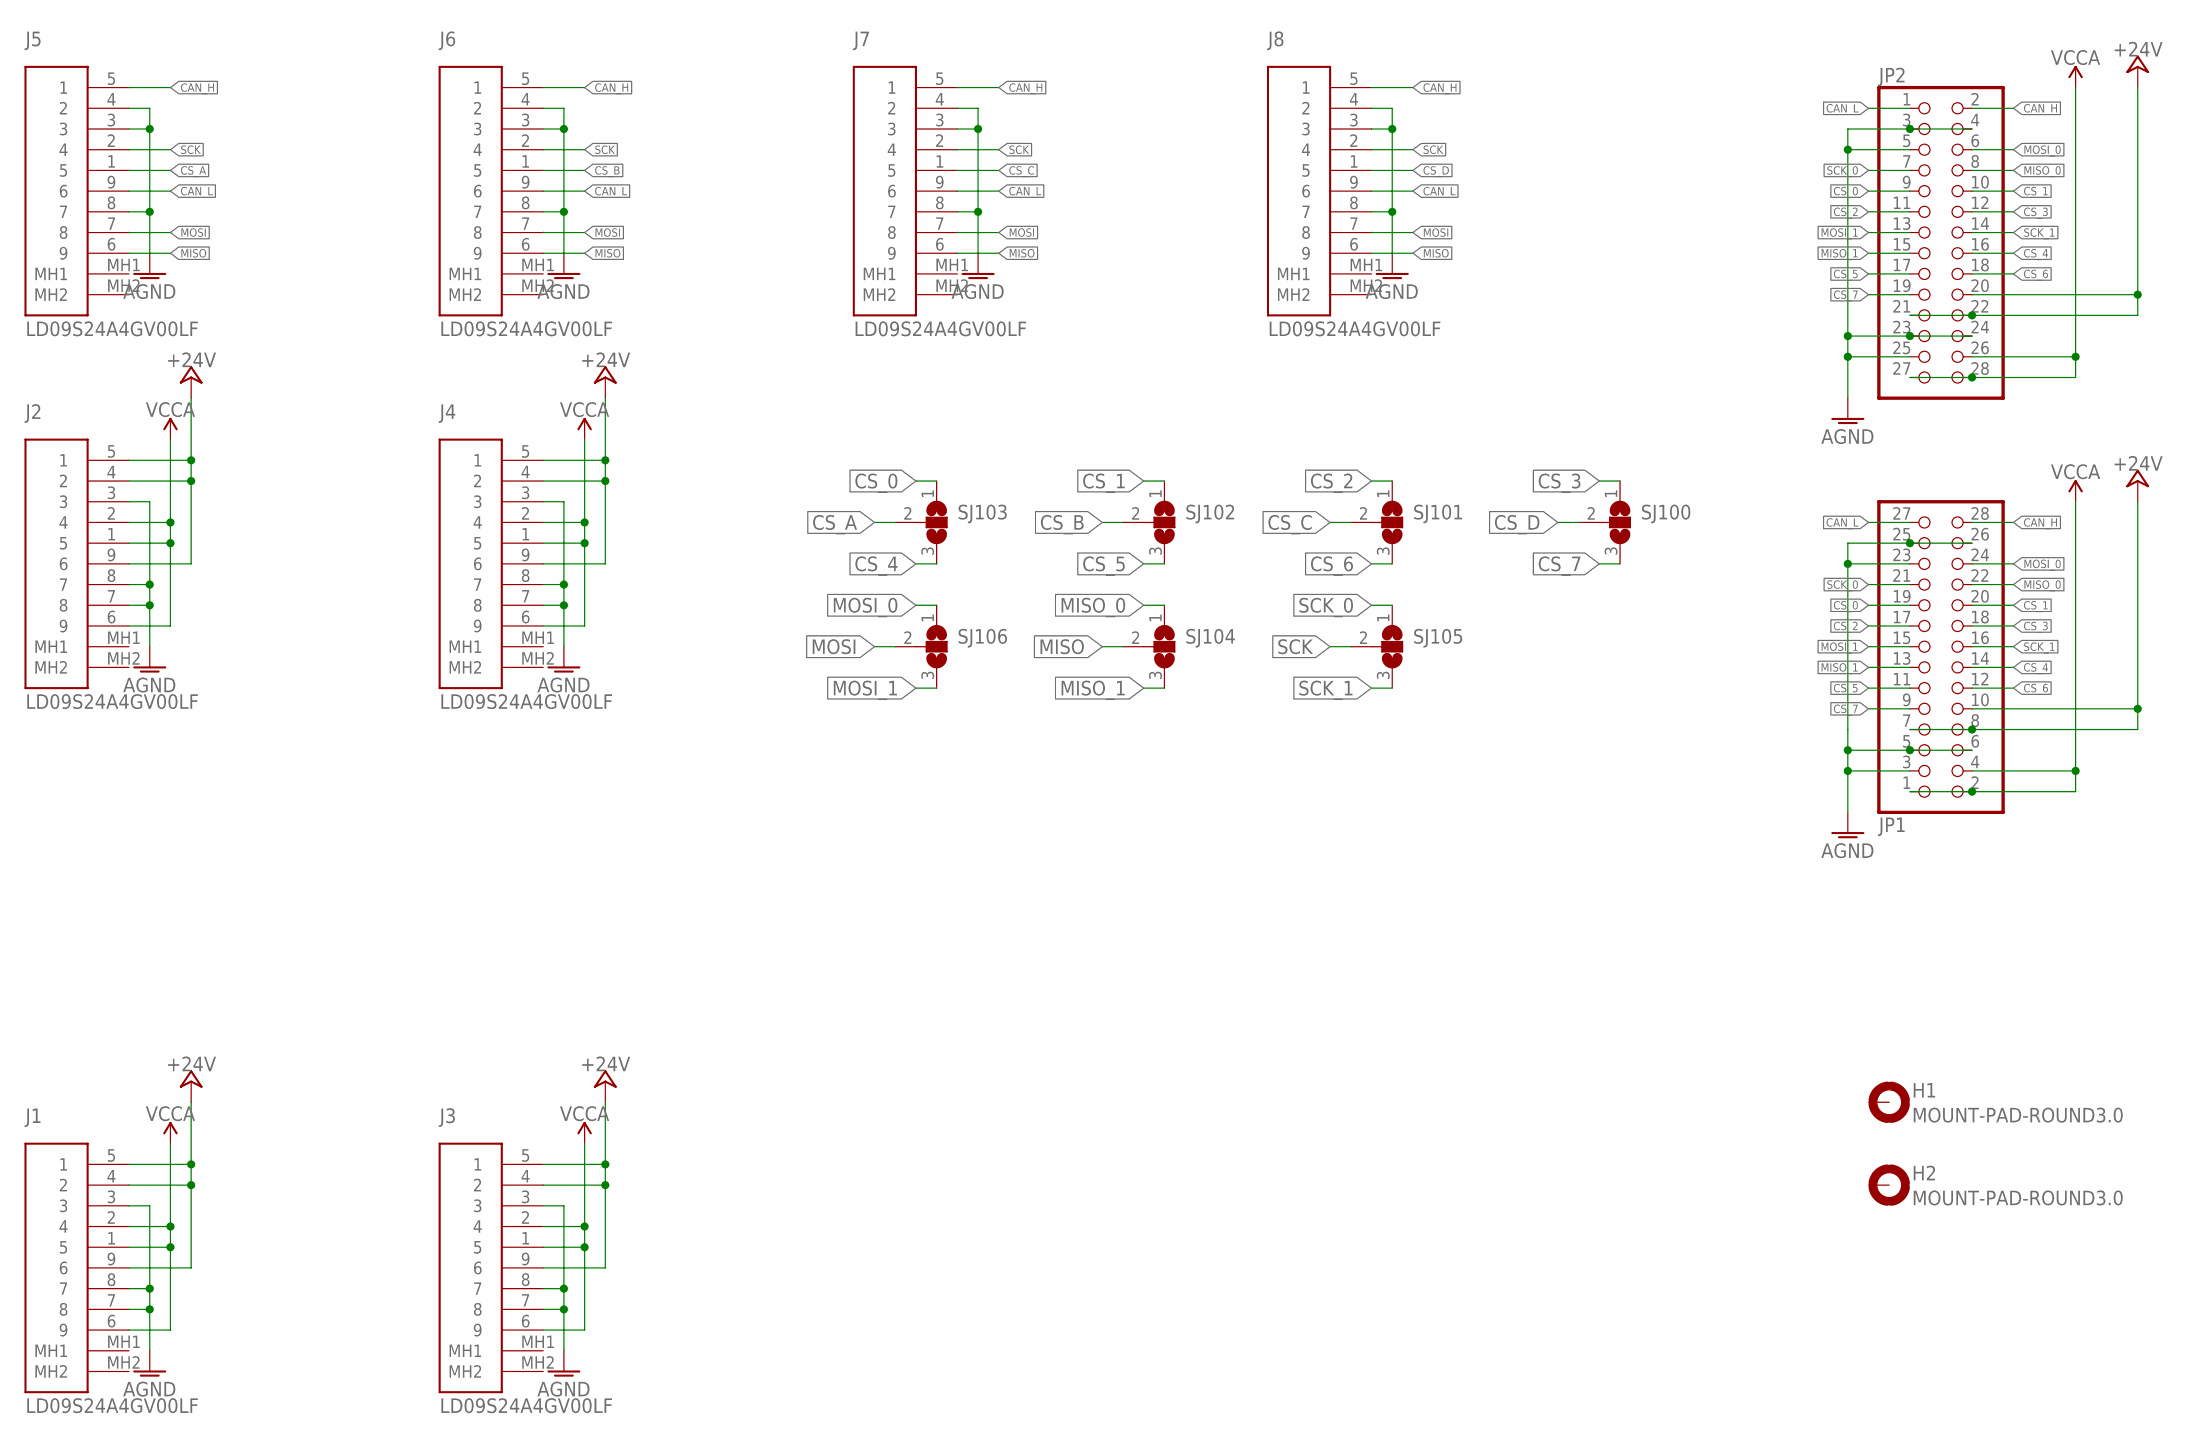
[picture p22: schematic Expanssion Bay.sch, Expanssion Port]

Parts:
H1, H2: MOUNT-PAD-ROUND3.0; 3,0-PAD
J1, J2, J3, J4, J5, J6, J7, J8: LD09S24A4GV00LF
JP1, JP2: PINHD-2X14/90; 2X14/90
SJ100, SJ101, SJ102, SJ103, SJ104, SJ105, SJ106: SJ2W; SJ_2

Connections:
+24V: J1.4 (2), J1.5 (1), J1.9 (6), J2.4 (2), J2.5 (1), J2.9 (6), J3.4 (2), J3.5 (1), J3.9 (6), J4.4 (2), J4.5 (1), J4.9 (6), JP1.7, JP1.8, JP1.10, JP2.20, JP2.21, JP2.22
AGND: J1.3, J1.7 (8), J1.8 (7), J2.3, J2.7 (8), J2.8 (7), J3.3, J3.7 (8), J3.8 (7), J4.3, J4.7 (8), J4.8 (7), J5.3, J5.4 (2), J5.8 (7), J6.3, J6.4 (2), J6.8 (7), J7.3, J7.4 (2), J7.8 (7), J8.3, J8.4 (2), J8.8 (7), JP1.3, JP1.5, JP1.6, JP1.23, JP1.25, JP1.26, JP2.3, JP2.4, JP2.5, JP2.23, JP2.24, JP2.25
CAN_H: J5.5 (1), J6.5 (1), J7.5 (1), J8.5 (1), JP1.28, JP2.2
CAN_L: J5.9 (6), J6.9 (6), J7.9 (6), J8.9 (6), JP1.27, JP2.1
CS_0: JP1.19, JP2.9, SJ103.1
CS_1: JP1.20, JP2.10, SJ102.1
CS_2: JP1.17, JP2.11, SJ101.1
CS_3: JP1.18, JP2.12, SJ100.1
CS_4: JP1.14, JP2.16, SJ103.3
CS_5: JP1.11, JP2.17, SJ102.3
CS_6: JP1.12, JP2.18, SJ101.3
CS_7: JP1.9, JP2.19, SJ100.3
CS_A: J5.1 (5), SJ103.2
CS_B: J6.1 (5), SJ102.2
CS_C: J7.1 (5), SJ101.2
CS_D: J8.1 (5), SJ100.2
MISO: J5.6 (9), J6.6 (9), J7.6 (9), J8.6 (9), SJ104.2
MISO_0: JP1.22, JP2.8, SJ104.1
MISO_1: JP1.13, JP2.15, SJ104.3
MOSI: J5.7 (8), J6.7 (8), J7.7 (8), J8.7 (8), SJ106.2
MOSI_0: JP1.24, JP2.6, SJ106.1
MOSI_1: JP1.15, JP2.13, SJ106.3
SCK: J5.2 (4), J6.2 (4), J7.2 (4), J8.2 (4), SJ105.2
SCK_0: JP1.21, JP2.7, SJ105.1
SCK_1: JP1.16, JP2.14, SJ105.3
VCCA: J1.1 (5), J1.2 (4), J1.6 (9), J2.1 (5), J2.2 (4), J2.6 (9), J3.1 (5), J3.2 (4), J3.6 (9), J4.1 (5), J4.2 (4), J4.6 (9), JP1.1, JP1.2, JP1.4, JP2.26, JP2.27, JP2.28

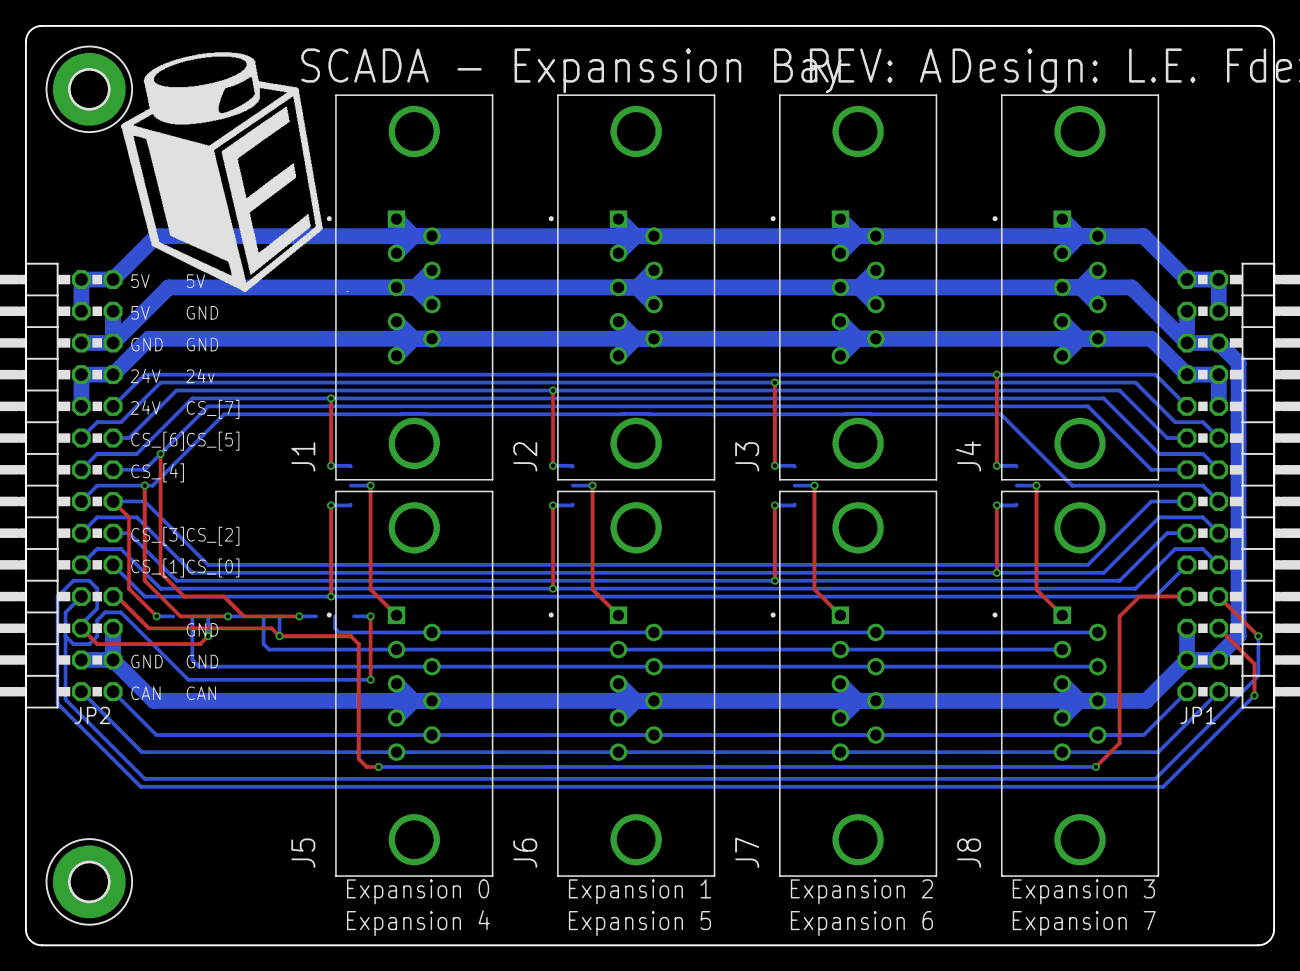
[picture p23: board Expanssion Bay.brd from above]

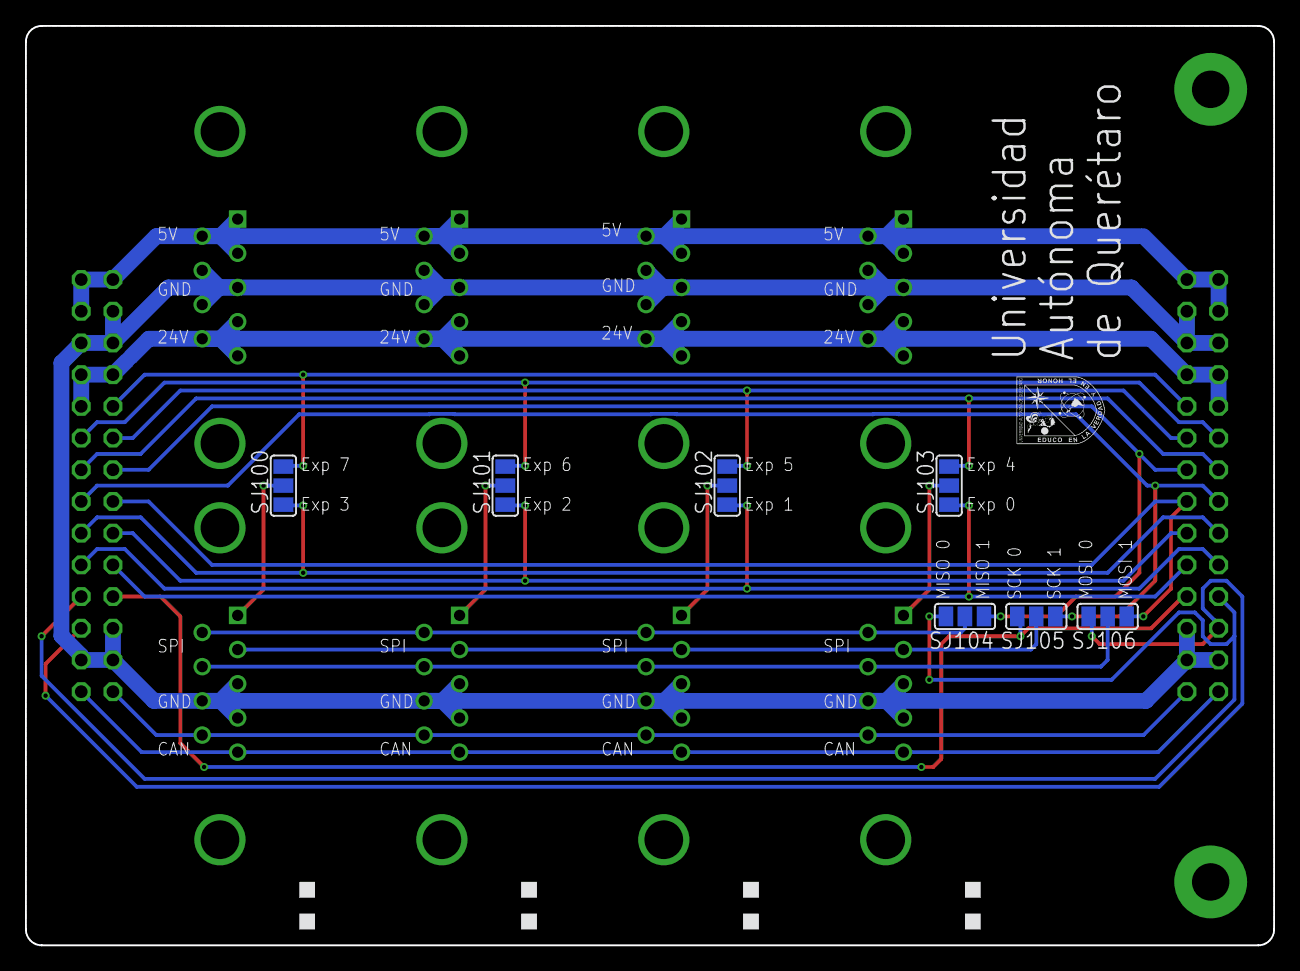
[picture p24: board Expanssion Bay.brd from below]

Board: 2 copper layers, 100.0 x 73.7 mm, 19 parts (7 on the bottom side), 26 nets.

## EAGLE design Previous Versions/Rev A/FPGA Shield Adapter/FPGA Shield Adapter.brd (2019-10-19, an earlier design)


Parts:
H100, H101: MOUNT-PAD-ROUND3.0; 3,0-PAD
J1: CONN_20X2SHROUDED; 2X20_SHROUDED
J2: CONN_05X2SHD; 2X5-SHROUDED
S1, S2: MOMENTARY-SWITCH-SPST-SMD-5.2MM; TACTILE_SWITCH_SMD_5.2MM
U1, U2: ARDUINOR3NODIM; ARDUINOR3-NODIM

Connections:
3.3V: J1.29, U1.3V, U2.3V
5V: J1.11, J2.1, U1.5V, U2.5V
ADC_0: J2.2, U2.A0
ADC_1: J2.3, U2.A1
ADC_2: J2.4, U2.A2
ADC_3: J2.5, U2.A3
ADC_4: J2.6, U1.A3
ADC_5: J2.7, U1.A2
ADC_6: J2.8, U1.A1
ADC_7: J2.9, U1.A0
D0: J1.40, U2.A5 (A5/SCL)
D1: J1.39, U2.A4 (A4/SDA)
D2: J1.38, U2.D0
D3: J1.37, U2.D1
D4: J1.36, U2.D2
D5: J1.35, U2.D3
D6: J1.34, U2.D4
D7: J1.33, U2.D5
D8: J1.32, U2.D6
D9: J1.31, U2.D7
D10: J1.28, U2.D8
D11: J1.27, U2.D9
D12: J1.26, U2.D10
D13: J1.25, U2.D11
D14: J1.24, U2.D12
D15: J1.23, U2.D13
D16: J1.22, U2.SDA
D17: J1.21, U2.SCL
D18: J1.20, U1.A4 (A4/SDA)
D19: J1.19, U1.A5 (A5/SCL)
D20: J1.18, U1.D0
D21: J1.17, U1.D1
D22: J1.16, U1.D2
D23: J1.15, U1.D3
D24: J1.14, U1.D4
D25: J1.13, U1.D5
D26: J1.10, U1.D6
D27: J1.9, U1.D7
D28: J1.8, U1.D8
D29: J1.7, U1.D9
D30: J1.6, U1.D10
D31: J1.5, U1.D11
D32: J1.4, U1.D12
D33: J1.3, U1.D13
D34: J1.2, U1.SDA
D35: J1.1, U1.SCL
GND: J1.12, J1.30, J2.10, S1.1, S2.1, U1.GND, U1.GND1, U1.GND2, U2.GND, U2.GND1, U2.GND2
unnamed: S2.3 (2), U2.RESET (/RESET)
unnamed: S1.3 (2), U1.RESET (/RESET)
VIN: U1.VIN, U2.VIN



Board: 2 copper layers, 106.7 x 73.7 mm, 8 parts (2 on the bottom side), 50 nets.

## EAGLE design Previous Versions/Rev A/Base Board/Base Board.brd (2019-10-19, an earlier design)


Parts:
C1, C2, C3, C4: 0.1uF; C0805
F1: FUSESH22,5; SH22,5
H1, H2, H100, H101, H102, H103: MOUNT-PAD-ROUND3.0; 3,0-PAD
IC1, IC2: TEL_5_SERIES
J1, J6, J7: 2X6 FEMALE; 2X6
J2, J4: LD09S24A4GV00LF
J3: CONN_20X2SHROUDED; 2X20_SHROUDED
J5: CONN_02POLAR_LOCK; MOLEX-1X2_LOCK
JP1: PINHD-2X14/90; 2X14/90
S1: TL2285EE
U1, U2: ANALOG_DEVICES_INC_ADUM3154BRSZANALOG_DEVICES_INC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; ANALOG_DEVICES_INC_ADUM3154BRSZ_0
X1: AK500/2-H

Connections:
3.3V: J3.29
5V: J3.11
+24V: IC1.22 (+VIN1), IC1.23 (+VIN2), IC2.22 (+VIN1), IC2.23 (+VIN2), J2.4 (2), J2.5 (1), J2.9 (6), JP1.7, JP1.8, JP1.10, S1.3 (COMM_1)
AGND: C1.2, C3.2, IC2.16 (-VOUT), J2.3, J2.7 (8), J2.8 (7), J4.3, J4.4 (2), J4.8 (7), JP1.3, JP1.5, JP1.6, JP1.23, JP1.25, JP1.26, U1.11 (1_GND2), U1.19 (2_GND2), U2.11 (1_GND2), U2.19 (2_GND2)
CAN_CS: J3.40, J6.8
CAN_H: J4.5 (1), JP1.28
CAN_INT: J3.36, J6.4
CAN_L: J4.9 (6), JP1.27
CAN_MISO: J3.37, J6.5
CAN_MOSI: J3.38, J6.6
CAN_RESET: J3.39, J6.7
CAN_SCK: J3.35, J6.3
CS_0: JP1.19, U1.15 (SS0)
CS_1: JP1.20, U1.14 (SS1)
CS_2: JP1.17, U1.13 (SS2)
CS_3: JP1.18, U1.12 (SS3)
CS_4: JP1.14, U2.15 (SS0)
CS_5: JP1.11, U2.14 (SS1)
CS_6: JP1.12, U2.13 (SS2)
CS_7: JP1.9, U2.12 (SS3)
CS_B: J4.1 (5)
GND: C2.2, C4.2, IC1.16 (-VOUT), J1.9, J1.10, J3.12, J3.30, J5.2, J6.9, J6.10, J7.9, J7.10, U1.2 (1_GND1), U1.10 (2_GND1), U2.2 (1_GND1), U2.10 (2_GND1)
IN_1: J3.23, J7.1
IN_2: J3.24, J7.2
IN_3: J3.25, J7.3
IN_4: J3.26, J7.4
IN_5: J3.27, J7.5
IN_6: J3.28, J7.6
IN_7: J3.31, J7.7
IN_8: J3.32, J7.8
ISO_CS_0: J3.19, U1.6 (!MSS!)
ISO_CS_1: J3.13, U2.6 (!MSS!)
ISO_CS_MUX_0: J3.18, U1.7 (SSA0)
ISO_CS_MUX_1: J3.17, U1.8 (SSA1)
ISO_CS_MUX_2: J3.10, U2.7 (SSA0)
ISO_CS_MUX_3: J3.9, U2.8 (SSA1)
ISO_MISO_0: J3.20, U1.5 (MI)
ISO_MISO_1: J3.14, U2.5 (MI)
ISO_MOSI_0: J3.21, U1.4 (MO)
ISO_MOSI_1: J3.15, U2.4 (MO)
ISO_SCK_0: J3.22, U1.3 (MCLK)
ISO_SCK_1: J3.16, U2.3 (MCLK)
MISO: J4.6 (9)
MISO_0: JP1.22, U1.16 (SO)
MISO_1: JP1.13, U2.16 (SO)
MOSI: J4.7 (8)
MOSI_0: JP1.24, U1.17 (SI)
MOSI_1: JP1.15, U2.17 (SI)
unnamed: IC1.2 (-VIN1), IC1.3 (-VIN2), IC2.2 (-VIN1), IC2.3 (-VIN2), X1.2
unnamed: F1.1, X1.1
unnamed: F1.2, S1.2 (NO_1)
OUT_1: J1.1, J3.1
OUT_2: J1.2, J3.2
OUT_3: J1.3, J3.3
OUT_4: J1.4, J3.4
OUT_5: J1.5, J3.5
OUT_6: J1.6, J3.6
OUT_7: J1.7, J3.7
OUT_8: J1.8, J3.8
RX: J3.33, J6.1
SCK: J4.2 (4)
SCK_0: JP1.21, U1.18 (SCLK)
SCK_1: JP1.16, U2.18 (SCLK)
TX: J3.34, J6.2
VCC: C2.1, C4.1, IC1.14 (+VOUT), J1.11, J1.12, J5.1, J6.11, J6.12, J7.11, J7.12, U1.1 (VDD1), U2.1 (VDD1)
VCCA: C1.1, C3.1, IC2.14 (+VOUT), J2.1 (5), J2.2 (4), J2.6 (9), JP1.1, JP1.2, JP1.4, U1.20 (VDD2), U2.20 (VDD2)

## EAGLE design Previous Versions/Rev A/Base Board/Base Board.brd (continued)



Board: 2 copper layers, 126.4 x 106.7 mm, 25 parts (10 on the bottom side), 60 nets.

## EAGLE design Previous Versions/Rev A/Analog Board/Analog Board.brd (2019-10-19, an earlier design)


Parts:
C1, C4: 0.1uF; 0805_NOTHERMALS
C2, C3: 1uF; PANASONIC_B
H1, H2: MOUNT-PAD-ROUND3.0; 3,0-PAD
J1, J4: DB9FEMALE; DB9
J2, J3: 1-2834011-2; 128340112
JP1: JP2W
U1: MCP3202SN; SO-08
U2: MCP4822-E/SN; SOIC8-N_MC

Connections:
+24V: J1.1, J1.2, J1.6
AGND: C1.1, C2.-, C3.-, C4.1, J1.3, J1.7, J1.8, J4.2, J4.3, J4.7, U1.4 (VSS), U2.5 (~LDAC), U2.7 (VSS)
CAN_H: J4.1
CAN_L: J4.6
CS: J4.5, JP1.2
MISO: J4.9, U1.6 (DOUT)
MOSI: J4.8, U1.5 (DIN), U2.4 (SDI)
unnamed: JP1.3, U2.2 (~CS)
unnamed: JP1.1, U1.1 (!CS!/SHDN)
unnamed: J3.2, U2.8 (VOUTA)
unnamed: J3.1, U2.6 (~VOUTB)
unnamed: J2.1, U1.2 (CH0)
unnamed: J2.2, U1.3 (CH1)
SCK: J4.4, U1.7 (CLK), U2.3 (SCK)
VCCA: C1.2, C2.+, C3.+, C4.2, J1.4, J1.5, J1.9, U1.8 (VDD/VREF), U2.1 (VDD)


Board: 2 copper layers, 93.7 x 65.0 mm, 13 parts (0 on the bottom side), 13 nets.

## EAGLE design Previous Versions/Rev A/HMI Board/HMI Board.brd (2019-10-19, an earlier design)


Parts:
J1: 6_PIN_SERIAL_TARGETLOCK; 1X06_LOCK
LCD1: LCD-16X2SILK; LCD-16X2
LED1, LED2, LED3: LEDCHIP-LED0805; CHIP-LED0805
R1, R2, R3: 100E; 0805
R4, R102: 3386-P; 3386P
R100, R101, R103: 1k; 0805
S1, S2: MOMENTARY-SWITCH-SPST-SMD-5.2MM; TACTILE_SWITCH_SMD_5.2MM
U1: ARDUINOR3NODIM; ARDUINOR3-NODIM

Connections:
GND: J1.6 (GND), LCD1.3 (VO), LED1.C, LED2.C, LED3.C, R4.1, R100.2, R101.2, R102.1, R103.2, U1.GND, U1.GND1, U1.GND2
unnamed: LCD1.14 (DB7), U1.D5
unnamed: LCD1.13 (DB6), U1.D6
unnamed: LCD1.12 (DB5), U1.D7
unnamed: LCD1.11 (DB4), U1.D8
unnamed: LCD1.10 (DB3), U1.D9
unnamed: LCD1.9 (DB2), U1.D10
unnamed: LCD1.8 (DB1), U1.D11
unnamed: LCD1.7 (DB0), U1.D12
unnamed: R1.2, U1.D2
unnamed: LCD1.5 (R/W), U1.SDA
unnamed: LCD1.4 (RS), U1.SCL
unnamed: R4.2, U1.A0
unnamed: LED1.A, R1.1
unnamed: J1.3 (TXO), U1.A4 (A4/SDA)
unnamed: J1.2 (RXI), U1.A5 (A5/SCL)
unnamed: LED2.A, R2.1
unnamed: LED3.A, R3.1
unnamed: LCD1.2 (VDD), R102.2
unnamed: LCD1.16 (K), R103.1
unnamed: LCD1.6 (E), U1.D13
unnamed: R100.1, S2.3 (2), U1.D4
unnamed: R101.1, S1.3 (2), U1.D3
unnamed: R3.2, U1.D0
unnamed: R2.2, U1.D1
VCC: LCD1.1 (VSS), LCD1.15 (A), R4.3, R102.3, S1.1, S2.1, U1.3V
VIN: U1.VIN



Board: 2 copper layers, 80.3 x 53.4 mm, 16 parts (4 on the bottom side), 26 nets.

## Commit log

2019-10-19 REV A
    [Analog Board.brd, Analog Board.sch, Base Board.brd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]
2021-05-13 Updated for Rev D
    Files for Rev D Added along with Datasheets and Documentation
    [Analog Board.brd, Analog Board.sch, Base Board v4 v8.csv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]

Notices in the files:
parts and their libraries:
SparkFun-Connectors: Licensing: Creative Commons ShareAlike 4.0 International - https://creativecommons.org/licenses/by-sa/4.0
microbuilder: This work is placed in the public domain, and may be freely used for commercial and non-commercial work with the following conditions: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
